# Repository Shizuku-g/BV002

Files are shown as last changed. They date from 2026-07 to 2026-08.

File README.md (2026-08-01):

# BV001

Design by nerdqaxeplus2(https://github.com/shufps/qaxe), change the ASIC to 1 x BM1373 AA (6.1TH/s SHA256)

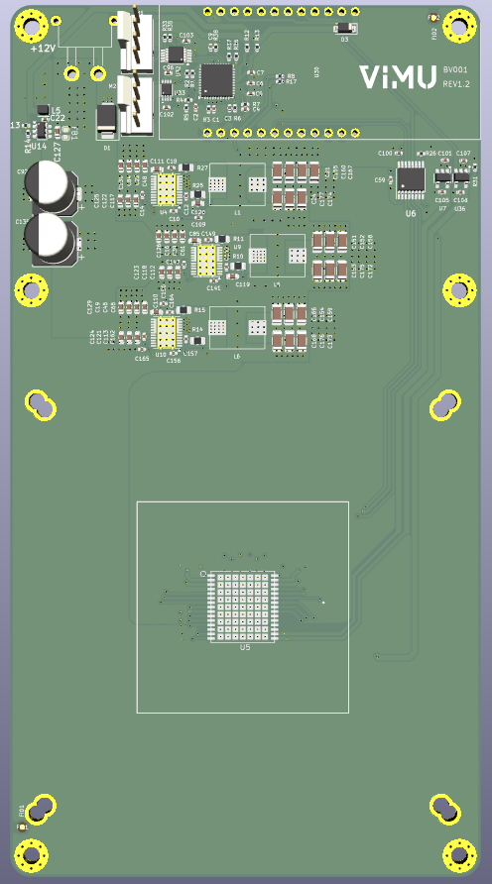
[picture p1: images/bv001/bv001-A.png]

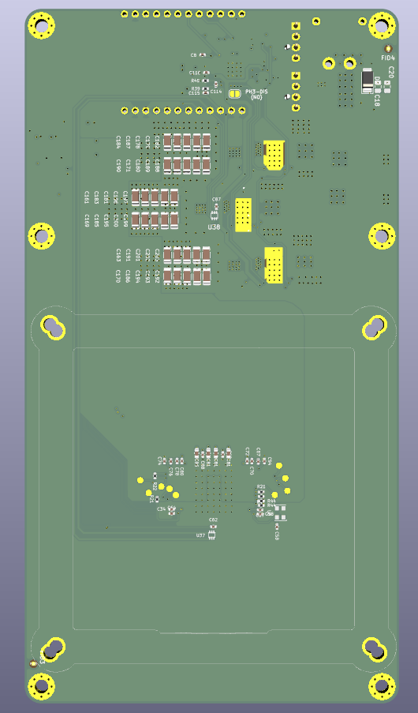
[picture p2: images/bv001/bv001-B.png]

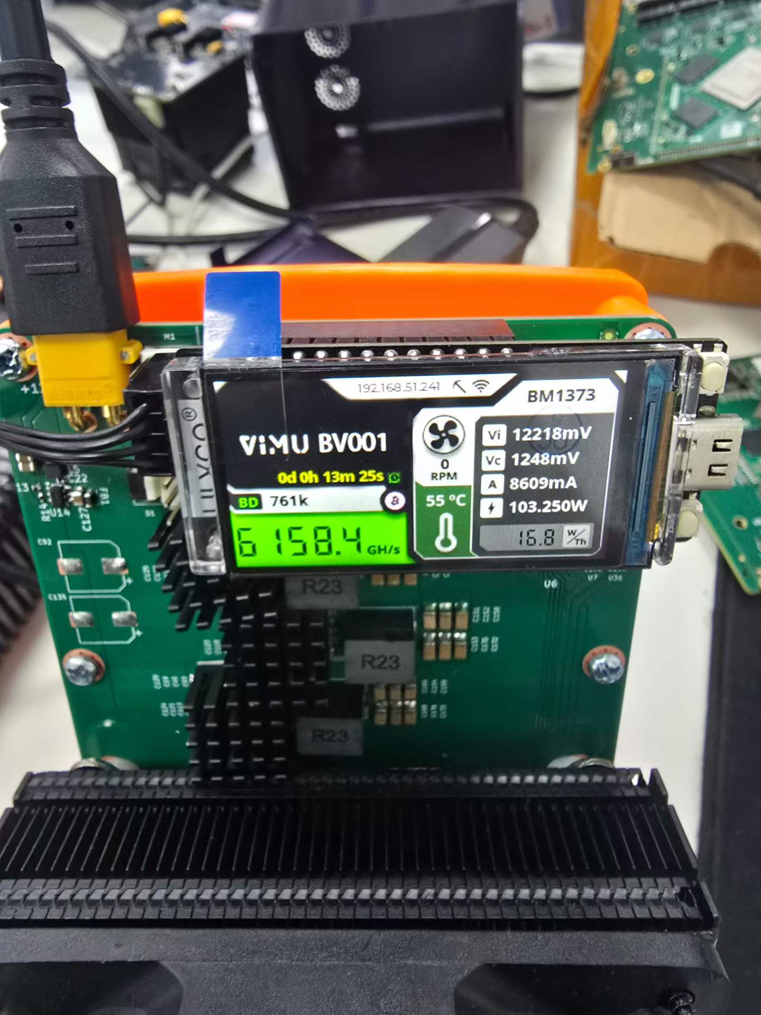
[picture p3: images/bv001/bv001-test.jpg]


Design tested and validated.  
Consume about 110 Watts on 12V for about 6.1TH/s (Vcore 1250mV, frequency 900Hz).  
Run at 735 MHz and 1140 mV, power wall around 78W, efficiency 14J/Th, 5TH/s.  
Use a 12V 15A PSU.

---

# BV002

**It is still an untested prototype! Don't build this expecting it to work at all.**

---

# BV003

**It is still an untested prototype! Don't build this expecting it to work at all.**

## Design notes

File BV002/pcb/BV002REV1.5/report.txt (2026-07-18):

信息: 正在处理符号 'C2:Capacitor_SMD:C_0603_1608Metric'。
信息: 正在处理符号 'C3:Capacitor_SMD:C_0603_1608Metric'。
信息: 正在处理符号 'C4:Capacitor_SMD:C_0402_1005Metric'。
信息: 正在处理符号 'C5:Capacitor_SMD:C_0402_1005Metric'。
信息: 正在处理符号 'C6:Capacitor_SMD:C_0402_1005Metric'。
信息: 正在处理符号 'C7:Capacitor_SMD:C_0402_1005Metric'。
信息: 正在处理符号 'C8:Capacitor_SMD:C_0805_2012Metric'。
信息: 正在处理符号 'C9:Capacitor_SMD:C_1206_3216Metric'。
信息: 正在处理符号 'C10:Capacitor_SMD:C_1206_3216Metric'。
信息: 正在处理符号 'C12:Capacitor_SMD:C_1206_3216Metric'。
信息: 正在处理符号 'C13:Capacitor_SMD:C_1206_3216Metric'。
信息: 正在处理符号 'C14:Capacitor_SMD:C_1206_3216Metric'。
信息: 正在处理符号 'C15:Capacitor_SMD:C_0402_1005Metric'。
信息: 正在处理符号 'C16:Capacitor_SMD:C_0402_1005Metric'。
信息: 正在处理符号 'C17:Capacitor_SMD:C_0402_1005Metric'。
信息: 正在处理符号 'C18:Capacitor_SMD:C_0402_1005Metric'。
信息: 正在处理符号 'C19:Capacitor_SMD:C_0402_1005Metric'。
信息: 正在处理符号 'C20:Capacitor_SMD:C_0402_1005Metric'。
信息: 正在处理符号 'C21:Capacitor_SMD:C_0402_1005Metric'。
信息: 正在处理符号 'C23:Capacitor_SMD:C_0402_1005Metric'。
信息: 正在处理符号 'C24:Capacitor_SMD:C_0603_1608Metric'。
信息: 正在处理符号 'C26:Capacitor_SMD:C_0603_1608Metric'。
信息: 正在处理符号 'C27:Capacitor_SMD:C_0402_1005Metric'。
信息: 正在处理符号 'C28:Capacitor_SMD:C_0402_1005Metric'。
信息: 正在处理符号 'C29:Capacitor_SMD:C_0402_1005Metric'。
信息: 正在处理符号 'C31:Capacitor_SMD:C_0402_1005Metric'。
信息: 正在处理符号 'C33:Capacitor_SMD:C_0402_1005Metric'。
信息: 正在处理符号 'C38:Capacitor_SMD:C_0402_1005Metric'。
信息: 正在处理符号 'C39:Capacitor_SMD:C_0402_1005Metric'。
信息: 正在处理符号 'C41:Capacitor_SMD:C_0805_2012Metric'。
信息: 正在处理符号 'C45:Capacitor_SMD:C_0402_1005Metric'。
信息: 正在处理符号 'C46:Capacitor_SMD:C_0402_1005Metric'。
信息: 正在处理符号 'C48:Capacitor_SMD:C_0402_1005Metric'。
信息: 正在处理符号 'C49:Capacitor_SMD:C_1206_3216Metric'。
信息: 正在处理符号 'C50:Capacitor_SMD:C_0402_1005Metric'。
信息: 正在处理符号 'C52:Capacitor_SMD:C_0402_1005Metric'。
信息: 正在处理符号 'C53:Capacitor_SMD:C_1206_3216Metric'。
信息: 正在处理符号 'C55:Capacitor_SMD:C_0402_1005Metric'。
信息: 正在处理符号 'C61:Capacitor_SMD:C_1206_3216Metric'。
信息: 正在处理符号 'C65:Capacitor_SMD:C_1206_3216Metric'。
信息: 正在处理符号 'C82:Capacitor_SMD:C_1206_3216Metric'。
信息: 正在处理符号 'C83:Capacitor_SMD:C_1206_3216Metric'。
信息: 正在处理符号 'C84:Capacitor_SMD:C_1206_3216Metric'。
信息: 正在处理符号 'C86:Capacitor_SMD:C_0402_1005Metric'。
信息: 正在处理符号 'C87:Capacitor_SMD:C_0402_1005Metric'。
信息: 正在处理符号 'C88:Capacitor_SMD:C_0402_1005Metric'。
信息: 正在处理符号 'C90:Capacitor_SMD:C_0402_1005Metric'。
信息: 正在处理符号 'C207:Capacitor_SMD:C_0402_1005Metric'。
信息: 正在处理符号 'D1:Diode_SMD:D_SMB'。
信息: 正在处理符号 'D3:Diode_SMD:D_SOD-123'。
信息: 正在处理符号 'H1:qaxe:MountingHole_3.2mm_M3_Pad_Via'。
信息: 正在处理符号 'H2:qaxe:MountingHole_3.2mm_M3_Pad_Via'。
信息: 正在处理符号 'H3:qaxe:MountingHole_3.2mm_M3_Pad_Via'。
信息: 正在处理符号 'H4:qaxe:MountingHole_3.2mm_M3_Pad_Via'。
信息: 正在处理符号 'H5:qaxe:MountingHole_3.2mm_M3_Pad_Via'。
信息: 正在处理符号 'H6:qaxe:MountingHole_3.2mm_M3_Pad_Via'。
信息: 正在处理符号 'J1:qaxe:XT30PW-M'。
信息: 正在处理符号 'L1:bitaxe:SLC1175-271MEC_COC'。
信息: 正在处理符号 'U1:bitaxe:polarity'。
信息: 正在处理符号 'C92:Capacitor_SMD:C_0402_1005Metric'。
信息: 正在处理符号 'L2:bitaxe:SLC1175-271MEC_COC'。
信息: 正在处理符号 'L4:Inductor_SMD:L_Changjiang_FTC201612S'。
信息: 正在处理符号 'M1:Connector:FanPinHeader_1x04_P2.54mm_Vertical'。
信息: 正在处理符号 'C94:Capacitor_SMD:C_0402_1005Metric'。
信息: 正在处理符号 'C96:Capacitor_SMD:C_0402_1005Metric'。
信息: 正在处理符号 'C98:Capacitor_SMD:C_0402_1005Metric'。
信息: 正在处理符号 'M2:Connector:FanPinHeader_1x04_P2.54mm_Vertical'。
信息: 正在处理符号 'NT1:bitaxe:NetTie-2_SMD_Pad0.2mmx1mm'。
信息: 正在处理符号 'NT2:bitaxe:NetTie-2_SMD_Pad0.2mmx1mm'。
信息: 正在处理符号 'C99:Capacitor_SMD:C_0402_1005Metric'。
信息: 正在处理符号 'C102:Capacitor_SMD:C_0402_1005Metric'。
信息: 正在处理符号 'C103:Capacitor_SMD:C_0402_1005Metric'。
信息: 正在处理符号 'C104:Capacitor_SMD:CP_Elec_6.3x5.9'。
信息: 正在处理符号 'C106:Capacitor_SMD:CP_Elec_6.3x5.9'。
信息: 正在处理符号 'C107:Capacitor_SMD:C_0402_1005Metric'。
信息: 正在处理符号 'R1:Resistor_SMD:R_0402_1005Metric'。
信息: 正在处理符号 'R2:Resistor_SMD:R_0805_2012Metric'。
信息: 正在处理符号 'C110:Capacitor_SMD:C_0603_1608Metric'。
信息: 正在处理符号 'C111:Capacitor_SMD:C_0603_1608Metric'。
信息: 正在处理符号 'C112:Capacitor_SMD:C_0603_1608Metric'。
信息: 正在处理符号 'C113:Capacitor_SMD:C_0603_1608Metric'。
信息: 正在处理符号 'C124:Capacitor_SMD:C_0603_1608Metric'。
信息: 正在处理符号 'C125:Capacitor_SMD:C_0603_1608Metric'。
信息: 正在处理符号 'C126:Capacitor_SMD:C_0603_1608Metric'。
信息: 正在处理符号 'C153:Capacitor_SMD:C_0402_1005Metric'。
信息: 正在处理符号 'R3:Resistor_SMD:R_0402_1005Metric'。
信息: 正在处理符号 'R5:Resistor_SMD:R_0402_1005Metric'。
信息: 正在处理符号 'R6:Resistor_SMD:R_0402_1005Metric'。
信息: 正在处理符号 'C155:Capacitor_SMD:C_0402_1005Metric'。
信息: 正在处理符号 'R8:Resistor_SMD:R_0402_1005Metric'。
信息: 正在处理符号 'R9:Resistor_SMD:R_0402_1005Metric'。
信息: 正在处理符号 'R10:Resistor_SMD:R_0402_1005Metric'。
信息: 正在处理符号 'C157:Capacitor_SMD:C_0402_1005Metric'。
信息: 正在处理符号 'R11:Resistor_SMD:R_0402_1005Metric'。
信息: 正在处理符号 'R12:Resistor_SMD:R_0402_1005Metric'。
信息: 正在处理符号 'C159:Capacitor_SMD:C_0402_1005Metric'。
信息: 正在处理符号 'R15:Resistor_SMD:R_0805_2012Metric'。
信息: 正在处理符号 'R17:Resistor_SMD:R_0402_1005Metric'。
信息: 正在处理符号 'R18:Resistor_SMD:R_0402_1005Metric'。
信息: 正在处理符号 'C161:Capacitor_SMD:C_0402_1005Metric'。
信息: 正在处理符号 'R23:Resistor_SMD:R_0402_1005Metric'。
信息: 正在处理符号 'R24:Resistor_SMD:R_0402_1005Metric'。
信息: 正在处理符号 'C163:Capacitor_SMD:C_0402_1005Metric'。
信息: 正在处理符号 'U2:Package_TO_SOT_SMD:SOT-583-8'。
信息: 正在处理符号 'R33:Resistor_SMD:R_0402_1005Metric'。
信息: 正在处理符号 'C164:Capacitor_SMD:C_0603_1608Metric'。
信息: 正在处理符号 'C165:Capacitor_SMD:C_0603_1608Metric'。
信息: 正在处理符号 'C167:Capacitor_SMD:C_0603_1608Metric'。
信息: 正在处理符号 'C168:Capacitor_SMD:C_0603_1608Metric'。
信息: 正在处理符号 'C171:Capacitor_SMD:C_0402_1005Metric'。
信息: 正在处理符号 'R25:Resistor_SMD:R_0402_1005Metric'。
信息: 正在处理符号 'R27:Resistor_SMD:R_0402_1005Metric'。
信息: 正在处理符号 'R28:Resistor_SMD:R_0402_1005Metric'。
信息: 正在处理符号 'C173:Capacitor_SMD:C_0603_1608Metric'。
信息: 正在处理符号 'C174:Capacitor_SMD:C_0603_1608Metric'。
信息: 正在处理符号 'C175:Capacitor_SMD:C_0603_1608Metric'。
信息: 正在处理符号 'C176:Capacitor_SMD:C_0603_1608Metric'。
信息: 正在处理符号 'C177:Capacitor_SMD:C_0402_1005Metric'。
信息: 正在处理符号 'R35:Resistor_SMD:R_0402_1005Metric'。
信息: 正在处理符号 'R43:Resistor_SMD:R_0402_1005Metric'。
信息: 正在处理符号 'R29:Resistor_SMD:R_0402_1005Metric'。
信息: 正在处理符号 'C178:Capacitor_SMD:C_0402_1005Metric'。
信息: 正在处理符号 'R30:Resistor_SMD:R_0402_1005Metric'。
信息: 正在处理符号 'U3:bitaxe:LQFN40-CLIP'。
信息: 正在处理符号 'U4:bitaxe:LQFN40-CLIP'。
信息: 正在处理符号 'C179:Capacitor_SMD:C_0402_1005Metric'。
信息: 正在处理符号 'C180:Capacitor_SMD:C_0402_1005Metric'。
信息: 正在处理符号 'C181:Capacitor_SMD:C_0402_1005Metric'。
信息: 正在处理符号 'C182:Capacitor_SMD:C_0402_1005Metric'。
信息: 正在处理符号 'C183:Capacitor_SMD:C_0402_1005Metric'。
信息: 正在处理符号 'R45:Resistor_SMD:R_0402_1005Metric'。
信息: 正在处理符号 'U5:Audio_Module:B1373CC'。
信息: 正在处理符号 'R46:Resistor_SMD:R_0402_1005Metric'。
信息: 正在处理符号 'C184:Capacitor_SMD:C_0402_1005Metric'。
信息: 正在处理符号 'R55:Resistor_SMD:R_0402_1005Metric'。
信息: 正在处理符号 'R56:Resistor_SMD:R_0402_1005Metric'。
信息: 正在处理符号 'R57:Resistor_SMD:R_0402_1005Metric'。
信息: 正在处理符号 'C185:Capacitor_SMD:C_0402_1005Metric'。
信息: 正在处理符号 'R58:Resistor_SMD:R_0402_1005Metric'。
信息: 正在处理符号 'R59:Resistor_SMD:R_0402_1005Metric'。
信息: 正在处理符号 'C186:Capacitor_SMD:C_0402_1005Metric'。
信息: 正在处理符号 'R60:Resistor_SMD:R_0402_1005Metric'。
信息: 正在处理符号 'R61:Resistor_SMD:R_0402_1005Metric'。
信息: 正在处理符号 'R31:Resistor_SMD:R_0402_1005Metric'。
信息: 正在处理符号 'C187:Capacitor_SMD:C_0402_1005Metric'。
信息: 正在处理符号 'C188:Capacitor_SMD:C_0402_1005Metric'。
信息: 正在处理符号 'C189:Capacitor_SMD:C_0402_1005Metric'。
信息: 正在处理符号 'C190:Capacitor_SMD:C_0402_1005Metric'。
信息: 正在处理符号 'C191:Capacitor_SMD:C_0402_1005Metric'。
信息: 正在处理符号 'C192:Capacitor_SMD:C_0402_1005Metric'。
信息: 正在处理符号 'C193:Capacitor_SMD:C_0402_1005Metric'。
信息: 正在处理符号 'C194:Capacitor_SMD:C_0402_1005Metric'。
信息: 正在处理符号 'C195:Capacitor_SMD:C_0402_1005Metric'。
信息: 正在处理符号 'R62:Resistor_SMD:R_0402_1005Metric'。
信息: 正在处理符号 'R63:Resistor_SMD:R_0402_1005Metric'。
信息: 正在处理符号 'R64:Resistor_SMD:R_0402_1005Metric'。
信息: 正在处理符号 'R65:Resistor_SMD:R_0402_1005Metric'。
信息: 正在处理符号 'R66:Resistor_SMD:R_0402_1005Metric'。
信息: 正在处理符号 'R67:Resistor_SMD:R_0402_1005Metric'。
信息: 正在处理符号 'R68:Resistor_SMD:R_0402_1005Metric'。
信息: 正在处理符号 'R69:Resistor_SMD:R_0402_1005Metric'。
信息: 正在处理符号 'R70:Resistor_SMD:R_0402_1005Metric'。
信息: 正在处理符号 'R71:Resistor_SMD:R_0402_1005Metric'。
信息: 正在处理符号 'R72:Resistor_SMD:R_0402_1005Metric'。
信息: 正在处理符号 'C206:Capacitor_SMD:C_0402_1005Metric'。
信息: 正在处理符号 'U6:Audio_Module:B1373CC'。
信息: 正在处理符号 'U7:Package_SO:TSSOP-16_4.4x5mm_P0.65mm'。
信息: 正在处理符号 'U8:Oscillator:Oscillator_SMD_EuroQuartz_XO32-4Pin_3.2x2.5mm'。
信息: 正在处理符号 'U9:Oscillator:Oscillator_SMD_EuroQuartz_XO32-4Pin_3.2x2.5mm'。
信息: 正在处理符号 'U10:Package_TO_SOT_SMD:SOT-23-5'。
信息: 正在处理符号 'U11:Package_TO_SOT_SMD:SOT-23-5'。
信息: 正在处理符号 'U12:Package_TO_SOT_SMD:SOT-23-5'。
信息: 正在处理符号 'U13:Package_TO_SOT_SMD:SOT-23-5'。
信息: 正在处理符号 'U17:Package_SO:TSSOP-14_4.4x5mm_P0.65mm'。
信息: 正在处理符号 'U30:myfootprints:T-Display-S3'。
信息: 正在处理符号 'U32:Package_SO:MSOP-10_3x3mm_P0.5mm'。
信息: 正在处理符号 'U33:Package_SO:VSSOP-8_2.3x2mm_P0.5mm'。
信息: 正在处理符号 'U37:qaxe:TMP1075-DRL'。
添加网络 Net-(U5-VDD2_0)。
将 C92 引脚 2 从 Net-(A1-VDD2_0) 重新连接到了 Net-(U5-VDD2_0)。
将 C98 引脚 1 从 Net-(A1-VDD2_0) 重新连接到了 Net-(U5-VDD2_0)。
添加网络 Net-(U5-VDD1_0)。
将 C98 引脚 2 从 Net-(A1-VDD3_0) 重新连接到了 Net-(U5-VDD1_0)。
将 C107 引脚 1 从 Net-(A1-VDD3_0) 重新连接到了 Net-(U5-VDD1_0)。
将 C107 引脚 2 从 GND_1 重新连接到了 GND。
将 C153 引脚 1 从 GND_1 重新连接到了 VDD。
添加网络 Net-(U6-VDD3_0)。
将 C153 引脚 2 从 Net-(A4-VDD1_0) 重新连接到了 Net-(U6-VDD3_0)。
添加网络 Net-(U6-VDD2_0)。
将 C155 引脚 2 从 Net-(A4-VDD2_0) 重新连接到了 Net-(U6-VDD2_0)。
将 C155 引脚 1 从 Net-(A4-VDD1_0) 重新连接到了 Net-(U6-VDD3_0)。
添加网络 Net-(U6-VDDIO_08_0)。
将 C157 引脚 1 从 /BM1366/0V8_1 重新连接到了 Net-(U6-VDDIO_08_0)。
添加网络 Net-(U6-VDD1_0)。
将 C159 引脚 2 从 Net-(A4-VDD3_0) 重新连接到了 Net-(U6-VDD1_0)。
将 C159 引脚 1 从 Net-(A4-VDD2_0) 重新连接到了 Net-(U6-VDD2_0)。
添加网络 Net-(U6-VDDIO_12_0)。
将 C161 引脚 1 从 1V2_1 重新连接到了 Net-(U6-VDDIO_12_0)。
将 C163 引脚 2 从 VDD 重新连接到了 GND。
将 C163 引脚 1 从 Net-(A4-VDD3_0) 重新连接到了 Net-(U6-VDD1_0)。
将 C171 引脚 1 从 VDD 重新连接到了 GND。
添加网络 Net-(U6-VDD1_1)。
将 C171 引脚 2 从 Net-(A4-VDD3_1) 重新连接到了 Net-(U6-VDD1_1)。
添加网络 Net-(U6-VDD2_1)。
将 C177 引脚 2 从 Net-(A4-VDD2_1) 重新连接到了 Net-(U6-VDD2_1)。
将 C177 引脚 1 从 Net-(A4-VDD3_1) 重新连接到了 Net-(U6-VDD1_1)。
将 C178 引脚 2 从 Net-(A3-VDD2_1) 重新连接到了 GND_1。
添加网络 Net-(U5-VDD3_1)。
将 C178 引脚 1 从 Net-(A3-VDD3_1) 重新连接到了 Net-(U5-VDD3_1)。
将 C183 引脚 1 从 Net-(A4-VDD2_1) 重新连接到了 Net-(U6-VDD2_1)。
添加网络 Net-(U6-VDD3_1)。
将 C183 引脚 2 从 Net-(A4-VDD1_1) 重新连接到了 Net-(U6-VDD3_1)。
添加网络 Net-(U5-VDD2_1)。
将 C184 引脚 1 从 Net-(A3-VDD2_1) 重新连接到了 Net-(U5-VDD2_1)。
将 C184 引脚 2 从 Net-(A3-VDD1_1) 重新连接到了 Net-(U5-VDD3_1)。
将 C185 引脚 2 从 GND_1 重新连接到了 VDD。
将 C185 引脚 1 从 Net-(A4-VDD1_1) 重新连接到了 Net-(U6-VDD3_1)。
添加网络 Net-(U5-VDD1_1)。
将 C186 引脚 1 从 Net-(A3-VDD1_1) 重新连接到了 Net-(U5-VDD1_1)。
将 C186 引脚 2 从 GND 重新连接到了 Net-(U5-VDD2_1)。
添加了 C195 (封装 'Capacitor_SMD:C_0402_1005Metric')。
已将 REF** 的位号更改为 C195。
已将 C195 的值从 'C_0402_1005Metric' 修改为 '1uF'。
将 C195 符号分配从  更新到 /4cf9c075-d009-4c35-9949-adda70ae20c7/5cac742f-71c1-4b5f-9255-c0933d732803。
已更新 C195 个字段。
已将 C195 图纸名称更新为 '/BM1366/'。
已将 C195 图纸文件更新为 'bm1366.kicad_sch'。
已将 C195 封装筛选规则更新为 'C_*'。
将 C195 引脚 1 连接到了 GND。
将 C195 引脚 2 连接到了 Net-(U5-VDD1_1)。
已更新 C195 单元的元数据。
已更新 L1 个字段。
添加网络 Net-(U6-RI)。
将 R24 引脚 1 从 Net-(A6-RI) 重新连接到了 Net-(U6-RI)。
添加网络 Net-(U5-LITE_PAD)。
将 R28 引脚 1 从 Net-(A1-LITE_PAD) 重新连接到了 Net-(U5-LITE_PAD)。
添加了 R30 (封装 'Resistor_SMD:R_0402_1005Metric')。
已将 REF** 的位号更改为 R30。
已将 R30 的值从 'R_0402_1005Metric' 修改为 '10k'。
将 R30 符号分配从  更新到 /4cf9c075-d009-4c35-9949-adda70ae20c7/908a538c-9adf-4183-acd7-97a39e0809e3。
已更新 R30 个字段。
已将 R30 图纸名称更新为 '/BM1366/'。
已将 R30 图纸文件更新为 'bm1366.kicad_sch'。
已将 R30 封装筛选规则更新为 'R_*'。
将 R30 引脚 2 连接到了 /BM1366/Level Shifter/NRSTI。
添加网络 Net-(R30-Pad1)。
将 R30 引脚 1 连接到了 Net-(R30-Pad1)。
已更新 R30 单元的元数据。
添加了 R31 (封装 'Resistor_SMD:R_0402_1005Metric')。
已将 REF** 的位号更改为 R31。
已将 R31 的值从 'R_0402_1005Metric' 修改为 '10k'。
将 R31 符号分配从  更新到 /4cf9c075-d009-4c35-9949-adda70ae20c7/2c4814b4-0640-43ad-82f6-ef1a9cbd42a7。
已更新 R31 个字段。
已将 R31 图纸名称更新为 '/BM1366/'。
已将 R31 图纸文件更新为 'bm1366.kicad_sch'。
已将 R31 封装筛选规则更新为 'R_*'。
添加网络 Net-(R31-Pad2)。
将 R31 引脚 2 连接到了 Net-(R31-Pad2)。
添加网络 /BM1366/NRSTO。
将 R31 引脚 1 连接到了 /BM1366/NRSTO。
已更新 R31 单元的元数据。
添加网络 Net-(U6-LITE_PAD)。
将 R43 引脚 1 从 Net-(A4-LITE_PAD) 重新连接到了 Net-(U6-LITE_PAD)。
将 R45 引脚 2 从 /BM1366/Level Shifter/NRSTI2 重新连接到了 /BM1366/NRSTO。
添加了 U5 (封装 'Audio_Module:B1373CC')。
已将 REF** 的位号更改为 U5。
已将 U5 的值从 'B1373CC' 修改为 '~'。
将 U5 符号分配从  更新到 /4cf9c075-d009-4c35-9949-adda70ae20c7/0b000a2c-9d47-4e33-ba98-7468ad7a44d6。
已将 U5 图纸名称更新为 '/BM1366/'。
已将 U5 图纸文件更新为 'bm1366.kicad_sch'。
将 U5 引脚 32 连接到了 GND。
将 U5 引脚 15 连接到了 1V2_0。
将 U5 引脚 32 连接到了 GND。
添加网络 unconnected-(U5-NC-Pad12)。
将 U5 引脚 12 连接到了 unconnected-(U5-NC-Pad12)。
将 U5 引脚 32 连接到了 GND。
将 U5 引脚 31 连接到了 GND_1。
将 U5 引脚 31 连接到了 GND_1。
将 U5 引脚 32 连接到了 GND。
将 U5 引脚 31 连接到了 GND_1。
将 U5 引脚 31 连接到了 GND_1。
将 U5 引脚 31 连接到了 GND_1。
将 U5 引脚 31 连接到了 GND_1。
添加网络 unconnected-(U5-PIN_MODE-Pad11)。
将 U5 引脚 11 连接到了 unconnected-(U5-PIN_MODE-Pad11)。
将 U5 引脚 31 连接到了 GND_1。
将 U5 引脚 31 连接到了 GND_1。
将 U5 引脚 32 连接到了 GND。
将 U5 引脚 32 连接到了 GND。
将 U5 引脚 31 连接到了 GND_1。
将 U5 引脚 31 连接到了 GND_1。
将 U5 引脚 31 连接到了 GND_1。
将 U5 引脚 32 连接到了 GND。
添加网络 unconnected-(U5-VSS-Pad4)。
将 U5 引脚 4 连接到了 unconnected-(U5-VSS-Pad4)。
将 U5 引脚 32 连接到了 GND。
将 U5 引脚 7 连接到了 /BM1366/RO。
将 U5 引脚 32 连接到了 GND。
将 U5 引脚 32 连接到了 GND。
将 U5 引脚 32 连接到了 GND。
添加网络 unconnected-(U5-NC-Pad19)。
将 U5 引脚 19 连接到了 unconnected-(U5-NC-Pad19)。
将 U5 引脚 28 连接到了 Net-(U5-VDD3_1)。
添加网络 unconnected-(U5-NC-Pad20)。
将 U5 引脚 20 连接到了 unconnected-(U5-NC-Pad20)。
将 U5 引脚 31 连接到了 GND_1。
将 U5 引脚 32 连接到了 GND。
将 U5 引脚 31 连接到了 GND_1。
将 U5 引脚 32 连接到了 GND。
将 U5 引脚 22 连接到了 /BM1366/Level Shifter/BI。
将 U5 引脚 32 连接到了 GND。
将 U5 引脚 29 连接到了 Net-(U5-VDD2_1)。
将 U5 引脚 31 连接到了 GND_1。
将 U5 引脚 32 连接到了 GND。
将 U5 引脚 32 连接到了 GND。
将 U5 引脚 31 连接到了 GND_1。
将 U5 引脚 32 连接到了 GND。
将 U5 引脚 31 连接到了 GND_1。
添加网络 unconnected-(U5-NC-Pad21)。
将 U5 引脚 21 连接到了 unconnected-(U5-NC-Pad21)。
将 U5 引脚 32 连接到了 GND。
将 U5 引脚 31 连接到了 GND_1。
将 U5 引脚 16 连接到了 1V2_0。
将 U5 引脚 31 连接到了 GND_1。
将 U5 引脚 31 连接到了 GND_1。
将 U5 引脚 8 连接到了 /BM1366/CLKI。
将 U5 引脚 13 连接到了 GND。
将 U5 引脚 31 连接到了 GND_1。
将 U5 引脚 32 连接到了 GND。
将 U5 引脚 32 连接到了 GND。
将 U5 引脚 6 连接到了 /BM1366/CI。
将 U5 引脚 32 连接到了 GND。
将 U5 引脚 31 连接到了 GND_1。
将 U5 引脚 23 连接到了 /BM1366/Level Shifter/CLKI。
将 U5 引脚 17 连接到了 /BM1366/0V8_0。
将 U5 引脚 32 连接到了 GND。
将 U5 引脚 31 连接到了 GND_1。
将 U5 引脚 31 连接到了 GND_1。
将 U5 引脚 31 连接到了 GND_1。
将 U5 引脚 32 连接到了 GND。
将 U5 引脚 26 连接到了 /BM1366/Level Shifter/NRSTI。
将 U5 引脚 31 连接到了 GND_1。
将 U5 引脚 32 连接到了 GND。
将 U5 引脚 3 连接到了 Net-(U5-VDD3_0)。
将 U5 引脚 32 连接到了 GND。
将 U5 引脚 32 连接到了 GND。
将 U5 引脚 31 连接到了 GND_1。
将 U5 引脚 27 连接到了 Net-(R30-Pad1)。
将 U5 引脚 14 连接到了 /BM1366/0V8_0。
将 U5 引脚 31 连接到了 GND_1。
将 U5 引脚 32 连接到了 GND。
将 U5 引脚 25 连接到了 /BM1366/Level Shifter/CI。
将 U5 引脚 1 连接到了 Net-(U5-VDD1_0)。
将 U5 引脚 32 连接到了 GND。
将 U5 引脚 31 连接到了 GND_1。
将 U5 引脚 31 连接到了 GND_1。
将 U5 引脚 32 连接到了 GND。
将 U5 引脚 32 连接到了 GND。
将 U5 引脚 9 连接到了 /BM1366/BI。
将 U5 引脚 31 连接到了 GND_1。
将 U5 引脚 24 连接到了 /BM1366/Level Shifter/RO。
将 U5 引脚 32 连接到了 GND。
将 U5 引脚 30 连接到了 Net-(U5-VDD1_1)。
将 U5 引脚 10 连接到了 Net-(U5-LITE_PAD)。
将 U5 引脚 2 连接到了 Net-(U5-VDD2_0)。
将 U5 引脚 5 连接到了 /BM1366/RST_N。
将 U5 引脚 32 连接到了 GND。
将 U5 引脚 31 连接到了 GND_1。
将 U5 引脚 18 连接到了 GND。
已更新 U5 单元的元数据。
添加了 C90 (封装 'Capacitor_SMD:C_0402_1005Metric')。
添加了 U6 (封装 'Audio_Module:B1373CC')。
已将 REF** 的位号更改为 U6。
已将 U6 的值从 'B1373CC' 修改为 '~'。
将 U6 符号分配从  更新到 /4cf9c075-d009-4c35-9949-adda70ae20c7/fd68f0f3-a1bd-4385-ae0e-bafe37af180e。
已将 U6 图纸名称更新为 '/BM1366/'。
已将 U6 图纸文件更新为 'bm1366.kicad_sch'。
将 U6 引脚 31 连接到了 VDD。
将 U6 引脚 29 连接到了 Net-(U6-VDD2_1)。
将 U6 引脚 31 连接到了 VDD。
将 U6 引脚 17 连接到了 /BM1366/0V8_1。
将 U6 引脚 16 连接到了 1V2_1。
添加网络 unconnected-(U6-RST-Pad26)。
将 U6 引脚 26 连接到了 unconnected-(U6-RST-Pad26)。
将 U6 引脚 1 连接到了 Net-(U6-VDD1_0)。
将 U6 引脚 32 连接到了 GND_1。
添加网络 unconnected-(U6-PIN_MODE-Pad11)。
将 U6 引脚 11 连接到了 unconnected-(U6-PIN_MODE-Pad11)。
将 U6 引脚 32 连接到了 GND_1。
将 U6 引脚 32 连接到了 GND_1。
将 U6 引脚 31 连接到了 VDD。
将 U6 引脚 32 连接到了 GND_1。
添加网络 unconnected-(U6-NC-Pad21)。
将 U6 引脚 21 连接到了 unconnected-(U6-NC-Pad21)。
将 U6 引脚 31 连接到了 VDD。
将 U6 引脚 32 连接到了 GND_1。
将 U6 引脚 32 连接到了 GND_1。
将 U6 引脚 32 连接到了 GND_1。
将 U6 引脚 32 连接到了 GND_1。
将 U6 引脚 31 连接到了 VDD。
将 U6 引脚 31 连接到了 VDD。
将 U6 引脚 32 连接到了 GND_1。
将 U6 引脚 10 连接到了 Net-(U6-LITE_PAD)。
将 U6 引脚 32 连接到了 GND_1。
将 U6 引脚 32 连接到了 GND_1。
添加网络 /BM1366/BO。
将 U6 引脚 9 连接到了 /BM1366/BO。
将 U6 引脚 32 连接到了 GND_1。
将 U6 引脚 32 连接到了 GND_1。
将 U6 引脚 5 连接到了 /BM1366/NRSTO。
将 U6 引脚 31 连接到了 VDD。
添加网络 unconnected-(U6-NC-Pad20)。
将 U6 引脚 20 连接到了 unconnected-(U6-NC-Pad20)。
将 U6 引脚 31 连接到了 VDD。
将 U6 引脚 31 连接到了 VDD。
将 U6 引脚 2 连接到了 Net-(U6-VDD2_0)。
将 U6 引脚 32 连接到了 GND_1。
添加网络 unconnected-(U6-NC-Pad12)。
将 U6 引脚 12 连接到了 unconnected-(U6-NC-Pad12)。
将 U6 引脚 31 连接到了 VDD。
将 U6 引脚 31 连接到了 VDD。
将 U6 引脚 31 连接到了 VDD。
将 U6 引脚 31 连接到了 VDD。
将 U6 引脚 32 连接到了 GND_1。
将 U6 引脚 32 连接到了 GND_1。
添加网络 unconnected-(U6-VSS-Pad27)。
将 U6 引脚 27 连接到了 unconnected-(U6-VSS-Pad27)。
将 U6 引脚 32 连接到了 GND_1。
将 U6 引脚 24 连接到了 Net-(U6-RI)。
将 U6 引脚 13 连接到了 GND_1。
将 U6 引脚 31 连接到了 VDD。
将 U6 引脚 32 连接到了 GND_1。
将 U6 引脚 32 连接到了 GND_1。
将 U6 引脚 31 连接到了 VDD。
将 U6 引脚 32 连接到了 GND_1。
将 U6 引脚 15 连接到了 Net-(U6-VDDIO_12_0)。
将 U6 引脚 31 连接到了 VDD。
添加网络 unconnected-(U6-NC-Pad19)。
将 U6 引脚 19 连接到了 unconnected-(U6-NC-Pad19)。
将 U6 引脚 32 连接到了 GND_1。
将 U6 引脚 31 连接到了 VDD。
将 U6 引脚 32 连接到了 GND_1。
将 U6 引脚 31 连接到了 VDD。
将 U6 引脚 32 连接到了 GND_1。
将 U6 引脚 14 连接到了 Net-(U6-VDDIO_08_0)。
将 U6 引脚 32 连接到了 GND_1。
添加网络 unconnected-(U6-BO-Pad22)。
将 U6 引脚 22 连接到了 unconnected-(U6-BO-Pad22)。
将 U6 引脚 31 连接到了 VDD。
将 U6 引脚 3 连接到了 Net-(U6-VDD3_0)。
将 U6 引脚 4 连接到了 Net-(R31-Pad2)。
添加网络 /BM1366/CLKO。
将 U6 引脚 8 连接到了 /BM1366/CLKO。
将 U6 引脚 32 连接到了 GND_1。
将 U6 引脚 32 连接到了 GND_1。
添加网络 unconnected-(U6-CLKO-Pad23)。
将 U6 引脚 23 连接到了 unconnected-(U6-CLKO-Pad23)。
添加网络 /BM1366/CO。
将 U6 引脚 6 连接到了 /BM1366/CO。
将 U6 引脚 32 连接到了 GND_1。
将 U6 引脚 31 连接到了 VDD。
将 U6 引脚 31 连接到了 VDD。
将 U6 引脚 30 连接到了 Net-(U6-VDD1_1)。
将 U6 引脚 31 连接到了 VDD。
将 U6 引脚 31 连接到了 VDD。
添加网络 /BM1366/RI。
将 U6 引脚 7 连接到了 /BM1366/RI。
将 U6 引脚 31 连接到了 VDD。
将 U6 引脚 18 连接到了 GND_1。
将 U6 引脚 31 连接到了 VDD。
将 U6 引脚 32 连接到了 GND_1。
将 U6 引脚 32 连接到了 GND_1。
将 U6 引脚 28 连接到了 Net-(U6-VDD3_1)。
将 U6 引脚 31 连接到了 VDD。
将 U6 引脚 32 连接到了 GND_1。
将 U6 引脚 31 连接到了 VDD。
将 U6 引脚 31 连接到了 VDD。
将 U6 引脚 31 连接到了 VDD。
将 U6 引脚 31 连接到了 VDD。
将 U6 引脚 32 连接到了 GND_1。
将 U6 引脚 32 连接到了 GND_1。
添加网络 unconnected-(U6-CO-Pad25)。
将 U6 引脚 25 连接到了 unconnected-(U6-CO-Pad25)。
将 U6 引脚 31 连接到了 VDD。
已更新 U6 单元的元数据。
已将 REF** 的位号更改为 C90。
已将 C90 的值从 'C_0402_1005Metric' 修改为 '1uF'。
将 C90 符号分配从  更新到 /4cf9c075-d009-4c35-9949-adda70ae20c7/64dd4181-b475-4721-92ac-613f6684715e。
已更新 C90 个字段。
已将 C90 图纸名称更新为 '/BM1366/'。
已将 C90 图纸文件更新为 'bm1366.kicad_sch'。
已将 C90 封装筛选规则更新为 'C_*'。
将 C90 引脚 1 连接到了 GND_1。
添加网络 Net-(U5-VDD3_0)。
将 C90 引脚 2 连接到了 Net-(U5-VDD3_0)。
已更新 C90 单元的元数据。
将 C92 引脚 1 从 Net-(A1-VDD1_0) 重新连接到了 Net-(U5-VDD3_0)。
将过孔从 Net-(A3-VDD1_1) 重新连接到了 Net-(U5-VDD1_1)。
将过孔从 Net-(A3-VDD2_1) 重新连接到了 Net-(U5-VDD2_1)。
将过孔从 Net-(A3-VDD3_1) 重新连接到了 Net-(U5-VDD3_1)。
将过孔从 Net-(A6-RI) 重新连接到了 Net-(U6-RI)。
将过孔从 Net-(A4-VDD1_0) 重新连接到了 Net-(U6-VDD3_0)。
将过孔从 Net-(A4-VDD2_0) 重新连接到了 Net-(U6-VDD2_0)。
将过孔从 Net-(A4-VDD3_0) 重新连接到了 Net-(U6-VDD1_0)。
将过孔从 Net-(A1-VDD3_0) 重新连接到了 Net-(U5-VDD1_0)。
将过孔从 Net-(A1-VDD2_0) 重新连接到了 Net-(U5-VDD2_0)。
将过孔从 Net-(A1-VDD1_0) 重新连接到了 Net-(U5-VDD3_0)。
将过孔从 Net-(A1-LITE_PAD) 重新连接到了 Net-(U5-LITE_PAD)。
将过孔从 Net-(A4-LITE_PAD) 重新连接到了 Net-(U6-LITE_PAD)。
将过孔从 Net-(A4-VDD1_1) 重新连接到了 Net-(U6-VDD3_1)。
将过孔从 Net-(A4-VDD2_1) 重新连接到了 Net-(U6-VDD2_1)。
将过孔从 Net-(A4-VDD3_1) 重新连接到了 Net-(U6-VDD1_1)。
移除未使用的网络 0V8。
移除未使用的网络 1V2。
移除未使用的网络 BI。
移除未使用的网络 BO。
移除未使用的网络 CI。
移除未使用的网络 CLK。
移除未使用的网络 CLKI。
移除未使用的网络 CO。
移除未使用的网络 NC。
移除未使用的网络 RI。
移除未使用的网络 RO。
移除未使用的网络 RST。
移除未使用的网络 RSTI。
移除未使用的网络 VDD1_0。
移除未使用的网络 VDD1_1。
移除未使用的网络 VDD2_0。
移除未使用的网络 VDD2_1。
移除未使用的网络 VDD3_0。
移除未使用的网络 VDD3_1。
警告: 过孔连接到未知网络 (Net-(A4-NRSTO))。
警告: 过孔连接到未知网络 (Net-(A3-LITE_PAD))。
警告: 过孔连接到未知网络 (Net-(A1-VDD3_1))。
警告: 过孔连接到未知网络 (Net-(A1-VDD2_1))。
警告: 过孔连接到未知网络 (Net-(A1-VDD1_1))。
警告: 过孔连接到未知网络 (Net-(A6-VDD3_0))。
警告: 过孔连接到未知网络 (Net-(A6-VDD2_0))。
警告: 过孔连接到未知网络 (Net-(A6-VDD1_0))。
警告: 过孔连接到未知网络 (Net-(A1-NRSTO))。
警告: 过孔连接到未知网络 (Net-(A6-LITE_PAD))。
错误: U7 的焊盘 17 在 Package_SO:TSSOP-16_4.4x5mm_P0.65mm 中未找到。

信息: 总计警告: 10, 错误: 1。

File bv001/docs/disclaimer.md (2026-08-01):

# BV001 免责声明

**请在使用、制造或修改 BV001 之前仔细阅读本文档。**

## 1. 无担保声明

BV001 为开源硬件设计，按 **「现状」（AS IS）** 提供，不提供任何明示或暗示的担保，包括但不限于：

- 适销性
- 特定用途适用性
- 不侵权
- 性能、算力、功耗或效率达到 README / 文档中所述数值

文档中的测试数据来自特定环境下的样机测试，仅供参考；实际结果会因元器件批次、组装质量、散热条件、电源品质及固件版本而有所不同。

## 2. 风险自负

制造、焊接、上电、调试及运行 BV001 的全部风险由使用者自行承担。包括但不限于：

- **人身伤害**：高温烫伤、工具操作不当等
- **财产损失**：元器件损坏、PCB 烧毁、电源或周边设备损坏
- **火灾风险**：大电流、散热不足或装配错误可能引发过热

使用者应具备相应的电子工程知识与操作经验。如无相关经验，请勿自行制造或上电测试。

## 3. 电气安全

- BV001 工作于 **12 V 大电流** 环境，请使用合格、足功率的电源（建议 12 V / 15 A）
- 上电前检查极性、短路及散热安装
- 请勿在无人看管的情况下长时间运行
- 建议在通风良好、非易燃环境中使用

## 4. 法律与合规

- **加密货币挖矿** 在部分国家或地区可能受到限制或禁止，使用者须自行了解并遵守当地法律法规
- 用电应符合当地电气安全规范；高负载长时间运行产生的电费由使用者自行承担
- 本项目不提供任何投资、收益或挖矿盈利方面的建议或保证

## 5. 第三方设计与知识产权

BV001 基于 [nerdqaxeplus2 / qaxe](https://github.com/shufps/qaxe) 修改而来。使用者须同时遵守：

- 本仓库的 [LICENSE](../../LICENSE)（GNU GPL v3）
- 上游项目及其依赖组件各自的许可条款

本项目的作者与贡献者不对因使用、修改或再分发本设计而产生的任何第三方知识产权纠纷负责。

## 6. 元器件与供应链

- BOM 中的供应商、料号仅供参考，不保证现货、价格或品质
- 元器件替代可能导致性能下降、不稳定或损坏，替代方案需自行评估
- BM1373 等专用芯片的获取与真伪鉴别由使用者自行负责

## 7. 固件与软件

固件、矿池配置及配套软件可能独立于硬件设计更新。作者不保证与所有固件版本兼容，也不对固件缺陷、网络连接或矿池服务中断负责。

## 8. 责任限制

在法律允许的最大范围内，BV001 的作者、贡献者及分发者不对因使用或无法使用本设计而导致的任何直接、间接、附带、特殊或 consequential 损害承担责任，包括但不限于数据丢失、设备损坏、业务中断或利润损失。

## 9. 接受条款

下载、复制、制造、修改或运行 BV001 即表示您已阅读、理解并同意本免责声明的全部内容。如不同意，请立即停止使用本设计及相关资料。

---

*最后更新：2026-08-01*

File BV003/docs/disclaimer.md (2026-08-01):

# BV003 免责声明

**请在使用、制造或修改 BV003 之前仔细阅读本文档。**

## ⚠ 特别警告：未验证原型

BV003 为 **未经实机验证的原型设计**。README 已明确说明：

> *It is still an untested prototype! Don't build this expecting it to work at all.*

**请勿投入量产或期望其直接可用。** 设计可能存在原理图错误、布局缺陷、电源/散热不足、ASIC 互联问题等，上电可能导致元器件损坏甚至安全隐患。如需可参考的成熟方案，请使用已验证的 **BV001**。

---

## 1. 无担保声明

BV003 为开源硬件设计，按 **「现状」（AS IS）** 提供，不提供任何明示或暗示的担保，包括但不限于：

- 适销性
- 特定用途适用性
- 不侵权
- 设计完整性、可制造性或可运行性
- 性能、算力、功耗或效率达到任何预期数值

本设计 **没有任何** 经过验证的测试数据；文档或原理图中的参数均不应被视为承诺。

## 2. 风险自负

制造、焊接、上电、调试及运行 BV003 的全部风险由使用者自行承担。包括但不限于：

- **人身伤害**：高温烫伤、工具操作不当等
- **财产损失**：元器件损坏、PCB 烧毁、电源或周边设备损坏；**原型设计导致的全板报废风险更高**
- **火灾风险**：大电流、散热不足、设计缺陷或装配错误可能引发过热

使用者应具备相应的电子工程知识与操作经验。如无相关经验，**请勿** 自行制造或上电测试。

## 3. 电气安全

- BV003 为多 ASIC、多相电源设计，预期工作于 **12 V 大电流** 环境，对电源与散热要求高于单芯片方案
- 上电前须自行完成设计审查、DRC/ERC 检查、短路与极性检查
- 首次上电建议使用限流电源，并在可监控环境下进行
- 请勿在无人看管的情况下长时间运行
- 建议在通风良好、非易燃环境中使用

## 4. 法律与合规

- **加密货币挖矿** 在部分国家或地区可能受到限制或禁止，使用者须自行了解并遵守当地法律法规
- 用电应符合当地电气安全规范；高负载长时间运行产生的电费由使用者自行承担
- 本项目不提供任何投资、收益或挖矿盈利方面的建议或保证

## 5. 第三方设计与知识产权

BV003 基于 [NerdOCTAXE-Gamma](https://github.com/Patsch91/NerdOCTAXE-Gamma) 修改而来。该项目本身源自 NerdQaxe 生态，采用 **CERN-OHL-S-2.0** 许可。使用者须同时遵守：

- 本仓库的 [LICENSE](../../LICENSE)（GNU GPL v3）
- [NerdOCTAXE-Gamma](https://github.com/Patsch91/NerdOCTAXE-Gamma) 及其上游（如 [NerdQAxe+](https://github.com/shufps/qaxe)、[ESP-Miner-NerdQAxe+](https://github.com/shufps/ESP-Miner-NerdQAxe-plus)）各自的许可条款

本项目的作者与贡献者不对因使用、修改或再分发本设计而产生的任何第三方知识产权纠纷负责。

## 6. 元器件与供应链

- BOM（如已提供）中的供应商、料号仅供参考，不保证现货、价格或品质
- 4× BM1373 及 TPS546 等关键器件成本与获取难度较高，替代可能导致严重不稳定
- 元器件替代需自行评估；**在未验证的设计上使用替代料风险极大**

## 7. 固件与软件

上游 [NerdOCTAXE-Gamma](https://github.com/Patsch91/NerdOCTAXE-Gamma) 使用修改版 [ESP-Miner-NerdQAxe+](https://github.com/shufps/ESP-Miner-NerdQAxe-plus)（AxeOS）。BV003 因 ASIC 型号与数量不同，**不能直接沿用上游固件**；多芯片驱动、W5500 网络等功能 **尚未验证**。作者不保证与任何固件版本兼容，也不对固件缺陷、网络连接或矿池服务中断负责。自行移植固件前须充分评估工作量与风险。

## 8. 责任限制

在法律允许的最大范围内，BV003 的作者、贡献者及分发者不对因使用或无法使用本设计而导致的任何直接、间接、附带、特殊或 consequential 损害承担责任，包括但不限于数据丢失、设备损坏、业务中断或利润损失。

## 9. 接受条款

下载、复制、制造、修改或运行 BV003 即表示您已阅读、理解并同意本免责声明的全部内容，**且充分知晓其为未验证原型**。如不同意，请立即停止使用本设计及相关资料。

---

*最后更新：2026-08-01*

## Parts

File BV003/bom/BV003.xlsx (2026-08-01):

编号 | 位号 | 封装 | 数量 | 名称 | 供应商
1 | R80, R84 | R_0402_1005Metric NC | 2
2 | R73, R92, R93, R104, R105, R111, R112, R126 | R_0402_1005Metric 0R | 8
3 | R88, R89, R94, R99, R100, R102, R109, R110, R115, R116, R118, R120, R131 | R_0402_1005Metric 10R | 13
4 | R95, R96, R97, R113, R114, R127, R128, R129, R130 | R_0402_1005Metric 49R9 | 9
5 | R132, R133 | R_0402_1005Metric 0.33k | 2
6 | R1, R2, R3, R4, R7, R8, R9, R11, R12, R13, R15, R16, R17, R19, R22, R25, R28, R32, R33, R34, R35, R36, R43, R46, R49, R52, R56, R57, R58, R59, R60, R61, R64, R67, R70, R74, R75, R76, R77, R78 | R_0402_1005Metric 1k | 40
7 | R39, R40, R41, R42 | R_0805_2012Metric 2.7k | 4
8 | R85 | R_0402_1005Metric 4.64k | 1
9 | R124 | R_0402_1005Metric 4.7k | 1
10 | R103, R106, R121, R122 | R_0402_1005Metric 5.11k | 4
11 | R87 | R_0402_1005Metric 5.36k | 1
12 | R86 | R_0402_1005Metric 8.25k | 1
13 | R5, R10, R14, R18, R20, R21, R23, R24, R26, R27, R29, R30, R31, R44, R45, R47, R48, R50, R51, R53, R54, R62, R63, R65, R66, R68, R69, R71, R72, R81, R98, R101, R117, R119, R123, R125, R134, R135 | R_0402_1005Metric 10k | 38
14 | R37, R38 | R_0805_2012Metric 10k | 2
15 | R108 | R_0805_2012Metric 11.5k | 1
16 | R55 | R_0402_1005Metric 12.4k | 1
17 | R88, R91 | R_0402_1005Metric 16.2k | 2
18 | R107 | R_0402_1005Metric 16.9k | 1
19 | R6 | R_0402_1005Metric 20k | 1
20 | R79, R83 | R_0402_1005Metric 21.5k | 2
21 | R90 | R_0402_1005Metric 84.5k | 1
22 | C22, C47, C70, C93, C137, C138, C183, C184 | C_0402_1005Metric 33pF/25v | 8
23 | C135, C136, C181, C182 | C_0402_1005Metric 1000pF/25v | 4
24 | C130, C207, C214, C216, C217 | C_0402_1005Metric 10nF/25v | 5
25 | C218 | C_0402_1005Metric 22nF/25v | 1
26 | C25,C27, C28, C50, C73, C96, C98, C107, C109, C132, C133, C134, C140 ,C141, C144, C179, C180, C187, C188, C205 | C_0402_1005Metric 100nF/50v | 20
27 | C2, C206, C209, C210, C211, C212, C213 | C_0603_1608Metric 100nF/50v | 7
28 | C4, C29, C53, C75, C100, C101, C103, C104, C105 | C_0805_2012Metric 100nF/50v | 9
29 | C5, C6, C7, C8, C9, C10, C11, C12, C13, C16, C17, C20, C21, C23, C24, C26, C30, C31, C32, C33, C34, C35, C36, C37, C38, C39, C42, C45, C46, C48, C49, C51, C52, C54, C55, C56, C57, C58, C59, C60, C61, C62, C65, C68, C69, C71, C72, C74, C76, C77, C78, C79, C80, C81, C82, C83, C84, C85, C88, C91, C92, C94, C95, C97, C99, C108, C110, C123, C125, C126, C128, C173, C174, C175, C176 | C_0402_1005Metric 1uF/25v | 75
30 | C146, C149, C191, C193 | C_0402_1005Metric 2.2uF/25v | 4
31 | C127, C129, C177, C178, C208 | C_0402_1005Metric 4.7uF/25v | 5
32 | C14, C15, C18, C19, C40, C41, C43, C44, C63, C64, C66, C67, C86, C87, C89, C90, C106, C118, C145, C215 | C_0603_1005Metric 10uF/50v | 20
33 | C54,C56,C57,C58,C59,C62,C63,C64,C66 | C_0805_2012Metric 10uf/50v | 9
34 | C1, C3 | C_1210_3225Metric 10uf/50v | 2
35 | C113, C114, C115, C116, C117, C119, C120, C121, C122, C124, C163, C164, C165, C166, C167, C168, C169, C170, C171, C172 | C_0805_2012Metric 22uF/50v | 20
36 | C131 | C_0805_2012Metric 22uF/16v | 1
37 | C139, C142, C143, C147, C148, C150, C151, C152, C153, C154, C155, C156, C185, C186, C189, C190, C192, C194, C195, C196, C197, C198, C199, C200 | C_1206_3216Metric 100uf/16v | 24
38 | C157, C159, C201, C202 | Conductive Polymer Aluminum Solid Capacitors CP_Elec_6.3x5.9 270uf/10v | 4
39 | FB4, FB5, FB6, FB7 | BLM21PG221SN1D | 4
40 | FB8 | BLM15AG121SN1D | 1
41 | FB9 | HH-1M1608-121JT | 1
42 | D1 | SMBJ18A | 1
43 | D2 | D_SOD-123,1N5819 | 1
44 | D3 | D_SOD-128,PMEG4030EP | 1
45 | L1 | L_Taiyo-Yuden_NR-50xx 4.7uh/2.3A | 1
46 | L2, L3, L4, L5 | SLC1175-30 150nH | 4
47 | U1, U6, U10, U14, U32 | Oscillator_SMD_Abracon_ASDMB-4Pin_3.2X2.5mm 25MHZ | 5
48 | U3, U9, U13, U17 | B1373CC | 4
49 | U5 | SN74AXC4T774 | 1
50 | U27 | SOT-23-6,AP3211 | 1
51 | U28, U29, U30, U31 | TPS546D24A | 4
52 | U20 | MSOP-10_3x3mm_P0.5mm,EMC2302-1 | 1
53 | U2, U7, U11, U15 | SOT-23-5,MCP1824T-1202E/OT | 4
54 | U4, U8, U12, U16 | SOT-23-5,MCP1824T-0802E | 4
55 | U30 | T-Display-S3 | 1
56 | U18, U25, U26 | TLV3544 | 3
57 | U22, U23, U24 | TMP1075 | 1
58 | U21 | TXU0102-DCU | 1
59 | U33 | W5500 | 1
60 | J1 | AMASS_XT60PW-M_1x02_P7.20mm_Horizonta | 1
61 | J7 | RJ45_Hanrun_HR911105A_Horizontal | 1
62 | J5,J6 | Conn_01x12-Socket | 2
63 | M1,M2 | Fan_4pin | 2

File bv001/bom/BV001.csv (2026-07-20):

编号 | 位号 | 封装 | 数量 | 名称 | 供应商编号
1 | , , , , , , , , , , , , , , , , |  | 17
2 | C1 | C_0402_1005Metric | 1 | 2.2nF
3 | C2, C4, C9, C18, C109, C149, C150, C164, C165 | C_0402_1005Metric | 9 | 1nF
4 | C3 | C_0402_1005Metric | 1 | 12pF
5 | C5 | C_0402_1005Metric | 1 | 330nF
6 | C6, C8, C34, C37, C58, C58, C64, C67, C70, C72, C74, C76, C78, C80, C94, C105, C108 | C_0402_1005Metric | 17 | 1µF
7 | C7 | C_0402_1005Metric | 1 | 4.7µF
8 | C10, C14, C87, C96, C101, C102, C103, C107, C141, C147, C156, C162 | C_0402_1005Metric | 12 | 100nF
9 | C12, C142, C157 | C_0402_1005Metric | 3 | 2.2µF
10 | C16, C19, C22, C39, C45, C48, C61, C65, C81, C81, C81, C84, C85, C86, C110, C111, C112, C113, C117, C118, C121, C122, C123, C124, C125, C126, C127, C129, C130 | C_0603_1608Metric | 29 | 10uF
11 | C21, C24, C151, C152, C153, C154, C155, C158, C159, C160, C161, C163, C166, C167, C168, C169, C170, C171, C172, C173, C174, C175, C176, C177, C178, C179, C180, C181, C182, C183, C184, C185, C186, C187, C188, C189, C190, C191, C192, C193, C194, C195, C196, C197, C199, C200, C201, C202, C203 | C_1206_3216Metric | 49 | 100µF
12 | C22 | C_0402_1005Metric | 1 | 10nf
13 | C59, C100 | C_0402_1005Metric | 2 | 0.1uF
14 | C62 | C_0402_1005Metric | 1 | 100nf
15 | C62 | C_0402_1005Metric | 1 | 100pF
16 | C88 | C_0402_1005Metric | 1 | 33pf
17 | C92, C135 | CP_Elec_8x10 | 2 | 220µF
18 | C114, C115, C116 | C_0402_1005Metric | 3 | 22pF
19 | C119, C120 | C_0603_1608Metric | 2 | 10µF
20 | D1 | D_SMB | 1 | 5KPxxA
21 | D2 | D_SOD-128 | 1 | ~
22 | D3 | D_SOD-123 | 1 | 1N5819
23 | FB1 | FB0603 | 1 | ~
24 | J1 | XT30PW-M | 1 | XT30
25 | L1, L5, L6 | IFLR-4031GC-01-8x10 | 3 | 220nH
26 | L5 | L_Changjiang_FTC201612S | 1 | 4.7uH
27 | M1, M2 | FanPinHeader_1x04_P2.54mm_Vertical | 2 | Fan_4pin
28 | R1 | R_0402_1005Metric | 1 | 16.5k
29 | R2 | R_0402_1005Metric | 1 | 24.3k
30 | R3 | R_0402_1005Metric | 1 | 66.5k
31 | R4 | R_0402_1005Metric | 1 | 100k
32 | R5 | R_0402_1005Metric | 1 | 121k
33 | R6 | R_0402_1005Metric | 1 | 8.06k
34 | R7 | R_0402_1005Metric | 1 | 2.55k
35 | R8, R17 | R_0402_1005Metric | 2 | 4.7k
36 | R10, R11, R14, R15, R25, R27 | R_0805_2012Metric | 6 | 1R/0.5w
37 | R12, R13 | R_0402_1005Metric | 2 | 2.2R
38 | R13 | R_0402_1005Metric | 1 | 84.5k
39 | R14 | R_0402_1005Metric | 1 | 16.2k
40 | R21, R21, R22, R31, R36, R37, R38 | R_0402_1005Metric | 7 | 10k
41 | R26 | R_0402_1005Metric | 1 | 20k
42 | R33, R35 | R_0402_1005Metric | 2 | 2.7k
43 | R39, R40 | R_0402_1005Metric | 2 | 100R
44 | R44, R44, R47 | R_0402_1005Metric | 3 | 1k
45 | U3 | Texas_RHA0040B_VQFN-40-1EP_6x6mm_P0.5mm_EP4.15x4.15mm_ThermalVias | 1 | TPS53647
46 | U4, U9, U10 | CSD95472-SON-5x6 | 3 | CSD95472Q5MC
47 | U5 | B1373CC | 1 | ~
48 | U6 | TSSOP-16_4.4x5mm_P0.65mm | 1 | SN74AVC4T774
49 | U7 | SOT-23-5 | 1 | MCP1824T-0802E
50 | U8 | Oscillator_SMD_EuroQuartz_XO32-4Pin_3.2x2.5mm | 1 | 25MHz
51 | U14 | SOT-23-6 | 1 | ~
52 | U30 | T-Display-S3 | 1 | T-Display-S3
53 | U32 | MSOP-10_3x3mm_P0.5mm | 1 | EMC2302-1
54 | U33 | VSSOP-8_2.3x2mm_P0.5mm | 1 | TXU0102-DCU
55 | U36 | SOT-23-5 | 1 | MCP1824T-1202E
56 | U37, U38 | TMP1075-DRL | 2 | TMP1075

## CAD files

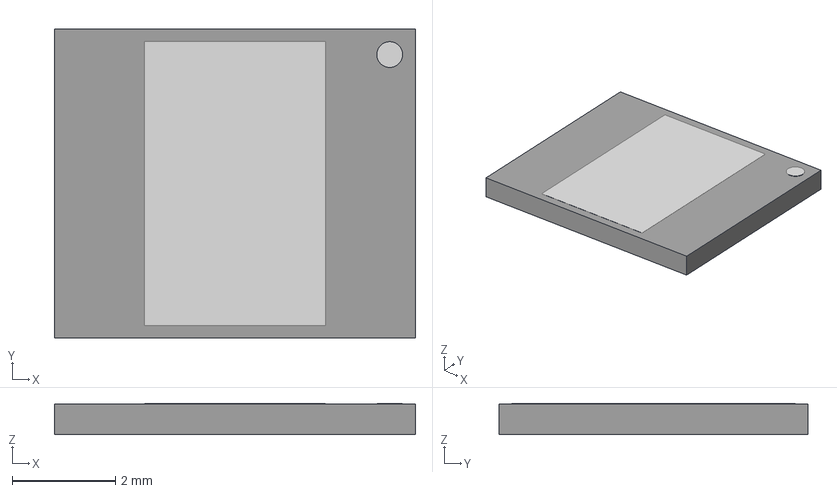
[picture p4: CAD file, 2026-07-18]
BV002/pcb/BV002REV1.5/3d/bm1366.step
7.00 x 6.00 x 0.61 mm

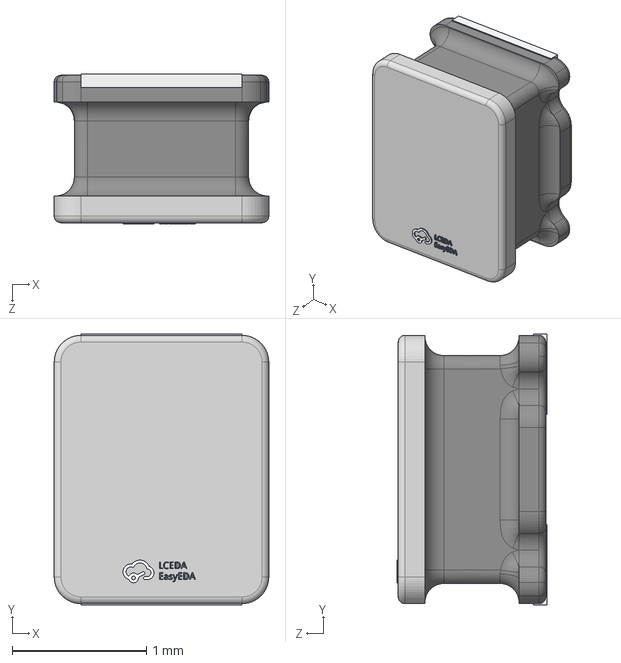
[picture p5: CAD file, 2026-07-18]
BV002/pcb/BV002REV1.5/3dshapes/IND-SMD_L2.0-W1.6-H1.1.step
1.60 x 2.02 x 1.12 mm

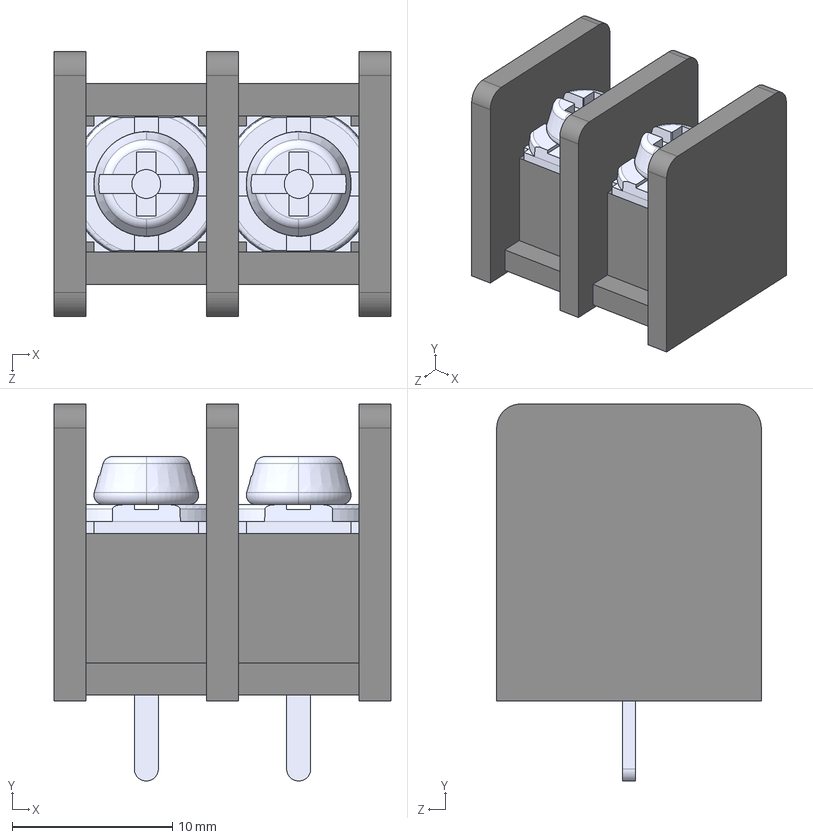
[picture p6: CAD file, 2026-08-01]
BV003/pcb/BV003REV1.0/3d/OSTYK51102030.STEP
21.0 x 23.5 x 16.5 mm

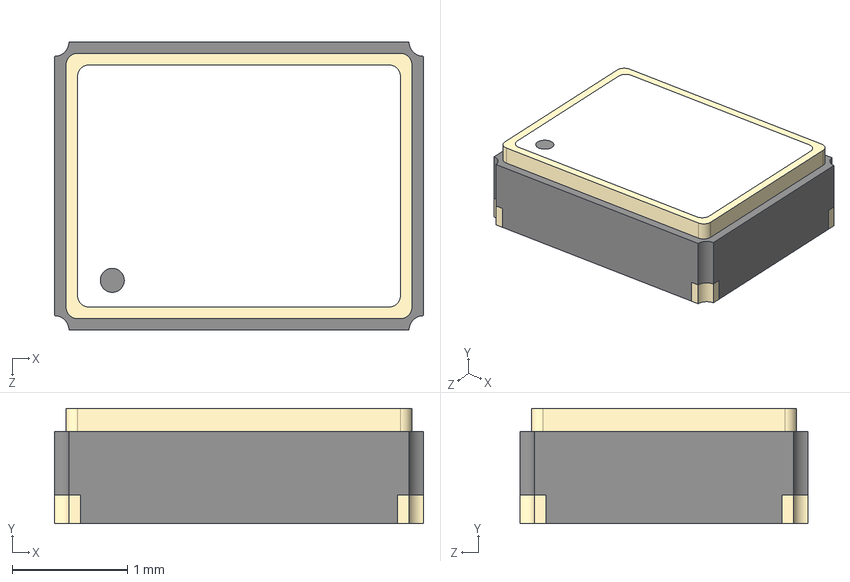
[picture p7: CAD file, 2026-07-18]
BV002/pcb/BV002REV1.5/3d/oscillator3.2x2.5.step
3.20 x 1.00 x 2.50 mm

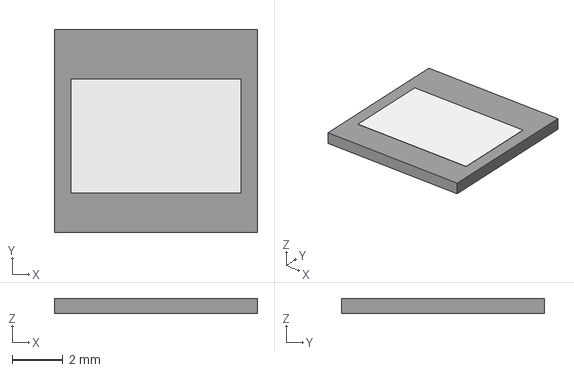
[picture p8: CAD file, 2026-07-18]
BV002/pcb/BV002REV1.5/3d/bm1370.step
8.00 x 8.00 x 0.61 mm

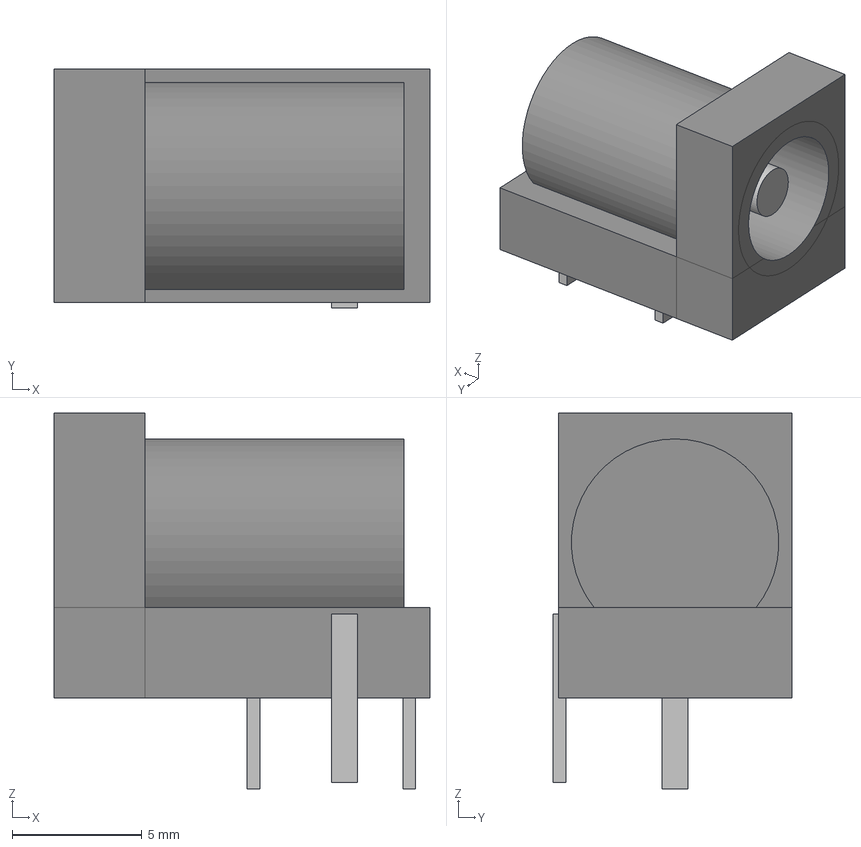
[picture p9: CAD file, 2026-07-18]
BV002/pcb/BV002REV1.5/3d/barrel-jack.step
14.5 x 9.20 x 14.5 mm

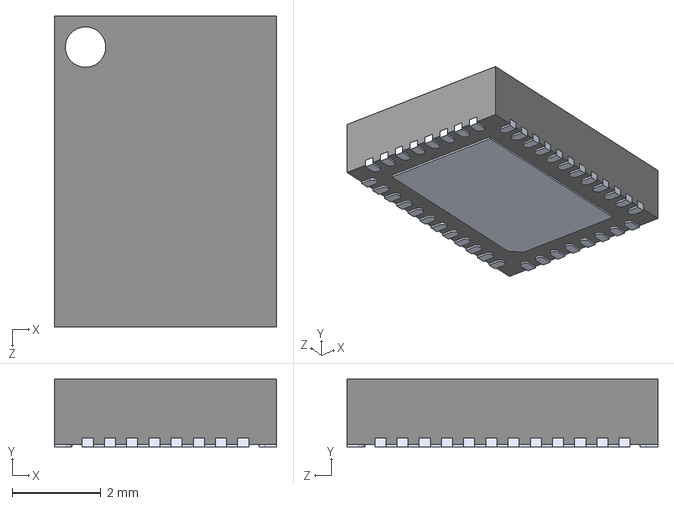
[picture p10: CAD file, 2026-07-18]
BV002/pcb/BV002REV1.5/3d/TPS546D24ARVFR.step
5.00 x 1.52 x 7.00 mm

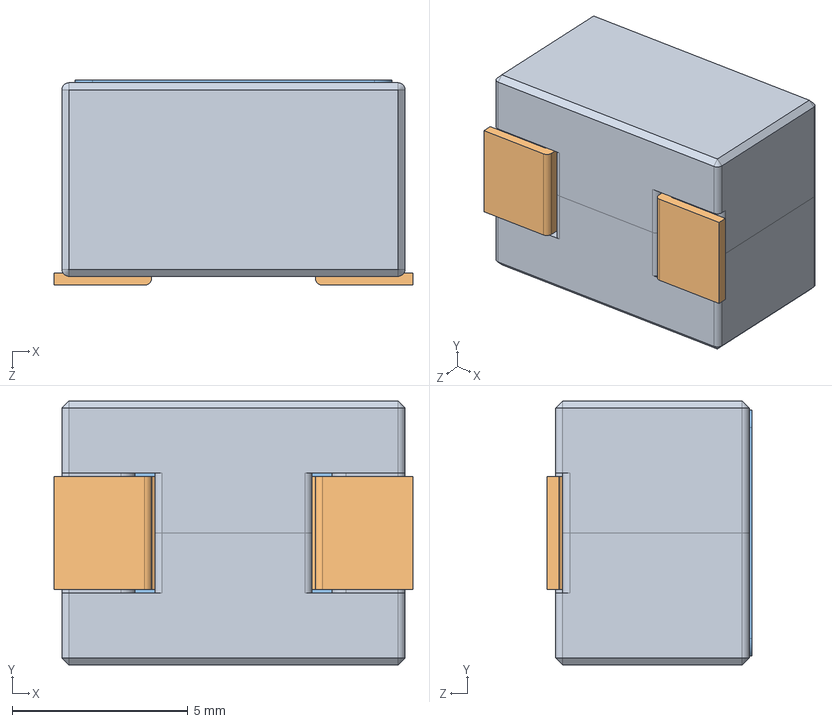
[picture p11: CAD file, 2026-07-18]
BV002/pcb/BV002REV1.5/3d/FP1006V2-R.STEP
10.2 x 7.50 x 5.83 mm
11150900A x 2
53134900A
Label for FP1006V2-R

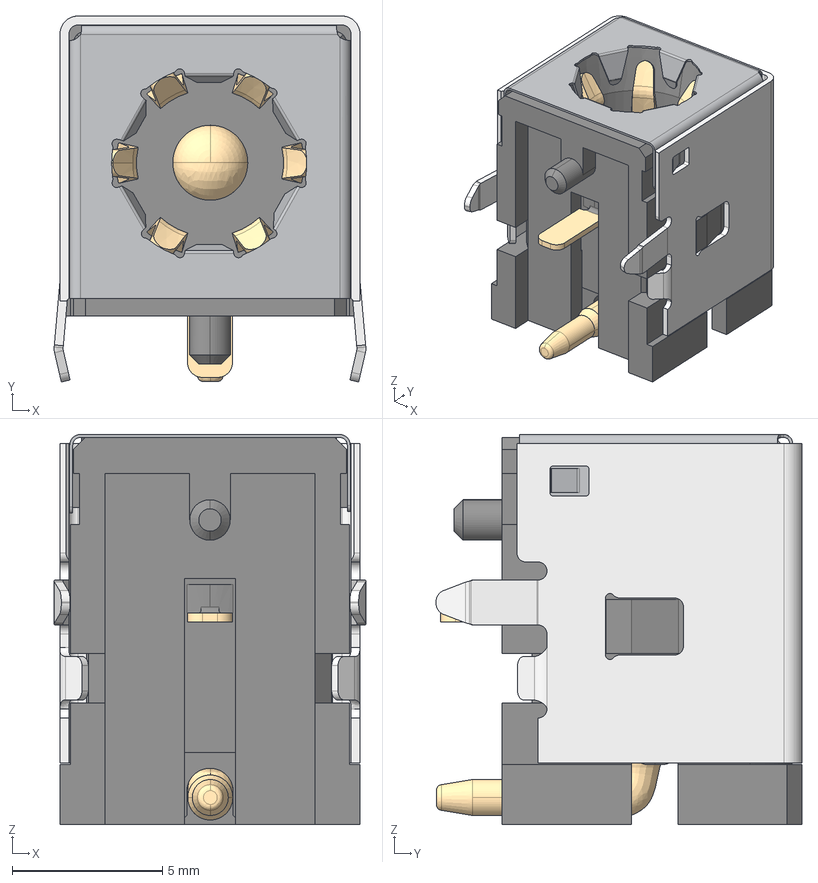
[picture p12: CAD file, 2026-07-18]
BV002/pcb/BV002REV1.5/3d/DCJ250-20-B-XX-X_REVA1.step
10.4 x 12.2 x 13.0 mm

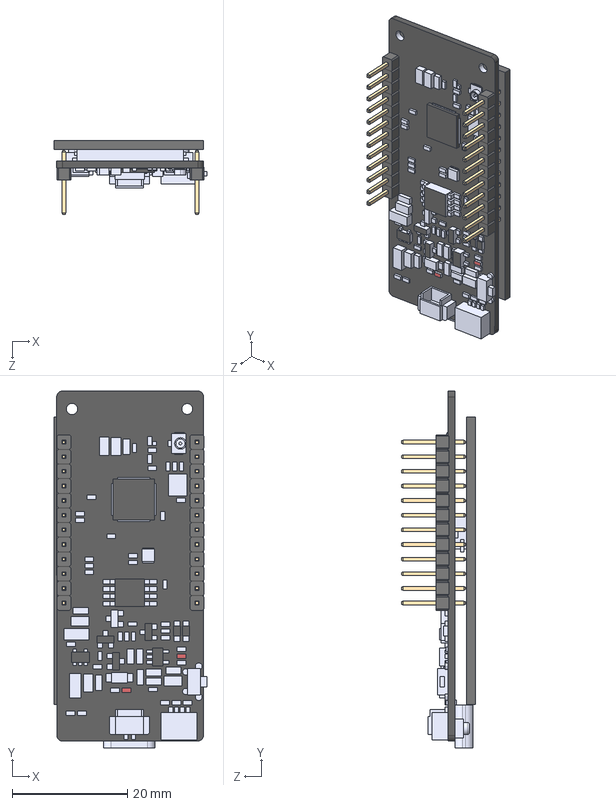
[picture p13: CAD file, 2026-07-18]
BV002/pcb/BV002REV1.5/3d/T-Display-S3.STEP
26.5 x 62.0 x 12.9 mm
MainBoard_3D
Ecran
1_Male_Pin_2.54_mm x 24

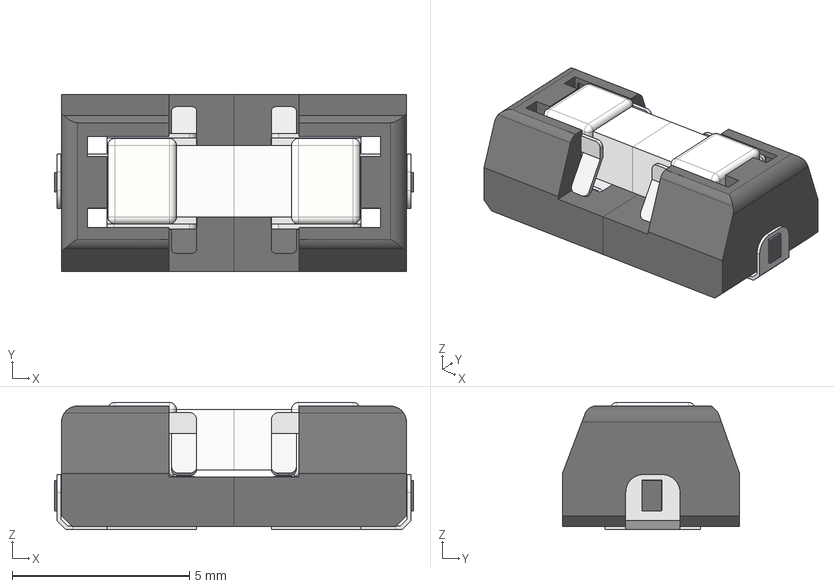
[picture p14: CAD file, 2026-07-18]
BV002/pcb/BV002REV1.5/3d/Littelfuse 0154.500DRT without value_black v2.step
10.1 x 5.00 x 3.59 mm
Komponente1
Komponente2
Komponente3
Komponente4

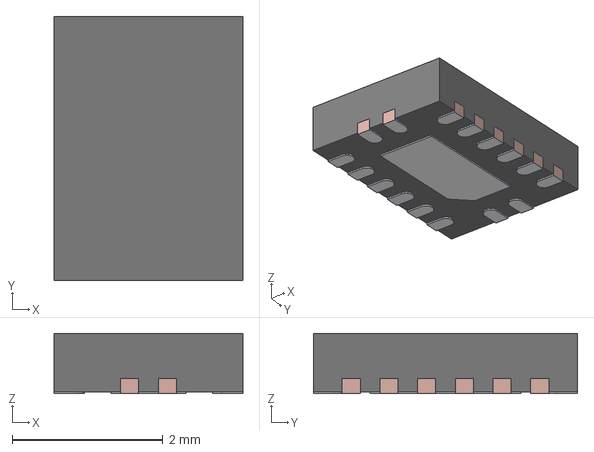
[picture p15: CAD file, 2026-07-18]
BV002/pcb/BV002REV1.5/3d/BQB0016A.stp
2.50 x 3.50 x 0.8 mm
FRAME

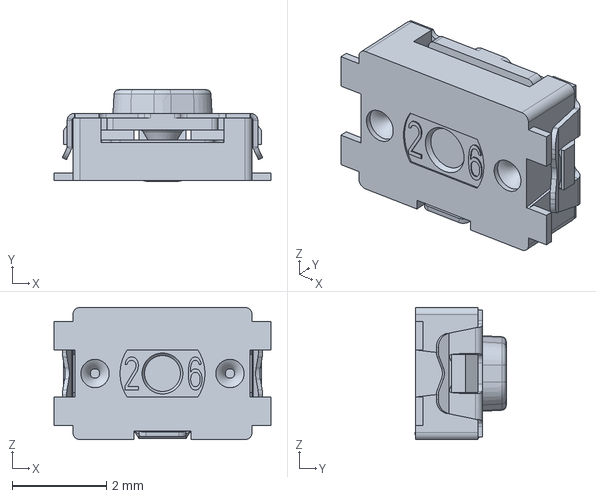
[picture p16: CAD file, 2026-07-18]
BV002/pcb/BV002REV1.5/3d/KMR231GLFS.stp
4.60 x 1.94 x 2.80 mm

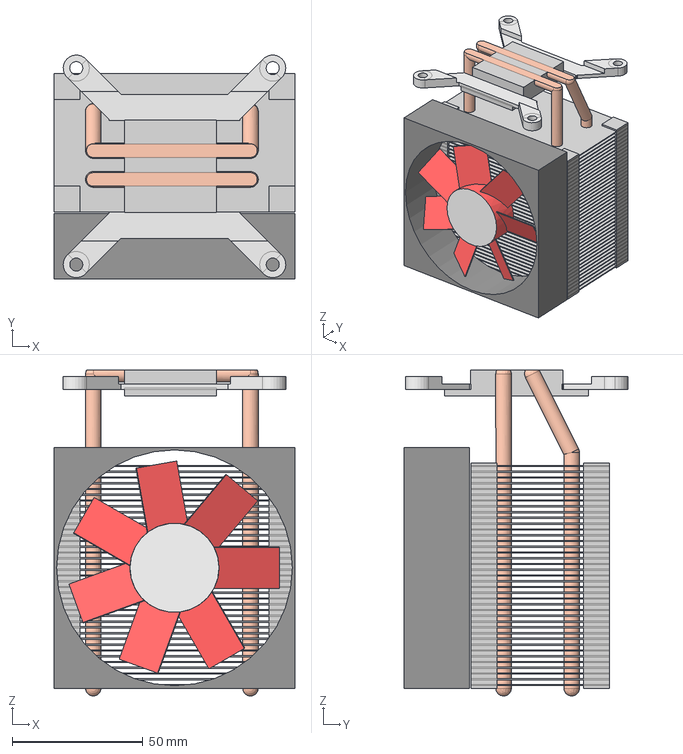
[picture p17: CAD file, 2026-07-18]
BV002/pcb/BV002REV1.5/3d/lga115x.step
92.0 x 85.5 x 124.5 mm

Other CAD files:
BV002/pcb/BV002REV1.5/3d/XT30PW-M.stp
BV002/pcb/BV002REV1.5/3d/SLC1175-271MEC_COC.step
BV002/pcb/BV002REV1.5/3d/heatsink-13x12x5.step
BV002/pcb/BV002REV1.5/3d/SIS0011A.stp
BV002/pcb/BV002REV1.5/3d/bm1370.scad
BV002/pcb/BV002REV1.5/3d/csd95472.scad
BV002/pcb/BV002REV1.5/3d/IND_VLS6045EX-4R7M_TDK.stl
BV002/pcb/BV002REV1.5/3d/csg95472.step

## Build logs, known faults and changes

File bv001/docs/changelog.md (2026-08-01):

# BV001 修订记录

本文档记录 BV001 硬件设计、BOM 及文档的变更历史。

## 格式说明

- **日期**：变更发布或验证日期
- **版本**：硬件或 BOM 版本标识（如有）
- **状态**：`已验证` / `待验证` / `已废弃`

---

## 2026-08-01 — 仓库结构整理

**状态**：已验证

- 调整仓库目录结构，BV001 资料归集至 `BV001/` 目录
- BOM 文件路径：`BV001/bom/BV001.csv`
- 新增 `BV001/docs/` 文档目录

---

## 2026-07-22 — 设计验证与性能数据发布

**状态**：已验证

- 完成实机测试，确认设计可用
- 记录两种典型运行工况：
  - **高性能**：900 MHz / Vcore 1250 mV，约 110 W @ 12 V，约 6.1 TH/s
  - **省电**：735 MHz / Vcore 1140 mV，墙插约 78 W，约 5 TH/s，效率约 14 J/TH
- 推荐电源：12 V / 15 A
- README 补充设计说明与测试照片

---

## 2026-07-21 — TMP1075 温度传感器修复

**状态**：已验证

- 修复 TMP1075（U37、U38）相关 PCB 布局/连接问题
- 温度读取功能恢复正常

---

## 2026-07-20 — 初始发布

**状态**：已验证

- 基于 [nerdqaxeplus2 / qaxe](https://github.com/shufps/qaxe) 改板
- 主要变更：ASIC 替换为 1× BM1373 AA（约 6.1 TH/s SHA256）
- 发布 KiCad 工程与 BOM

---

## 上游参考

BV001 衍生自开源项目 **nerdqaxeplus2 (qaxe)**。上游项目的修订历史请参阅其官方仓库。

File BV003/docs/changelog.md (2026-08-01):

# BV003 修订记录

本文档记录 BV003 硬件设计、BOM 及文档的变更历史。

## 格式说明

- **日期**：变更发布或验证日期
- **版本**：硬件或 BOM 版本标识（如有）
- **状态**：`已验证` / `待验证` / `已废弃`

---

## 2026-08-01 — BV003REV1.0 初始发布

**版本**：REV 1.0  
**状态**：待验证

> **警告：本版本为未验证原型，请勿期望直接可用。**

- 上传 KiCad 工程至 `BV003/pcb/BV003REV1.0/`
- 调整仓库目录结构，BV003 资料归集至 `BV003/` 目录
- 新增 `BV003/docs/` 文档目录

**设计概要（未经实机验证）：**

- 基于 [NerdOCTAXE-Gamma](https://github.com/Patsch91/NerdOCTAXE-Gamma)（8× BM1370 多 ASIC 矿机）改板
- 主要变更：ASIC 改为 4× BM1373；电源改为 TPS546 四相（上游 Rev3.4 为六相 Buck）
- 4× BM1373 ASIC（`bm1373_1` ~ `bm1373_4` 子图）
- TPS546 四相电源（`power.kicad_sch`）
- T-Display-S3 显示与控制
- W5500 以太网（`w5500.kicad_sch`）
- 电平转换（`level_shifter.kicad_sch`）

**已知限制：**

- 尚未完成打板、焊接或上电测试
- 无性能、功耗、散热数据
- BOM 可能尚未同步发布或完善
- KiCad 工程中 `plot` 路径预留了 REV1.1，后续改版待补充

---

## 与 BV001 / BV002 的关系

| 项目 | BV001 | BV002 | BV003 |
|---|---|---|---|
| 上游参考 | [qaxe](https://github.com/shufps/qaxe) | — | [NerdOCTAXE-Gamma](https://github.com/Patsch91/NerdOCTAXE-Gamma) |
| 验证状态 | 已验证 | 未验证原型 | 未验证原型 |
| ASIC 数量 | 1× BM1373 | 2× BM1373 | 4× BM1373 |
| 适用场景 | 可参考复刻 | 实验性设计 | 实验性设计 |

如需实际可用的参考设计，请优先参考 **BV001**。

---

## 上游参考

BV003 基于 **[NerdOCTAXE-Gamma](https://github.com/Patsch91/NerdOCTAXE-Gamma)** 修改而来。该项目是 8× BM1370 多 ASIC 矿机，源自 NerdQaxe 生态；当前上游版本为 Rev-3.4（六相 Buck、ASIC 内部温度读取等）。

BV003 相对上游的主要改动：

- ASIC：BM1370 × 8 → **BM1373 × 4**
- 电源：六相 Buck → **TPS546 四相**
- 其余模块（T-Display-S3、多 ASIC 互联架构等）沿用上游设计思路

上游修订历史请参阅 [NerdOCTAXE-Gamma 仓库](https://github.com/Patsch91/NerdOCTAXE-Gamma)。固件方面，上游使用修改版 [ESP-Miner-NerdQAxe+](https://github.com/shufps/ESP-Miner-NerdQAxe-plus)（AxeOS），BV003 移植适配 **尚未验证**。

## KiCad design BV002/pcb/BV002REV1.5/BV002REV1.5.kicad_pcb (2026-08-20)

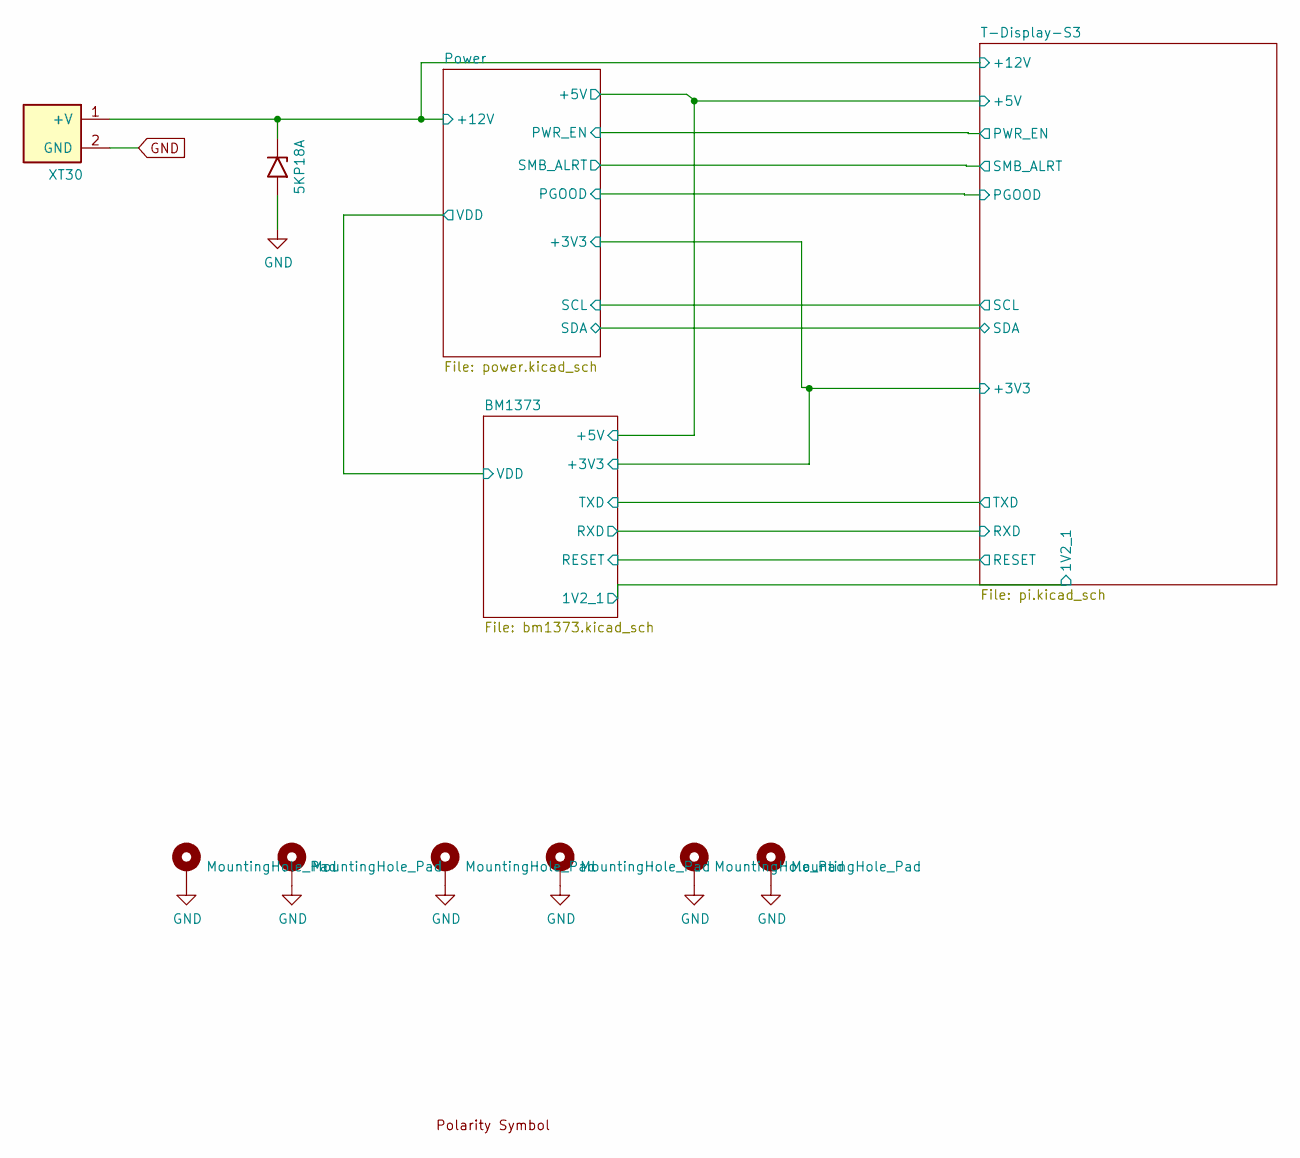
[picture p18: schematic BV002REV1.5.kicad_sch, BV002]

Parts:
D1: 5KP18A; D_SMB; PARTNO SMBJ12A; LCSC C3001973
H1, H2, H3, H4, H5, H6: MountingHole_Pad; MountingHole_3.2mm_M3_Pad_Via
J1: XT30; XT30PW-M; PARTNO XT30PW-M; LCSC C431092
U1: polarity

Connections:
+12V: D1.1 (A1), J1.1 (+V); also elsewhere on the board

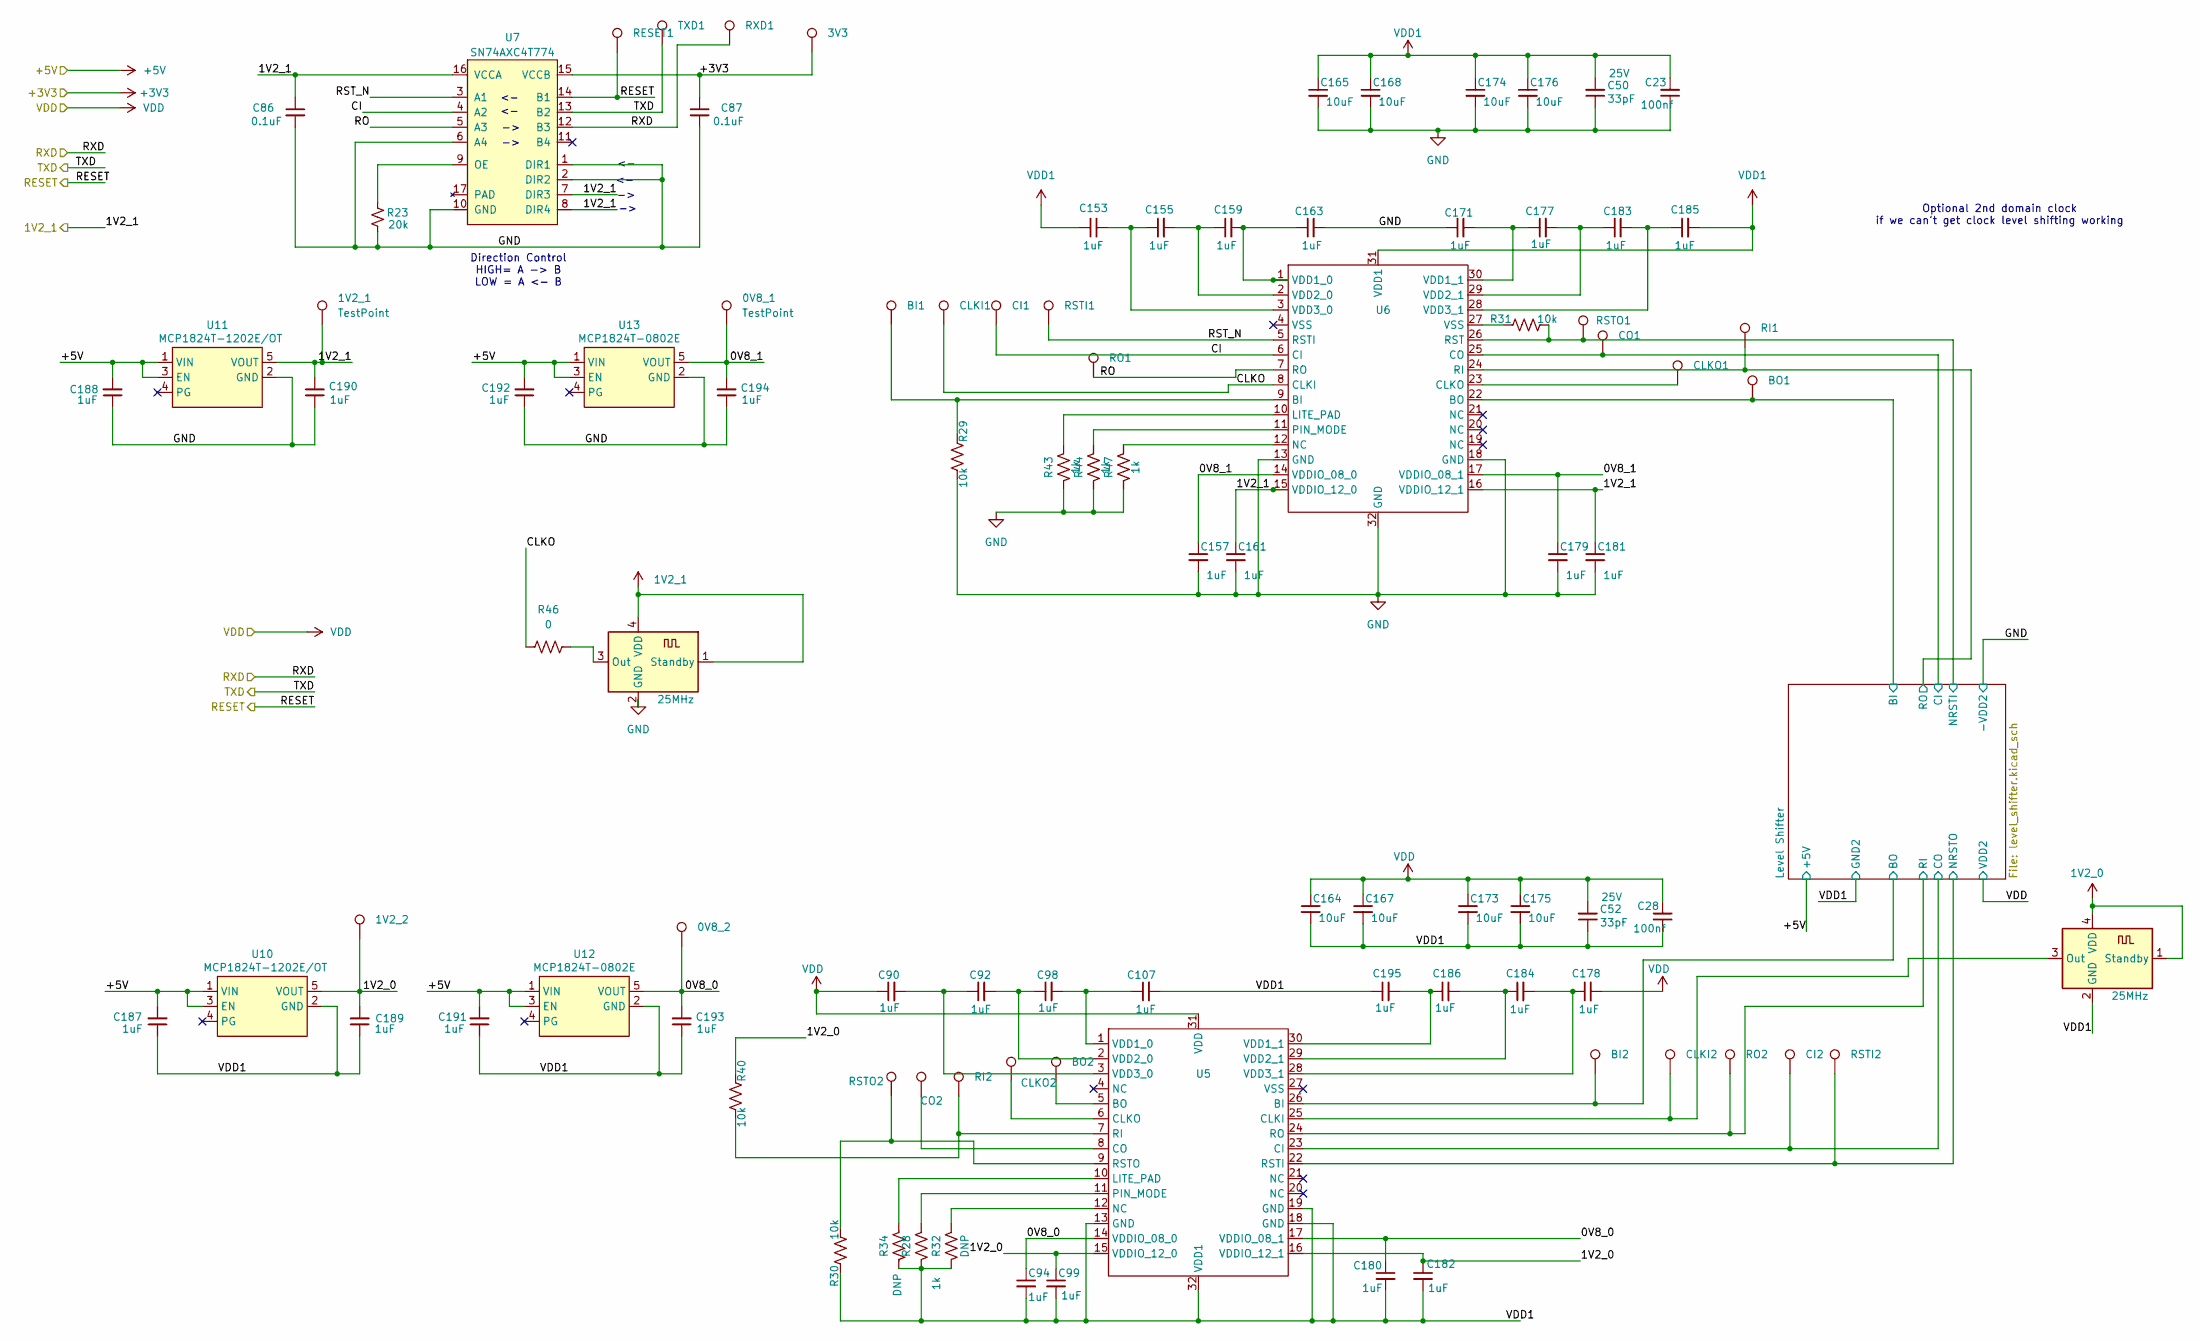
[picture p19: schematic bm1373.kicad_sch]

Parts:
0V8_1, 1V2_1: TestPoint; TestPoint_Pad_D1.5mm
0V8_2, 1V2_2, 3V3: TestPoint_Pad_D1.5mm
BI1, BI2: TestPoint_Pad_D1.5mm
BO1, BO2: TestPoint_Pad_D1.5mm
C23, C28: 100nf; C_0402_1005Metric; PARTNO GRM188R61E106KA73D
C50, C52: 33pF; C_0402_1005Metric; Voltage 25V; PARTNO KGM05ACG1E330JH
C86, C87: 0.1uF; C_0402_1005Metric; PARTNO KGM05AR71C104KH
C90, C92, C94, C98, C99, C107, C153, C155, C157, C159, C161, C163, C171, C177, C178, C179, C180, C181, C182, C183, C184, C185, C186, C195: 1uF; C_0402_1005Metric; PARTNO CL05A105KO5NNNC; LCSC C29266
C164, C165, C167, C168, C173, C174, C175, C176: 10uF; C_0603_1608Metric; PARTNO CL10A106MO8NQNC; LCSC C92487 Hot
C187, C188, C189, C190, C191, C192, C193, C194: 1uF; C_0402_1005Metric; PARTNO EMK105BJ105MV-F
CI1, CI2: TestPoint_Pad_D1.5mm
CLKI1, CLKI2: TestPoint_Pad_D1.5mm
CLKO1, CLKO2: TestPoint_Pad_D1.5mm
CO1, CO2: TestPoint_Pad_D1.5mm
R23: 20k; R_0402_1005Metric; PARTNO RC0402FR-0720KL
R28, R43, R44, R47: 1k; R_0402_1005Metric; PARTNO RC0402FR-071KL; LCSC C106235
R29, R30, R31, R40: 10k; R_0402_1005Metric; PARTNO RC0402DR-0710KL; LCSC C471764
R32, R34: DNP; R_0402_1005Metric; PARTNO RC0402FR-071KL; LCSC C106235
R46: 0; R_0402_1005Metric; PARTNO RC0402JR-070RL
RESET1: TestPoint_Pad_D1.5mm
RI1, RI2: TestPoint_Pad_D1.5mm
RO1, RO2: TestPoint_Pad_D1.5mm
RSTI1, RSTI2: TestPoint_Pad_D1.5mm
RSTO1, RSTO2: TestPoint_Pad_D1.5mm
RXD1: TestPoint_Pad_D1.5mm
TXD1: TestPoint_Pad_D1.5mm
U5, U6: B1373CC
U7: SN74AXC4T774; TSSOP-16_4.4x5mm_P0.65mm; PARTNO SN74AXC4T774BQBR
U8, U9: 25MHz; Oscillator_SMD_EuroQuartz_XO32-4Pin_3.2x2.5mm; PARTNO SX3M25.000E20F30THN
U10, U11: MCP1824T-1202E/OT; SOT-23-5; PARTNO MCP1824T-1202E/OT
U12, U13: MCP1824T-0802E; SOT-23-5; PARTNO MCP1824T-0802E/OT

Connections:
1V2_0: 1V2_2.1, C99.1, C182.1, C189.2, R40.1, U5.15 (VDDIO_12_0), U5.16 (VDDIO_12_1), U8.1 (Standby), U8.4 (VDD), U10.5 (VOUT)
1V2_1: 1V2_1.1, C86.1, C161.1, C181.1, C190.2, U6.15 (VDDIO_12_0), U6.16 (VDDIO_12_1), U7.7 (DIR3), U7.8 (DIR4), U7.16 (VCCA), U9.1 (Standby), U9.4 (VDD), U11.5 (VOUT); also elsewhere on the board
+5V: C187.2, C188.2, C191.2, C192.2, U10.1 (VIN), U10.3 (EN), U11.1 (VIN), U11.3 (EN), U12.1 (VIN), U12.3 (EN), U13.1 (VIN), U13.3 (EN); also elsewhere on the board
/BM1373/0V8_0: 0V8_2.1, C94.1, C180.1, C193.2, U5.14 (VDDIO_08_0), U5.17 (VDDIO_08_1), U12.5 (VOUT)
/BM1373/0V8_1: 0V8_1.1, C157.1, C179.1, C194.2, U6.14 (VDDIO_08_0), U6.17 (VDDIO_08_1), U13.5 (VOUT)
/BM1373/CI: CI1.1 (1_1), U6.6 (CI), U7.4 (A2)
/BM1373/CLKO: CLKI1.1 (1_1), R46.1, U6.8 (CLKI)
/BM1373/Level Shifter/BI: BO1.1 (1_1), U6.22 (BO); also elsewhere on the board
/BM1373/Level Shifter/BI2: BI2.1 (1_1), U5.26 (BI); also elsewhere on the board
/BM1373/Level Shifter/CI: CO1.1 (1_1), U6.25 (CO); also elsewhere on the board
/BM1373/Level Shifter/CI2: CI2.1 (1_1), U5.23 (CI); also elsewhere on the board
/BM1373/Level Shifter/NRSTI: R31.2, RSTO1.1 (1_1), U6.26 (RST); also elsewhere on the board
/BM1373/Level Shifter/NRSTI2: RSTI2.1 (1_1), U5.22 (RSTI); also elsewhere on the board
/BM1373/Level Shifter/RO: RI1.1 (1_1), U6.24 (RI); also elsewhere on the board
/BM1373/Level Shifter/RO2: RO2.1 (1_1), U5.24 (RO); also elsewhere on the board
/BM1373/RESET: RESET1.1 (1_1), U7.14 (B1); also elsewhere on the board
/BM1373/RO: RO1.1 (1_1), U6.7 (RO), U7.5 (A3)
/BM1373/RST_N: RSTI1.1 (1_1), U6.5 (RSTI), U7.3 (A1)
/BM1373/RXD: RXD1.1 (1_1), U7.12 (B3); also elsewhere on the board
/BM1373/TXD: TXD1.1 (1_1), U7.13 (B2); also elsewhere on the board
unnamed: R31.1, U6.27 (VSS)
unnamed: R32.1, U5.12 (NC)
unnamed: R47.1, U6.12 (NC)
unnamed: BO2.1 (1_1), U5.5 (BO)
unnamed: CLKI2.1 (1_1), U5.25 (CLKI), U8.3 (Out)
unnamed: CLKO2.1 (1_1), U5.6 (CLKO)
unnamed: CO2.1 (1_1), U5.8 (CO)
unnamed: R34.1, U5.10 (LITE_PAD)
unnamed: R28.1, U5.11 (PIN_MODE)
unnamed: R40.2, RI2.1 (1_1), U5.7 (RI)
unnamed: R30.2, RSTO2.1 (1_1), U5.9 (RSTO)
unnamed: C98.2, C107.1, U5.1 (VDD1_0)
unnamed: C186.1, C195.2, U5.30 (VDD1_1)
unnamed: C92.2, C98.1, U5.2 (VDD2_0)
unnamed: C184.1, C186.2, U5.29 (VDD2_1)
unnamed: C90.2, C92.1, U5.3 (VDD3_0)
unnamed: C178.1, C184.2, U5.28 (VDD3_1)
unnamed: BI1.1 (1_1), R29.1, U6.9 (BI)
unnamed: CLKO1.1 (1_1), U6.23 (CLKO)
unnamed: R43.1, U6.10 (LITE_PAD)
unnamed: R44.1, U6.11 (PIN_MODE)
unnamed: C159.2, C163.1, U6.1 (VDD1_0)
unnamed: C171.2, C177.1, U6.30 (VDD1_1)
unnamed: C155.2, C159.1, U6.2 (VDD2_0)
unnamed: C177.2, C183.1, U6.29 (VDD2_1)
unnamed: C153.2, C155.1, U6.3 (VDD3_0)
unnamed: C183.2, C185.1, U6.28 (VDD3_1)
unnamed: R23.2, U7.9 (OE)
unnamed: R46.2, U9.3 (Out)
VDD: C28.2, C52.2, C90.1, C164.1, C167.1, C173.1, C175.1, C178.2, U5.31 (VDD); also elsewhere on the board
VDD1: C23.2, C28.1, C50.2, C52.1, C94.2, C99.2, C107.2, C153.1, C164.2, C165.1, C167.2, C168.1, C173.2, C174.1, C175.2, C176.1, C180.2, C182.2, C185.2, C187.1, C189.1, C191.1, C193.1, C195.1, R28.2, R30.1, R32.2, R34.2, U5.13 (GND), U5.18 (GND), U5.19 (GND), U5.32 (VDD1), U6.31 (VDD1), U8.2 (GND), U10.2 (GND), U12.2 (GND); also elsewhere on the board

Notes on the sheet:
Optional 2nd domain clock if we can't get clock level shifting working
Direction Control HIGH= A -> B LOW = A <- B

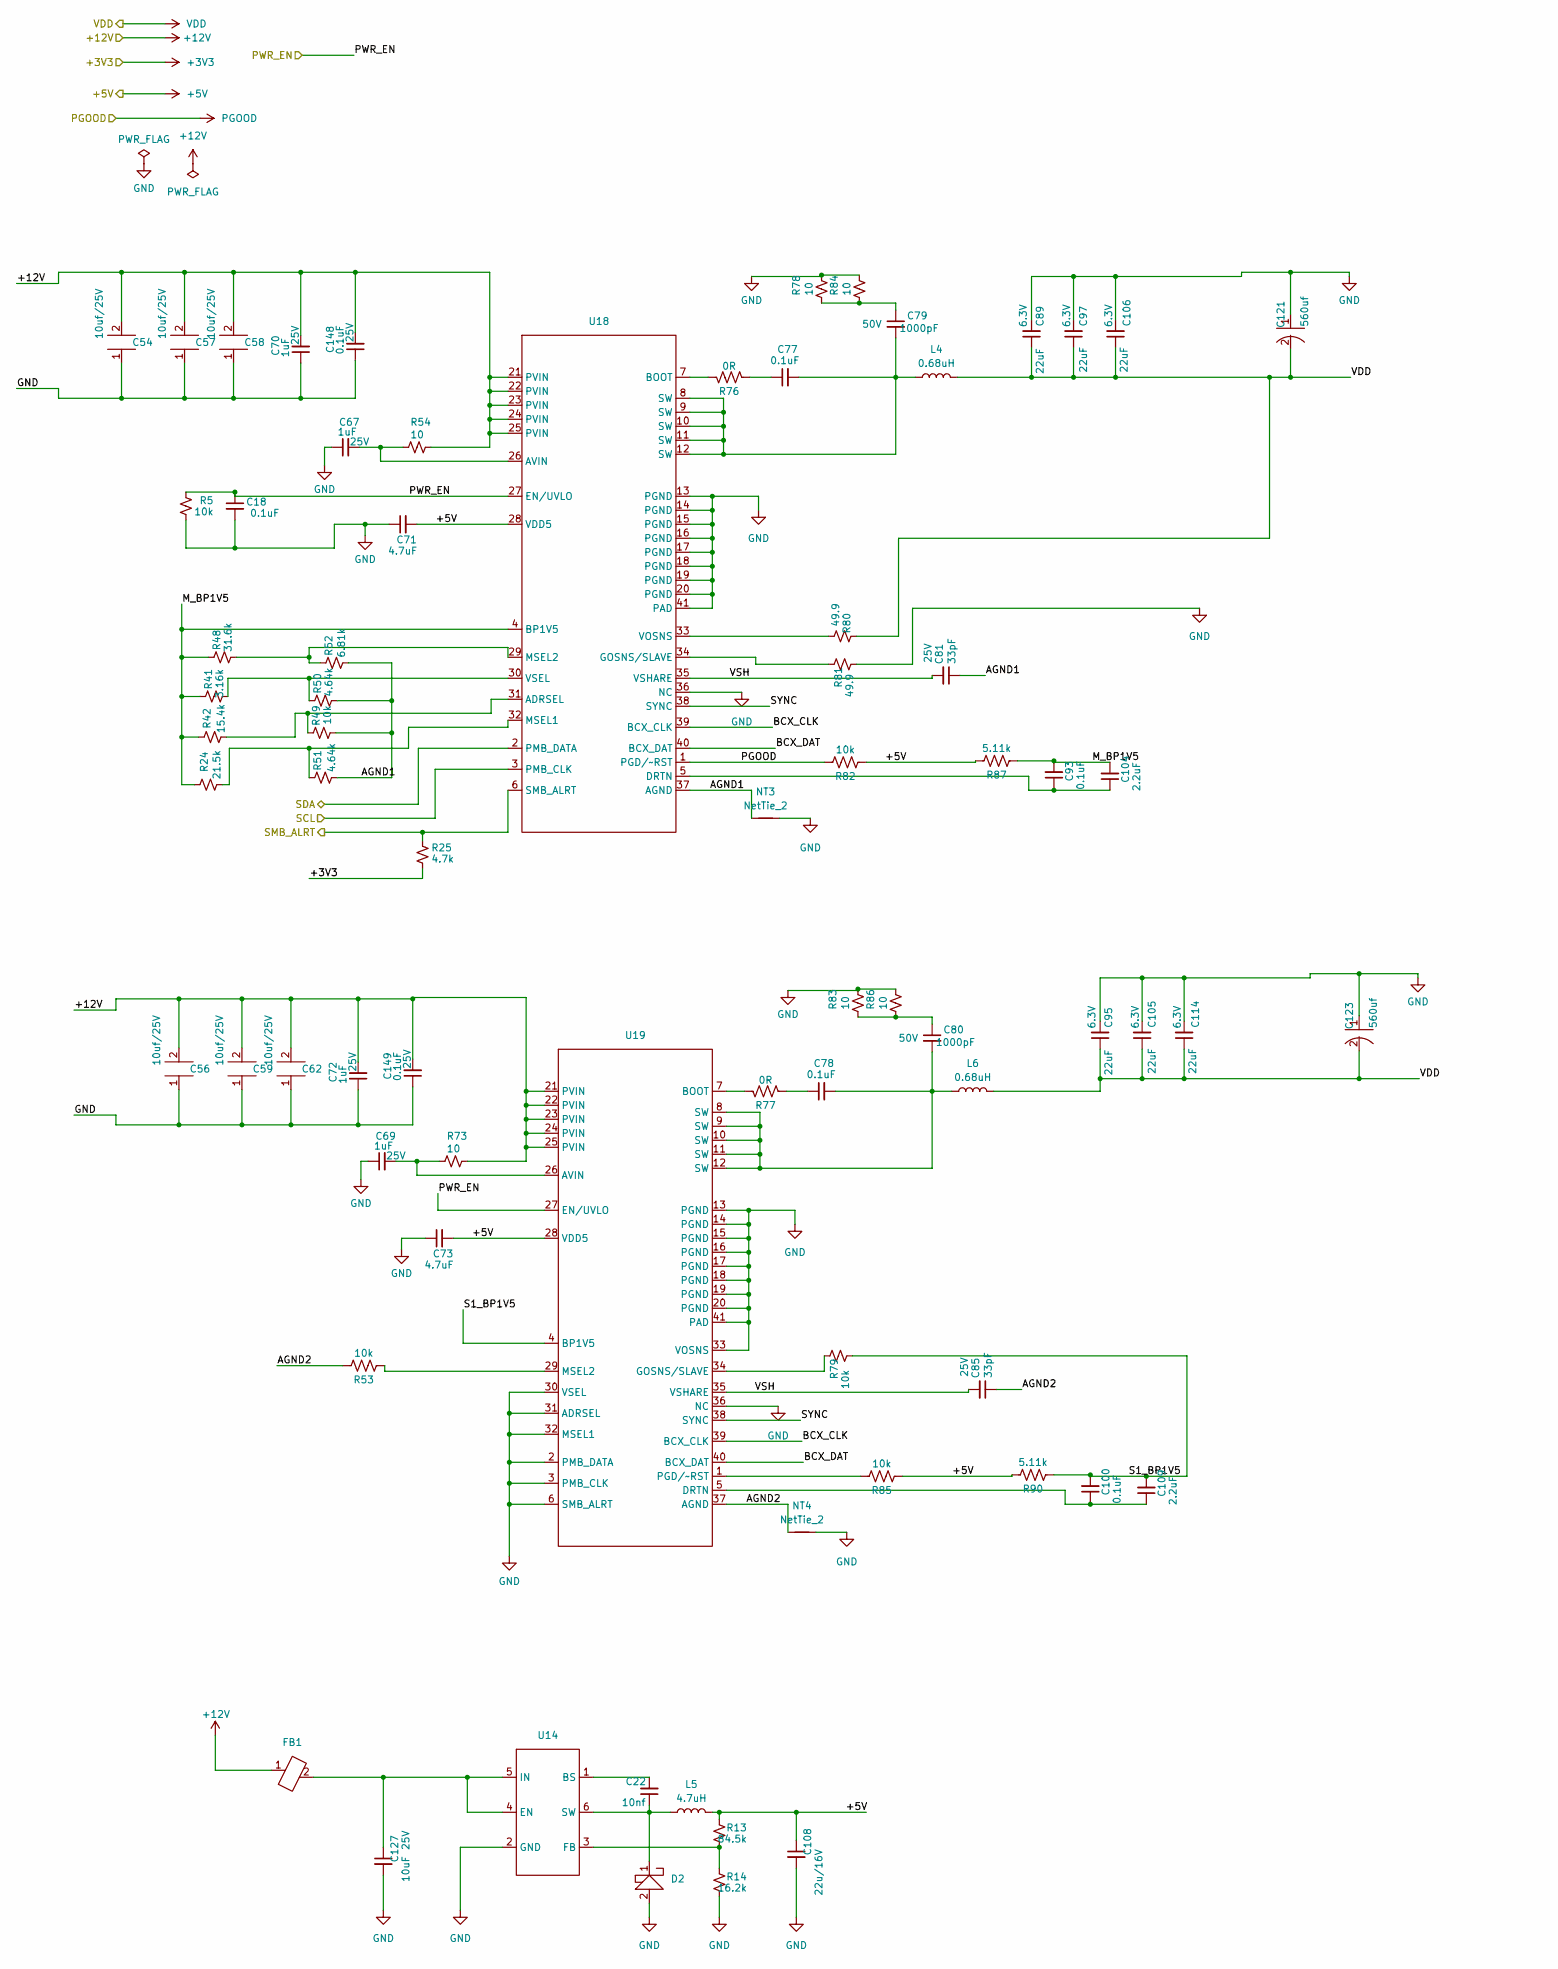
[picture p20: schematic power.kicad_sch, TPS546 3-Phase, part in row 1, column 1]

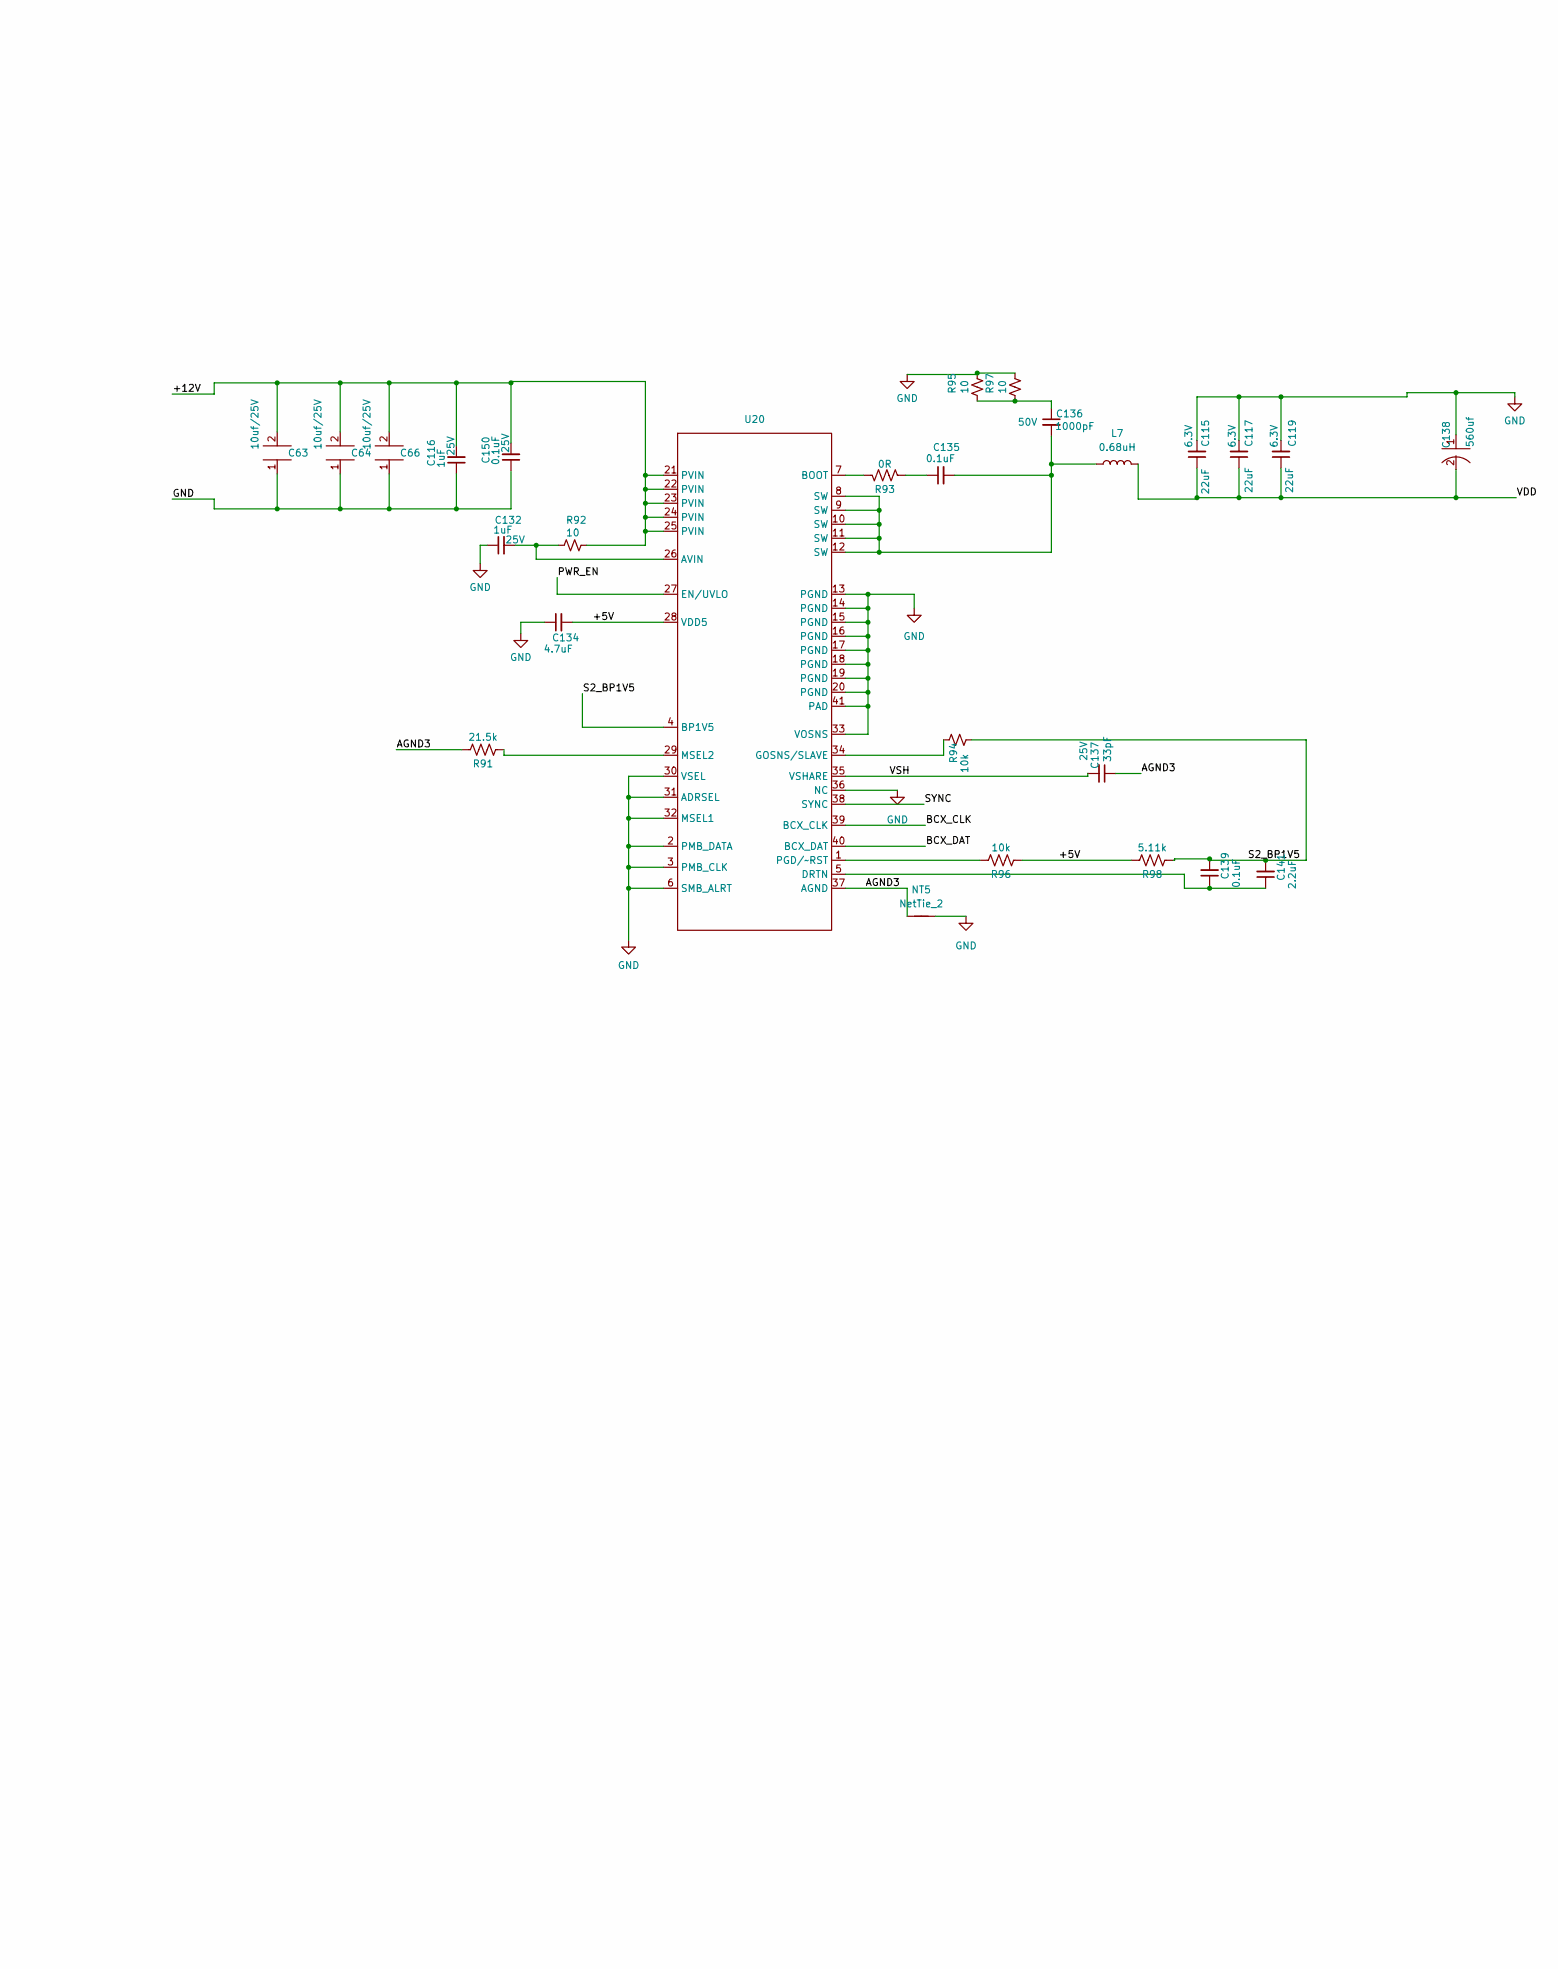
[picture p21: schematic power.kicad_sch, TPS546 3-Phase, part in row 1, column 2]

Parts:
C18, C77, C78, C135: 0.1uF; C_0402_1005Metric; PARTNO KGM05AR71C104KH
C22: 10nf; C_0402_1005Metric; PARTNO GRM188R61E106KA73D
C54, C56, C57, C58, C59, C62, C63, C64, C66: 10uf/25V; C_0805_2012Metric
C67, C69, C70, C72, C116, C132: 1uF; C_0402_1005Metric; Voltage 25V; PARTNO TMK107B7105KA-T
C71, C73, C134: 4.7uF; C_0402_1005Metric; PARTNO GRM155R61A475MEAAD
C79, C80, C136: 1000pF; C_0402_1005Metric; Voltage 50V; PARTNO CC0402JRNPO9BN101
C81, C85, C137: 33pF; C_0402_1005Metric; Voltage 25V; PARTNO KGM05ACG1E330JH
C89, C95, C97, C105, C106, C114, C115, C117, C119: 22uF; C_1206_3216Metric; Voltage 6.3V; PARTNO CL31A107MQHNNNE
C93, C100, C139: 0.1uF; C_0402_1005Metric; PARTNO GRM155R61A475MEAAD
C104, C109, C141: 2.2uF; C_0402_1005Metric; PARTNO GRM155R61A475MEAAD
C108: 22u/16V; C_0603_1608Metric; PARTNO GRM188R61E106KA73D
C121, C123, C138: 560uf; D7.3xL4.3
C127: 10uF; C_0603_1608Metric; Voltage 25V; PARTNO GRM188R61E106KA73D
C148, C149, C150: 0.1uF; C_0402_1005Metric; Voltage 25V; PARTNO TMK107B7105KA-T
D2: D_SOD-128
FB1: FB0603
L4, L6, L7: 0.68uH; SLC1175-271MEC_COC; PARTNO SLC1175-301
L5: 4.7uH; L_Ferrocore_DLG-0703; PARTNO FTC201612S1R5MBCA
NT3, NT4, NT5: NetTie_2; NetTie-2_SMD_Pad0.2mmx1mm
R5, R49: 10k; R_0402_1005Metric; PARTNO RC0402JR-0710KL
R13: 84.5k; R_0402_1005Metric; PARTNO RC0402FR-0752K3L
R14: 16.2k; R_0402_1005Metric; PARTNO RC0402FR-0752K3L
R24: 21.5k; R_0402_1005Metric; PARTNO RC0402JR-0710KL
R25: 4.7k; R_0402_1005Metric; PARTNO RC0402JR-074K7L
R41: 3.16k; R_0402_1005Metric; PARTNO RC0402JR-0710KL
R42: 15.4k; R_0402_1005Metric; PARTNO RC0402JR-0710KL
R48: 31.6k; R_0402_1005Metric; PARTNO RC0402JR-0710KL
R50, R51: 4.64k; R_0402_1005Metric; PARTNO RC0402JR-0710KL
R52: 6.81k; R_0402_1005Metric; PARTNO RC0402JR-0710KL
R53, R82, R85, R96: 10k; R_0402_1005Metric; PARTNO RC0402DR-0710KL; LCSC C471764
R54, R73, R78, R83, R84, R86, R92, R95, R97: 10; R_0402_1005Metric; PARTNO RC0402FR-0710RL
R76, R77, R93: 0R; R_0402_1005Metric; PARTNO RC0402FR-071KL; LCSC C106235
R79, R94: 10k; R_0402_1005Metric; PARTNO RC0402FR-0749R9L
R80, R81: 49.9; R_0402_1005Metric; PARTNO RC0402FR-0749R9L
R87, R90, R98: 5.11k; R_0402_1005Metric; PARTNO RC0402DR-0710KL; LCSC C471764
R91: 21.5k; R_0402_1005Metric; PARTNO RC0402DR-0710KL; LCSC C471764
U14: SOT-23-6
U18, U19, U20: LQFN40-CLIP

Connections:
+5V: C71.2, C73.2, C108.1, C134.2, L5.2, R13.2, R82.1, R85.1, R87.2, R90.2, R96.1, R98.2, U18.28 (VDD5), U19.28 (VDD5), U20.28 (VDD5); also elsewhere on the board
+12V: C54.2, C56.2, C57.2, C58.2, C59.2, C62.2, C63.2, C64.2, C66.2, C70.2, C72.2, C116.2, C148.2, C149.2, C150.2, FB1.1, R54.1, R73.1, R92.1, U18.21 (PVIN), U18.22 (PVIN), U18.23 (PVIN), U18.24 (PVIN), U18.25 (PVIN), U19.21 (PVIN), U19.22 (PVIN), U19.23 (PVIN), U19.24 (PVIN), U19.25 (PVIN), U20.21 (PVIN), U20.22 (PVIN), U20.23 (PVIN), U20.24 (PVIN), U20.25 (PVIN); also elsewhere on the board
/T-Display-S3/SCL: U18.3 (PMB_CLK); also elsewhere on the board
/T-Display-S3/SDA: U18.2 (PMB_DATA); also elsewhere on the board
/T-Display-S3/SMB_ALRT: R25.1, U18.6 (SMB_ALRT); also elsewhere on the board
/power1/AGND1: C81.1, NT3.2, R49.1, R50.1, R51.1, R52.1, U18.37 (AGND)
/power1/AGND2: C85.1, NT4.2, R53.2, U19.37 (AGND)
/power1/AGND3: C137.1, NT5.2, R91.2, U20.37 (AGND)
/power1/BCX_CLK: U18.39 (BCX_CLK), U19.39 (BCX_CLK), U20.39 (BCX_CLK)
/power1/BCX_DAT: U18.40 (BCX_DAT), U19.40 (BCX_DAT), U20.40 (BCX_DAT)
/power1/M_BP1V5: C93.2, C104.2, R24.2, R41.2, R42.2, R48.2, R87.1, U18.4 (BP1V5)
/power1/PWR_EN: C18.1, R5.2, U18.27 (EN/UVLO), U19.27 (EN/UVLO), U20.27 (EN/UVLO); also elsewhere on the board
/power1/S1_BP1V5: C100.2, C109.2, R79.2, R90.1, U19.4 (BP1V5)
/power1/S2_BP1V5: C139.2, C141.2, R94.2, R98.1, U20.4 (BP1V5)
/power1/SYNC: U18.38 (SYNC), U19.38 (SYNC), U20.38 (SYNC)
/power1/VSH: C81.2, C85.2, C137.2, U18.35 (VSHARE), U19.35 (VSHARE), U20.35 (VSHARE)
unnamed: C77.1, R76.2
unnamed: C77.2, C79.2, L4.1, U18.8 (SW), U18.9 (SW), U18.10 (SW), U18.11 (SW), U18.12 (SW)
unnamed: C78.1, R77.2
unnamed: C78.2, C80.2, L6.1, U19.8 (SW), U19.9 (SW), U19.10 (SW), U19.11 (SW), U19.12 (SW)
unnamed: C79.1, R78.2, R84.2
unnamed: C80.1, R83.2, R86.2
unnamed: C135.1, R93.2
unnamed: C135.2, C136.2, L7.1, U20.8 (SW), U20.9 (SW), U20.10 (SW), U20.11 (SW), U20.12 (SW)
unnamed: C136.1, R95.2, R97.2
unnamed: C22.2, U14.1 (BS)
unnamed: C127.1, FB1.2, U14.4 (EN), U14.5 (IN)
unnamed: R13.1, R14.2, U14.3 (FB)
unnamed: C22.1, D2.1, L5.1, U14.6 (SW)
unnamed: R42.1, R49.2, U18.31 (ADRSEL)
unnamed: C67.2, R54.2, U18.26 (AVIN)
unnamed: R76.1, U18.7 (BOOT)
unnamed: C93.1, C104.1, U18.5 (DRTN)
unnamed: R81.1, U18.34 (GOSNS/SLAVE)
unnamed: R24.1, R51.2, U18.32 (MSEL1)
unnamed: R48.1, R52.2, U18.29 (MSEL2)
unnamed: R80.2, U18.33 (VOSNS)
unnamed: R41.1, R50.2, U18.30 (VSEL)
unnamed: C69.2, R73.2, U19.26 (AVIN)
unnamed: R77.1, U19.7 (BOOT)
unnamed: C100.1, C109.1, U19.5 (DRTN)
unnamed: R79.1, U19.34 (GOSNS/SLAVE)
unnamed: R53.1, U19.29 (MSEL2)
unnamed: R85.2, U19.1 (PGD/~RST)
unnamed: C132.2, R92.2, U20.26 (AVIN)
unnamed: R93.1, U20.7 (BOOT)
unnamed: C139.1, C141.1, U20.5 (DRTN)
unnamed: R94.1, U20.34 (GOSNS/SLAVE)
unnamed: R91.1, U20.29 (MSEL2)
unnamed: R96.2, U20.1 (PGD/~RST)
PGOOD: R82.2, U18.1 (PGD/~RST); also elsewhere on the board
VDD: C89.1, C95.1, C97.1, C105.1, C106.1, C114.1, C115.1, C117.1, C119.1, C121.2, C123.2, C138.2, L4.2, L6.2, L7.2, R80.1; also elsewhere on the board

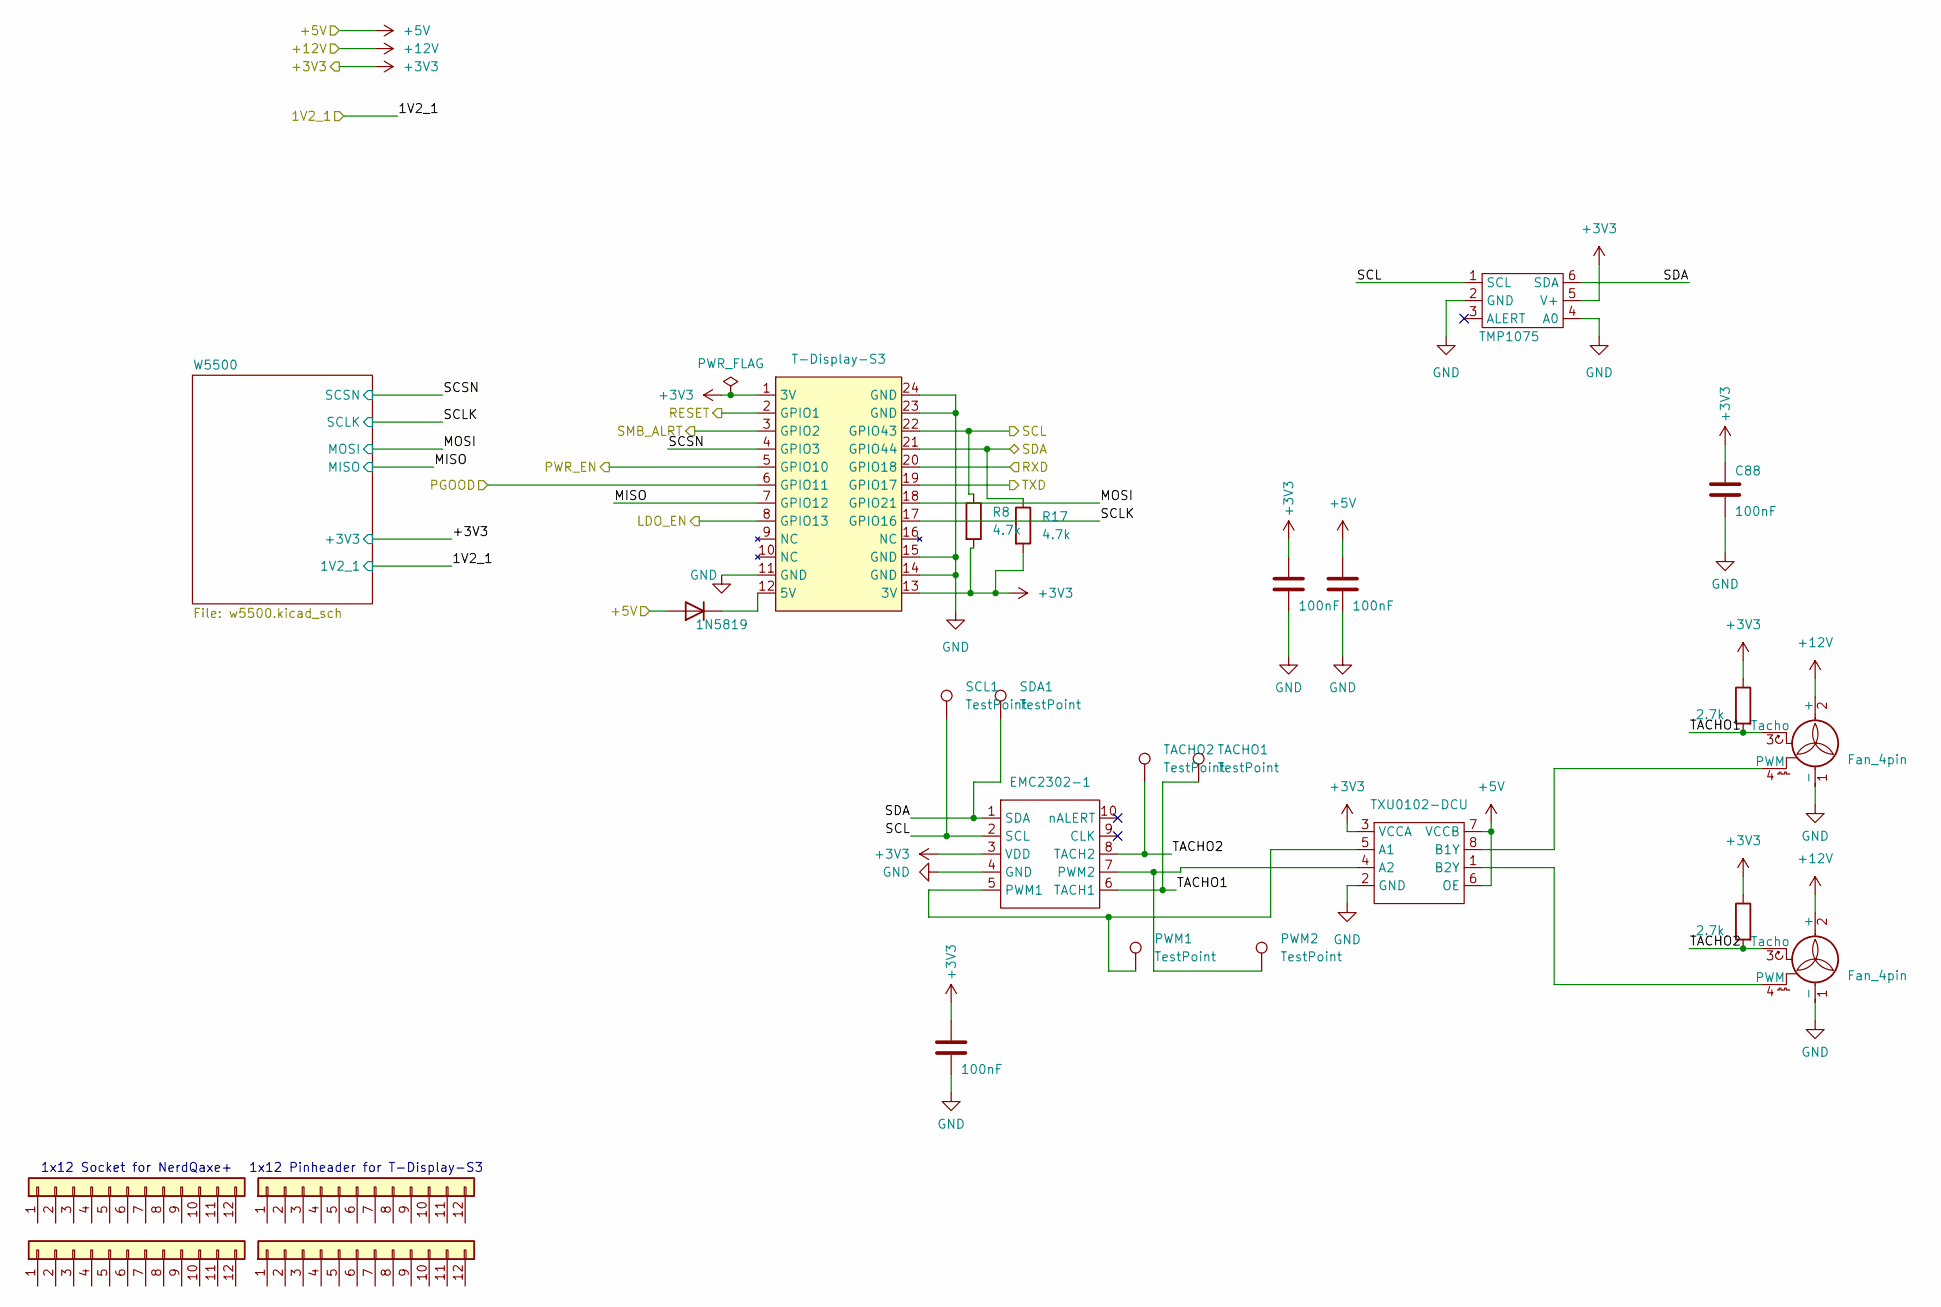
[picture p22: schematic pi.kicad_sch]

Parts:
C88, C96, C102, C103: 100nF; C_0402_1005Metric; PARTNO CC0402KRX7R7BB104; LCSC C60474
D3: 1N5819; D_SOD-123; PARTNO 1N5819HWQ-7-F
J5, J6: Conn_01x12-Socket; PARTNO 61301211821
J7, J8: Conn_01x12-Header
M1, M2: Fan_4pin; FanPinHeader_1x04_P2.54mm_Vertical; PARTNO 0470531000
PWM1, PWM2: TestPoint; TestPoint_Pad_D1.5mm
R8, R17: 4.7k; R_0402_1005Metric
R33, R35: 2.7k; R_0402_1005Metric; PARTNO RC0402FR-072K7L; LCSC C138017
SCL1: TestPoint; TestPoint_Pad_D1.5mm
SDA1: TestPoint; TestPoint_Pad_D1.5mm
TACHO1, TACHO2: TestPoint; TestPoint_Pad_D1.5mm
U30: T-Display-S3
U32: EMC2302-1; MSOP-10_3x3mm_P0.5mm; PARTNO EMC2302-1-AIZL-TR
U33: TXU0102-DCU; VSSOP-8_2.3x2mm_P0.5mm; PARTNO TXU0102DCUR
U37: TMP1075; TMP1075-DRL; PARTNO TMP1075NDRLR

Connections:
+5V: C96.1, D3.2 (A), U33.6 (OE), U33.7 (VCCB); also elsewhere on the board
+12V: M1.2 (+), M2.2 (+); also elsewhere on the board
/BM1373/RESET: U30.2 (GPIO1); also elsewhere on the board
/BM1373/RXD: U30.20 (GPIO18); also elsewhere on the board
/BM1373/TXD: U30.19 (GPIO17); also elsewhere on the board
/T-Display-S3/LDO_EN: U30.8 (GPIO13)
/T-Display-S3/MISO: U30.7 (GPIO12); also elsewhere on the board
/T-Display-S3/MOSI: U30.18 (GPIO21); also elsewhere on the board
/T-Display-S3/SCL: R8.1, SCL1.1, U30.22 (GPIO43), U32.2 (SCL), U37.1 (SCL); also elsewhere on the board
/T-Display-S3/SCLK: U30.17 (GPIO16); also elsewhere on the board
/T-Display-S3/SCSN: U30.4 (GPIO3); also elsewhere on the board
/T-Display-S3/SDA: R17.1, SDA1.1, U30.21 (GPIO44), U32.1 (SDA), U37.6 (SDA); also elsewhere on the board
/T-Display-S3/SMB_ALRT: U30.3 (GPIO2); also elsewhere on the board
/T-Display-S3/TACHO1: M1.3 (Tacho), R33.2, TACHO1.1 (1_1), U32.6 (TACH1)
/T-Display-S3/TACHO2: M2.3 (Tacho), R35.2, TACHO2.1 (1_1), U32.8 (TACH2)
/power1/PWR_EN: U30.5 (GPIO10); also elsewhere on the board
unnamed: D3.1 (K), U30.12 (5V)
unnamed: M1.4 (PWM), U33.8 (B1Y)
unnamed: M2.4 (PWM), U33.1 (B2Y)
unnamed: PWM1.1 (1_1), U32.5 (PWM1), U33.5 (A1)
unnamed: PWM2.1 (1_1), U32.7 (PWM2), U33.4 (A2)
PGOOD: U30.6 (GPIO11); also elsewhere on the board

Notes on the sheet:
1x12 Socket for NerdQaxe+
1x12 Pinheader for T-Display-S3

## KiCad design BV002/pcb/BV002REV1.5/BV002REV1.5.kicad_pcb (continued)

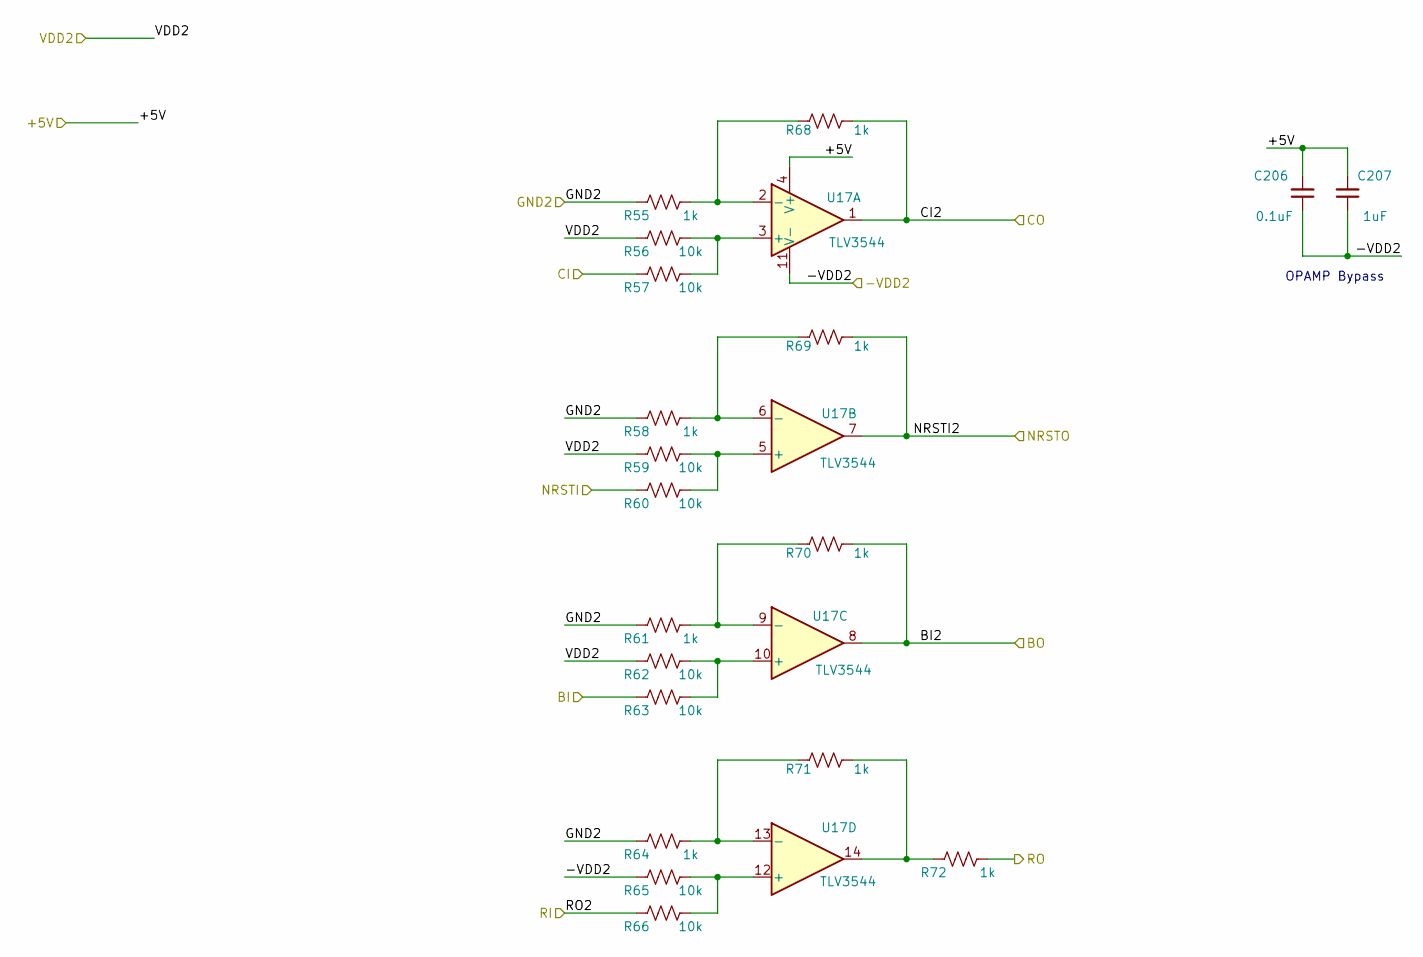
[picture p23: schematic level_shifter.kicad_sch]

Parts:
C206: 0.1uF; C_0402_1005Metric; PARTNO KGM05AR71C104KH
C207: 1uF; C_0402_1005Metric; PARTNO EMK105BJ105MV-F
R55, R58, R61, R64, R68, R69, R70, R71, R72: 1k; R_0402_1005Metric; PARTNO RC0402FR-071KL
R56, R57, R59, R60, R62, R63, R65, R66: 10k; R_0402_1005Metric; PARTNO RC0402JR-0710KL
U17: TLV3544; TSSOP-14_4.4x5mm_P0.65mm; PARTNO TLV3544IPWR

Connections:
+5V: C206.2, C207.2, U17.4 (V+); also elsewhere on the board
/BM1373/Level Shifter/BI: R63.1; also elsewhere on the board
/BM1373/Level Shifter/BI2: R70.1, U17.8; also elsewhere on the board
/BM1373/Level Shifter/CI: R57.1; also elsewhere on the board
/BM1373/Level Shifter/CI2: R68.1, U17.1; also elsewhere on the board
/BM1373/Level Shifter/NRSTI: R60.1; also elsewhere on the board
/BM1373/Level Shifter/NRSTI2: R69.1, U17.7; also elsewhere on the board
/BM1373/Level Shifter/RO: R72.1; also elsewhere on the board
/BM1373/Level Shifter/RO2: R66.1; also elsewhere on the board
unnamed: R71.1, R72.2, U17.14
unnamed: R56.1, R57.2, U17.3 (+)
unnamed: R55.1, R68.2, U17.2 (-)
unnamed: R59.2, R60.2, U17.5 (+)
unnamed: R58.1, R69.2, U17.6 (-)
unnamed: R62.2, R63.2, U17.10 (+)
unnamed: R61.1, R70.2, U17.9 (-)
unnamed: R65.2, R66.2, U17.12 (+)
unnamed: R64.1, R71.2, U17.13 (-)
VDD: R56.2, R59.1, R62.1; also elsewhere on the board
VDD1: R55.2, R58.2, R61.2, R64.2; also elsewhere on the board

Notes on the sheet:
OPAMP Bypass

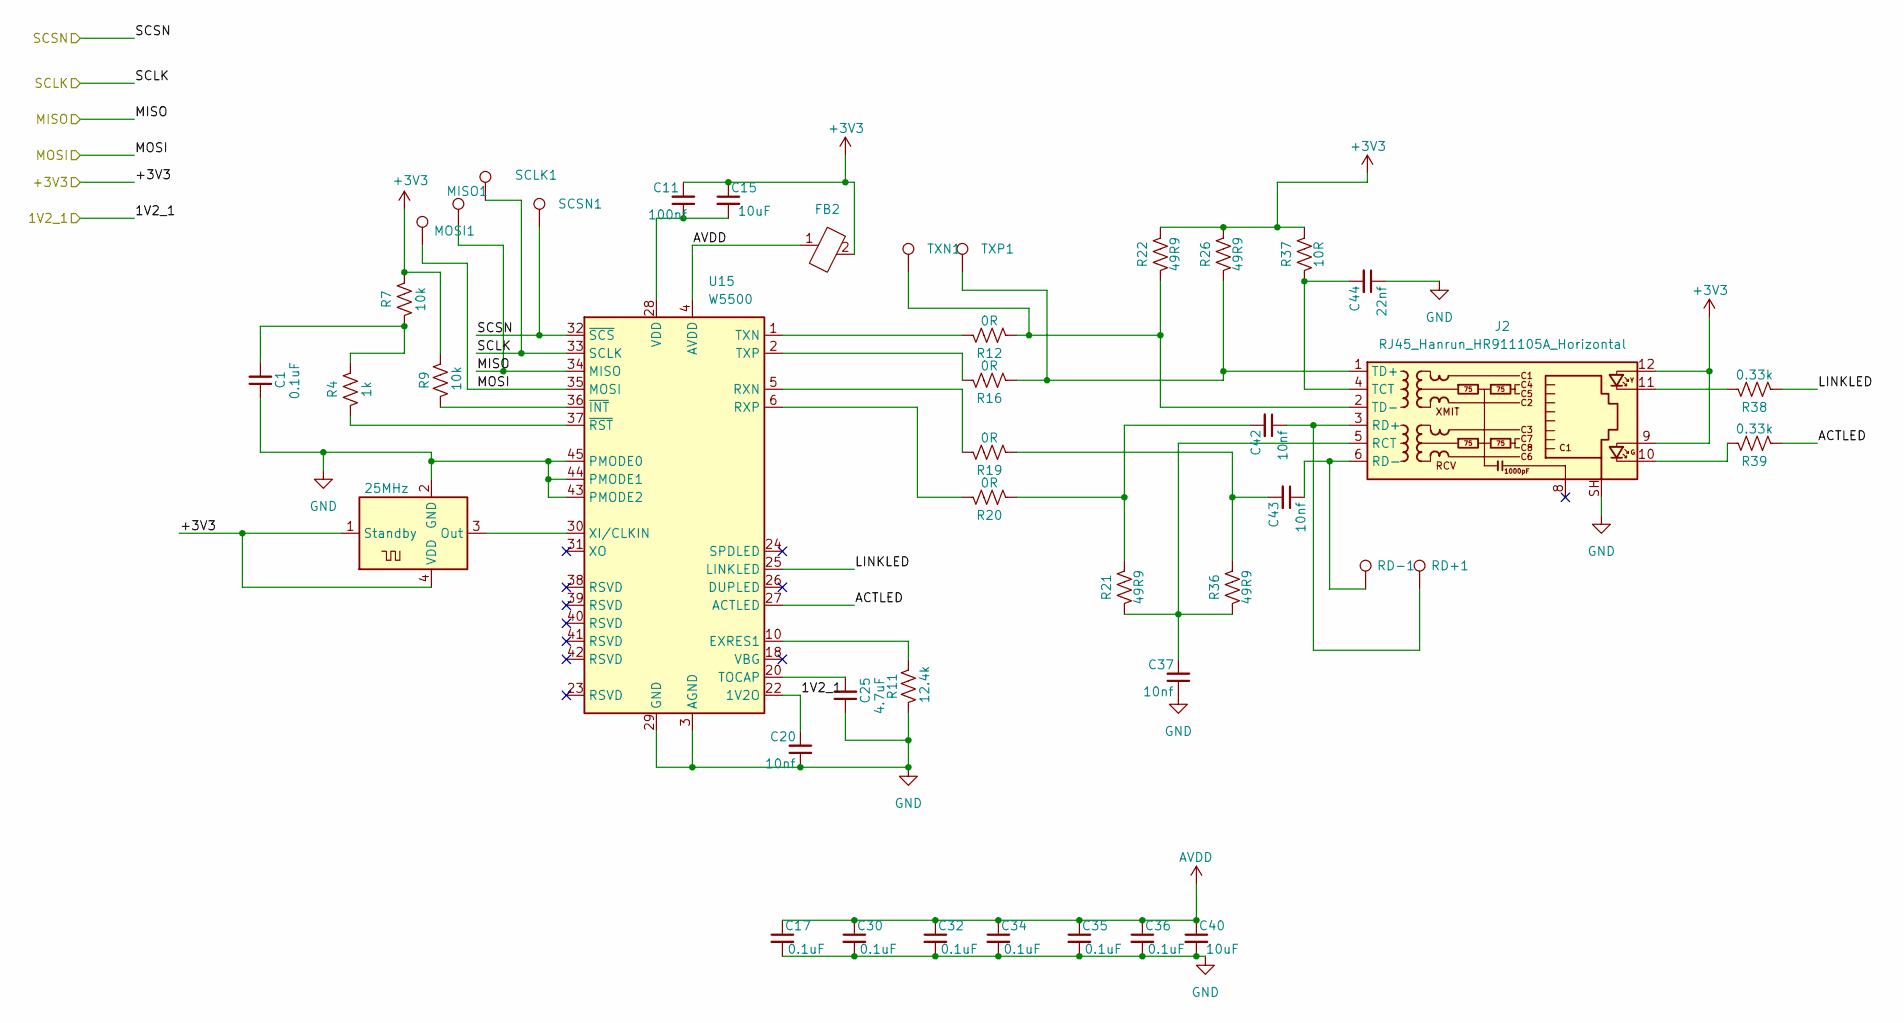
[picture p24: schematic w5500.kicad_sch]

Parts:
C1: 0.1uF; C_0402_1005Metric; PARTNO GRM155R61A475MEAAD
C11: 100nf; C_0402_1005Metric; PARTNO GRM188R61E106KA73D
C15, C40: 10uF; C_0603_1608Metric; PARTNO CL10A106MO8NQNC; LCSC C92487 Hot
C17, C30, C32, C34, C35, C36: 0.1uF; C_0603_1608Metric; PARTNO CL10A106MO8NQNC; LCSC C92487 Hot
C20, C37, C42, C43: 10nf; C_0402_1005Metric; PARTNO GRM188R61E106KA73D
C25: 4.7uF; C_0402_1005Metric; PARTNO GRM155R61A475MEAAD
C44: 22nf; C_0402_1005Metric; PARTNO GRM188R61E106KA73D
FB2: D_0201_0603Metric
J2: RJ45_Hanrun_HR911105A_Horizontal
MISO1: TestPoint_Pad_D1.5mm
MOSI1: TestPoint_Pad_D1.5mm
R4: 1k; R_0402_1005Metric; PARTNO RC0402FR-071KL; LCSC C106235
R7: 10k; R_0402_1005Metric; PARTNO RC0402FR-071KL; LCSC C106235
R9: 10k; R_0402_1005Metric; PARTNO RC0402FR-072KL; LCSC C60488
R11: 12.4k; R_0402_1005Metric; PARTNO RC0402FR-072KL; LCSC C60488
R12, R16, R19, R20: 0R; R_0402_1005Metric; PARTNO RC0402FR-071KL; LCSC C106235
R21, R22, R26, R36: 49R9; R_0402_1005Metric; PARTNO RC0402FR-071KL; LCSC C106235
R37: 10R; R_0402_1005Metric; PARTNO RC0402FR-071KL; LCSC C106235
R38, R39: 0.33k; R_0402_1005Metric; PARTNO RC0402FR-071KL; LCSC C106235
RD+1: TestPoint_Pad_D1.5mm
RD-1: TestPoint_Pad_D1.5mm
SCLK1: TestPoint_Pad_D1.5mm
SCSN1: TestPoint_Pad_D1.5mm
TXN1: TestPoint_Pad_D1.5mm
TXP1: TestPoint_Pad_D1.5mm
U2: 25MHz; Oscillator_SMD_EuroQuartz_XO32-4Pin_3.2x2.5mm; PARTNO SX3M25.000E20F30THN
U15: W5500; LQFP-48_7x7mm_P0.5mm

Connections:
1V2_1: C20.2, U15.22 (1V2O); also elsewhere on the board
/T-Display-S3/MISO: MISO1.1 (1_1), U15.34 (MISO); also elsewhere on the board
/T-Display-S3/MOSI: MOSI1.1 (1_1), U15.35 (MOSI); also elsewhere on the board
/T-Display-S3/SCLK: SCLK1.1 (1_1), U15.33 (SCLK); also elsewhere on the board
/T-Display-S3/SCSN: SCSN1.1 (1_1), U15.32 (~SCS); also elsewhere on the board
/T-Display-S3/W5500/ACTLED: R39.2, U15.27 (ACTLED)
/T-Display-S3/W5500/LINKLED: R38.2, U15.25 (LINKLED)
unnamed: C1.2, R4.1, R7.2
unnamed: C42.2, R20.2, R21.1
unnamed: C43.2, R19.2, R36.1
unnamed: J2.10, R39.1
unnamed: J2.11, R38.1
unnamed: C37.2, J2.5 (RCT), R21.2, R36.2
unnamed: C42.1, J2.3 (RD+), RD+1.1 (1_1)
unnamed: C43.1, J2.6 (RD-), RD-1.1 (1_1)
unnamed: C44.2, J2.4 (TCT), R37.2
unnamed: J2.1 (TD+), R16.2, R26.2, TXP1.1 (1_1)
unnamed: J2.2 (TD-), R12.2, R22.2, TXN1.1 (1_1)
unnamed: R11.2, U15.10 (EXRES1)
unnamed: R19.1, U15.5 (RXN)
unnamed: R20.1, U15.6 (RXP)
unnamed: C25.2, U15.20 (TOCAP)
unnamed: R12.1, U15.1 (TXN)
unnamed: R16.1, U15.2 (TXP)
unnamed: C11.1, C15.2, U15.28 (VDD)
unnamed: U2.3 (Out), U15.30 (XI/CLKIN)
unnamed: R9.1, U15.36 (~INT)
unnamed: R4.2, U15.37 (~RST)

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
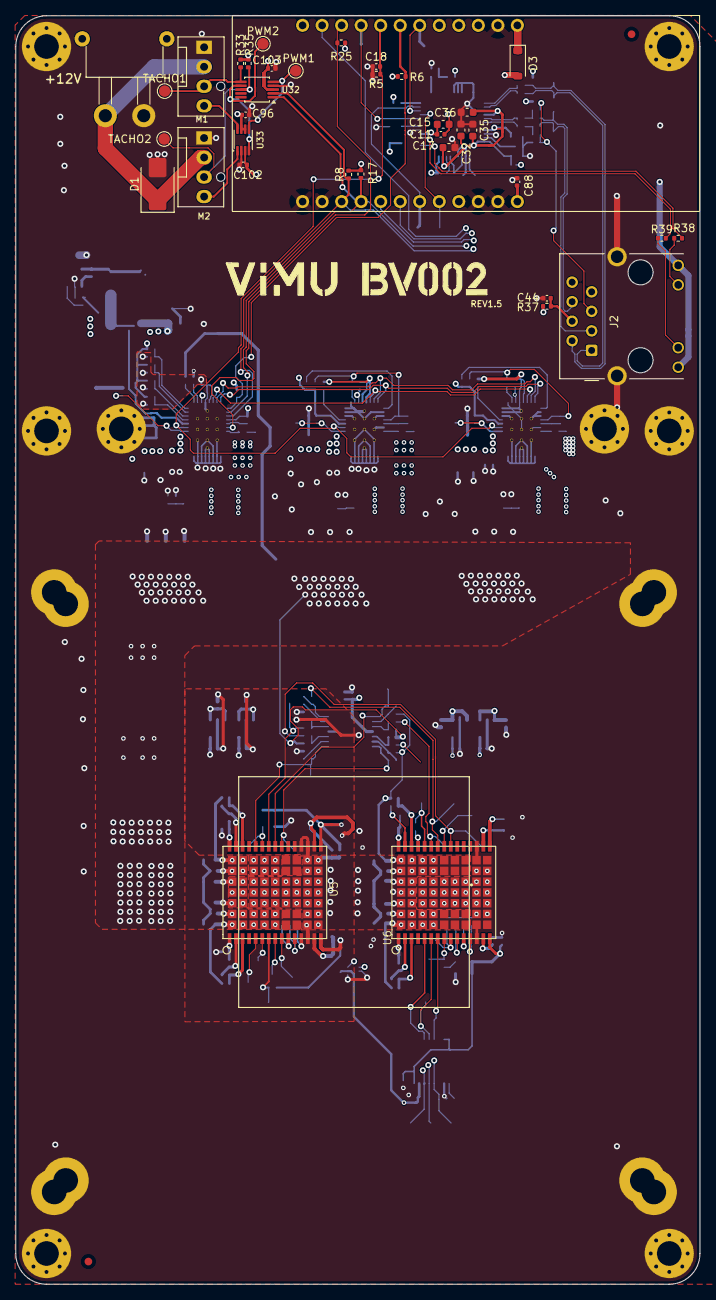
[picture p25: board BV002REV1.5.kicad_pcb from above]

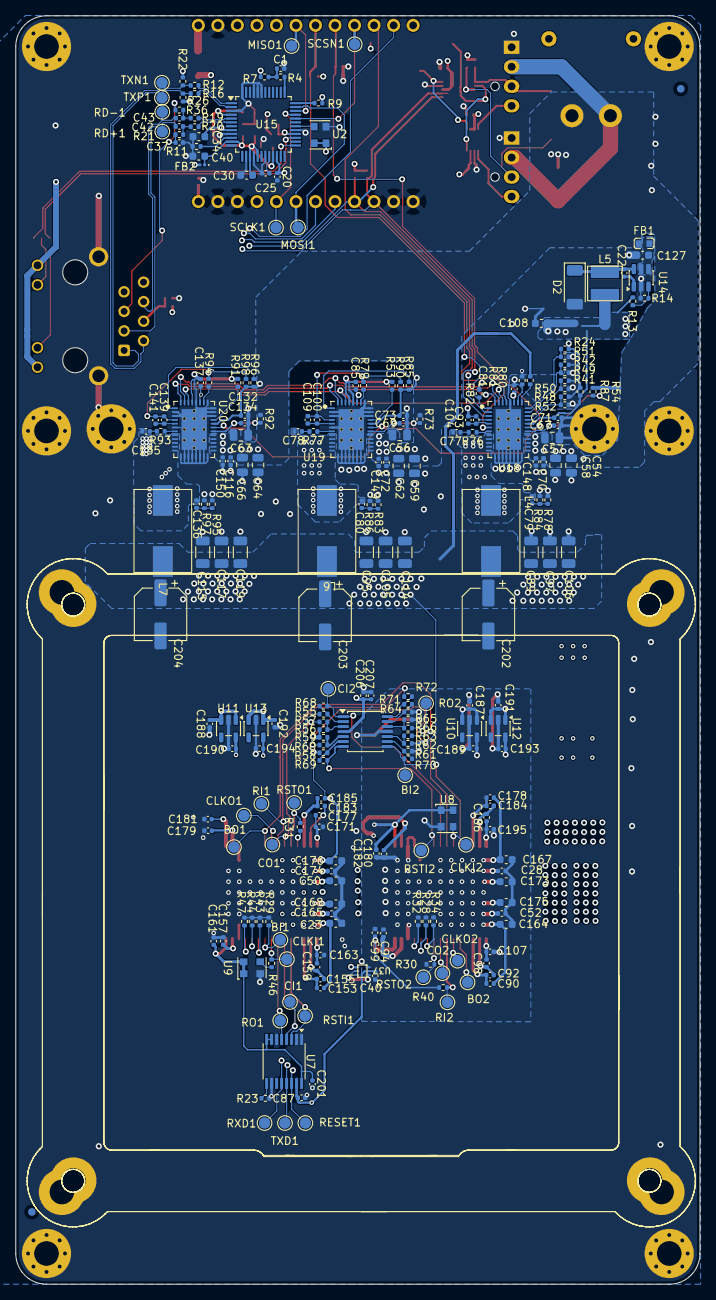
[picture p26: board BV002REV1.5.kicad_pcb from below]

Board: 4 copper layers, 89.0 x 165.0 mm, 289 parts (242 on the bottom side), 147 nets.

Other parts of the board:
C40#2: 10uF; C_0603_1608Metric
C201: 0.1uF; C_0402_1005Metric
C202, C203, C204: 270uF; CP_Elec_6.3x5.9
FID1, FID2, FID3, FID4: Fiducial_1mm_Mask2mm
H7, H8: MountingHole_Pad; MountingHole_3.2mm_M3_Pad_Via
R6: 10k; R_0402_1005Metric

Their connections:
1V2_1: C201.1; also elsewhere on the board
PGOOD: R6.1; also elsewhere on the board
VDD: C202.1, C203.1, C204.1; also elsewhere on the board

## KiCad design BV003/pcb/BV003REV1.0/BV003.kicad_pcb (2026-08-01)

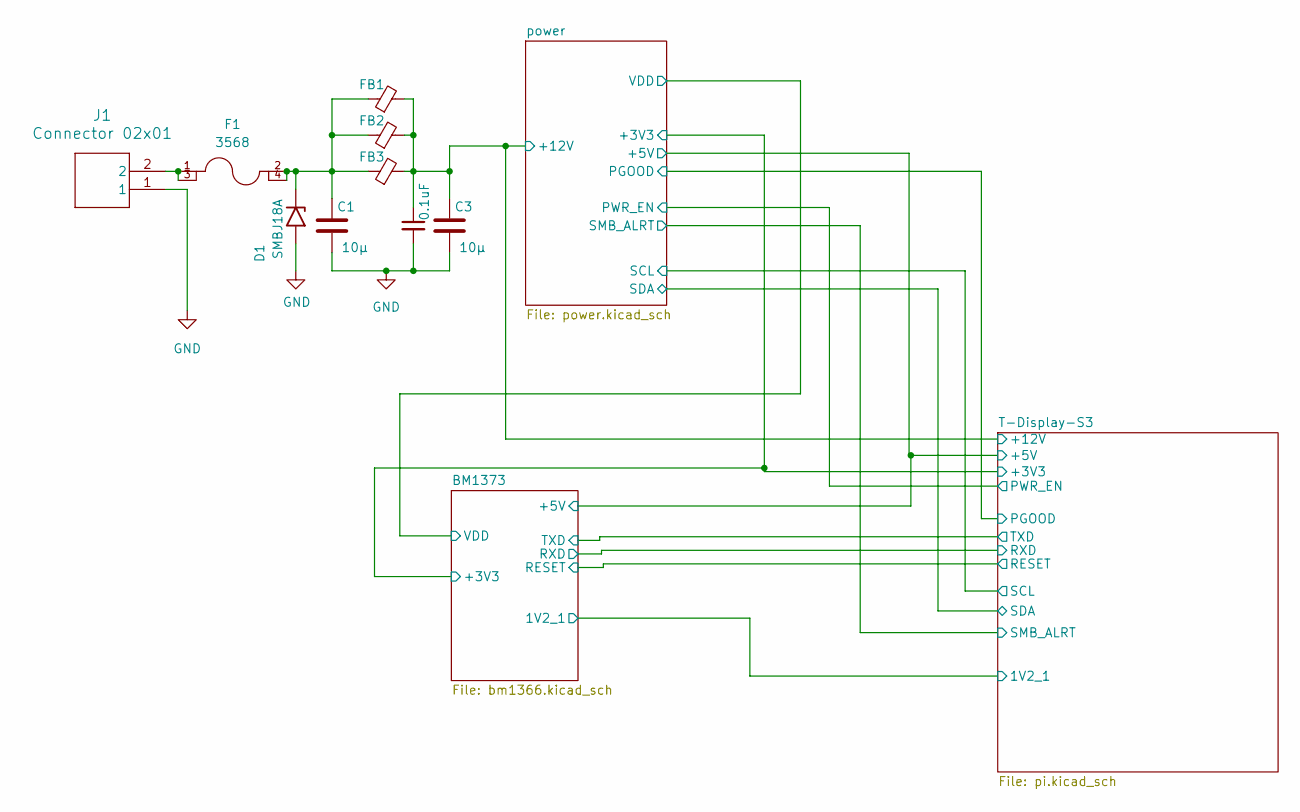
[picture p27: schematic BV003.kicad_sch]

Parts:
C1, C3: 10µ; C_1210_3225Metric_Pad1.33x2.70mm_HandSolder; LCSC C89632
C2: 0.1uF; C_0603_1608Metric; PARTNO CL10A106MO8NQNC; LCSC C92487
D1: SMBJ18A; D_SMB; LCSC C113985
F1: 3568; Fuseholder Blade_3568; LCSC C5249699
FB1, FB2, FB3: BLE32SN120SN1L; R_1210_3225Metric_Pad1.30x2.65mm_HandSolder; LCSC C5597997
J1: Connector 02x01; AMASS_XT60PW-M_1x02_P7.20mm_Horizontal; LCSC C98732

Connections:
GND: C1.2, C2.2, C3.2, D1.2 (A2), J1.1; also elsewhere on the board

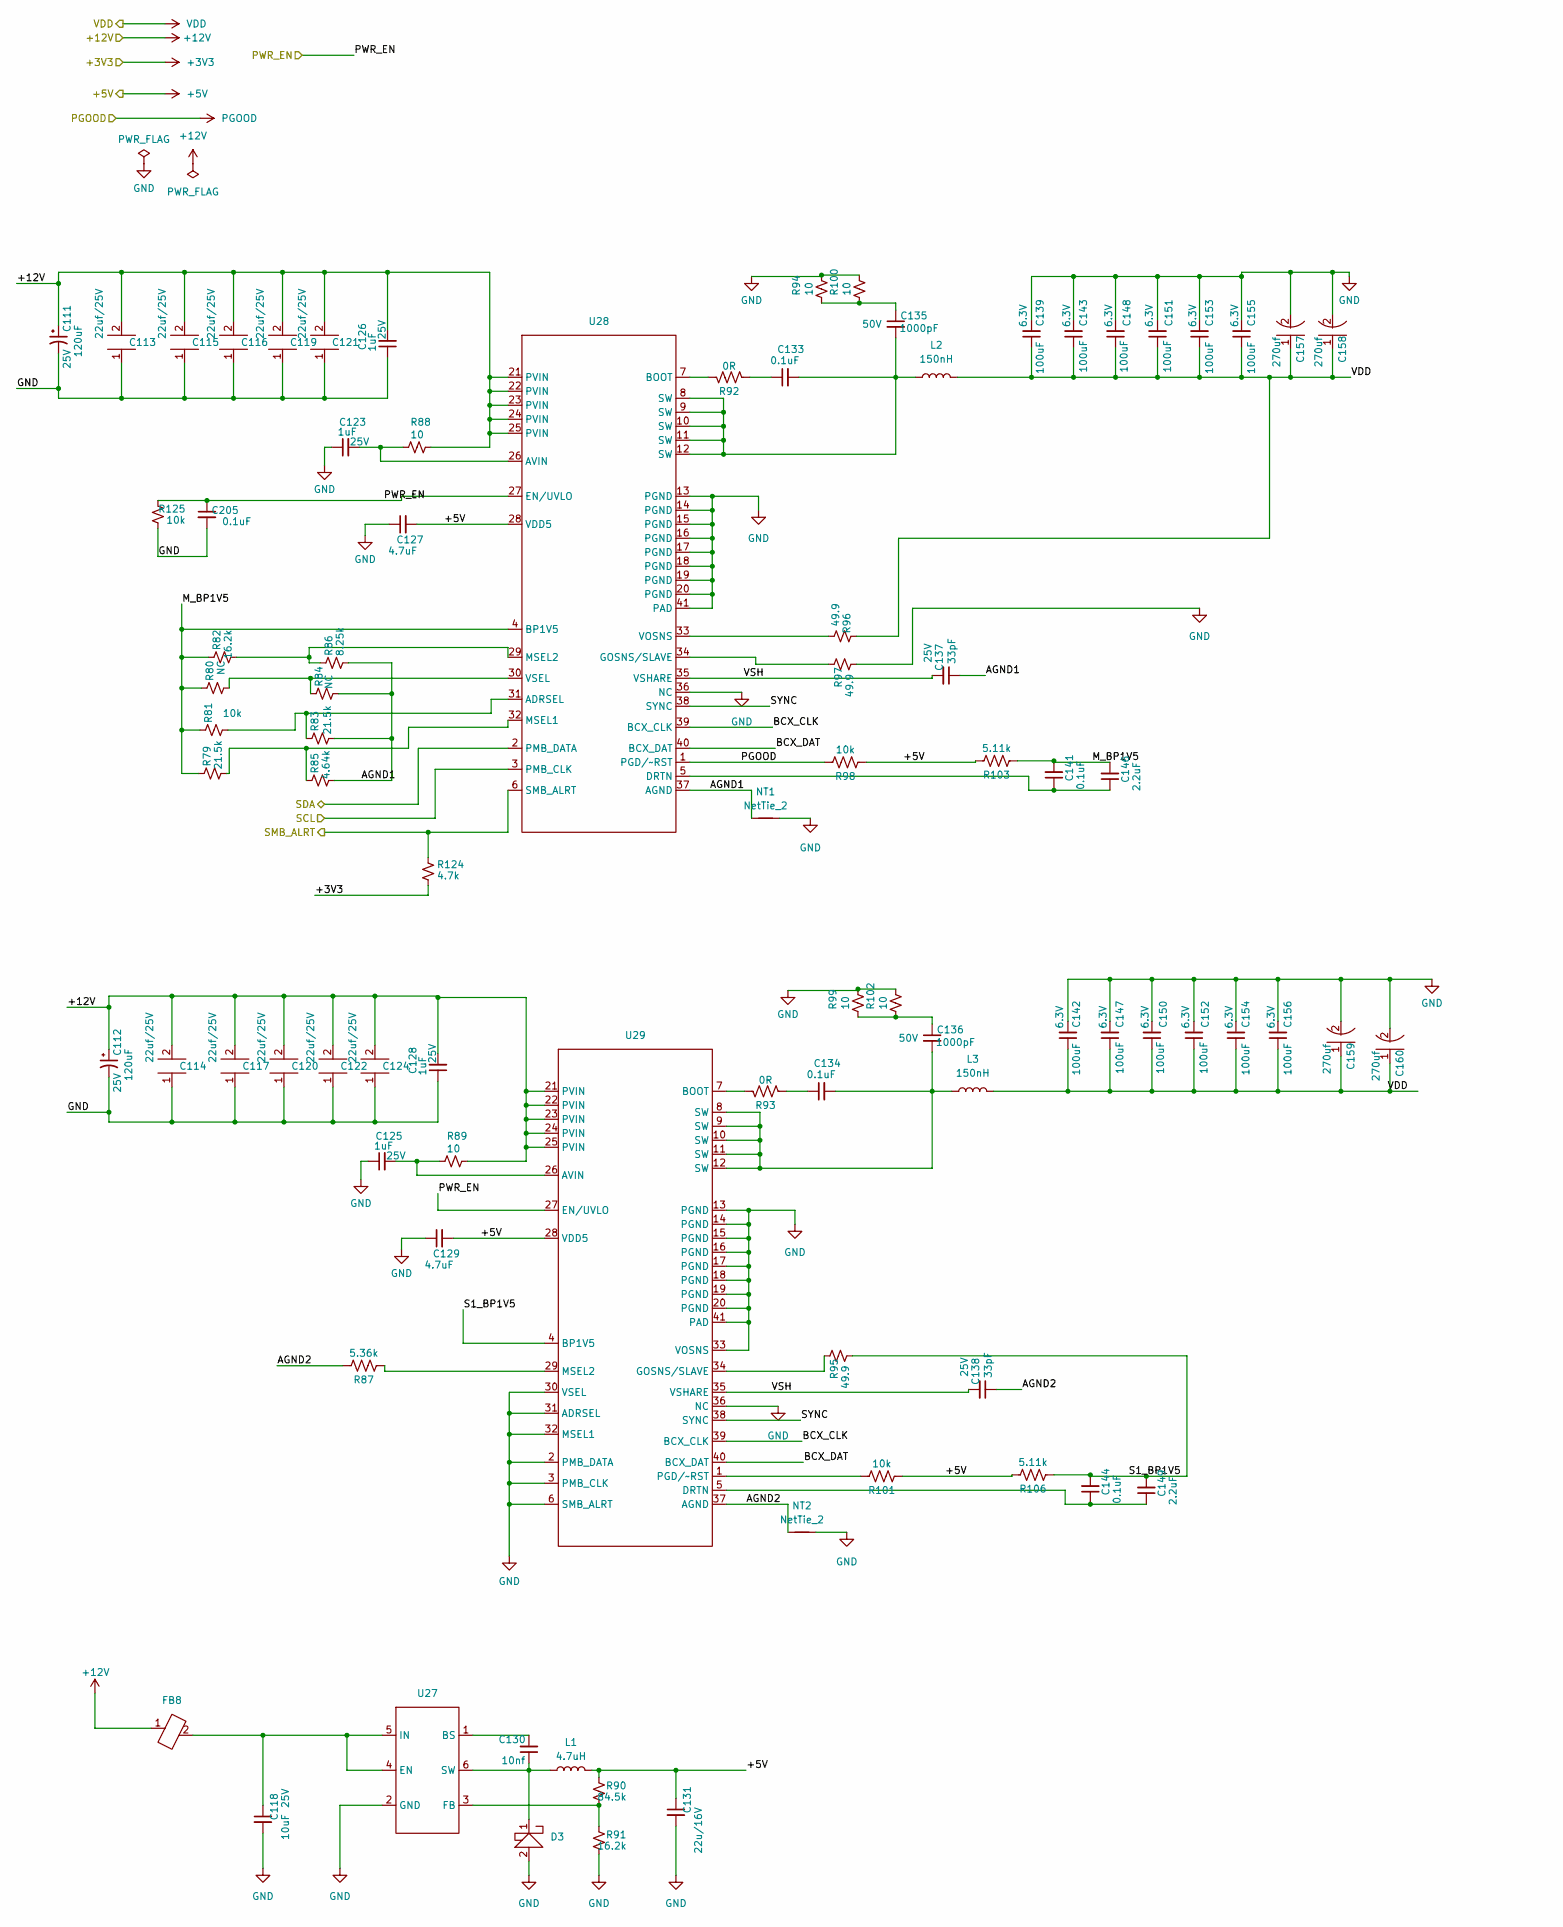
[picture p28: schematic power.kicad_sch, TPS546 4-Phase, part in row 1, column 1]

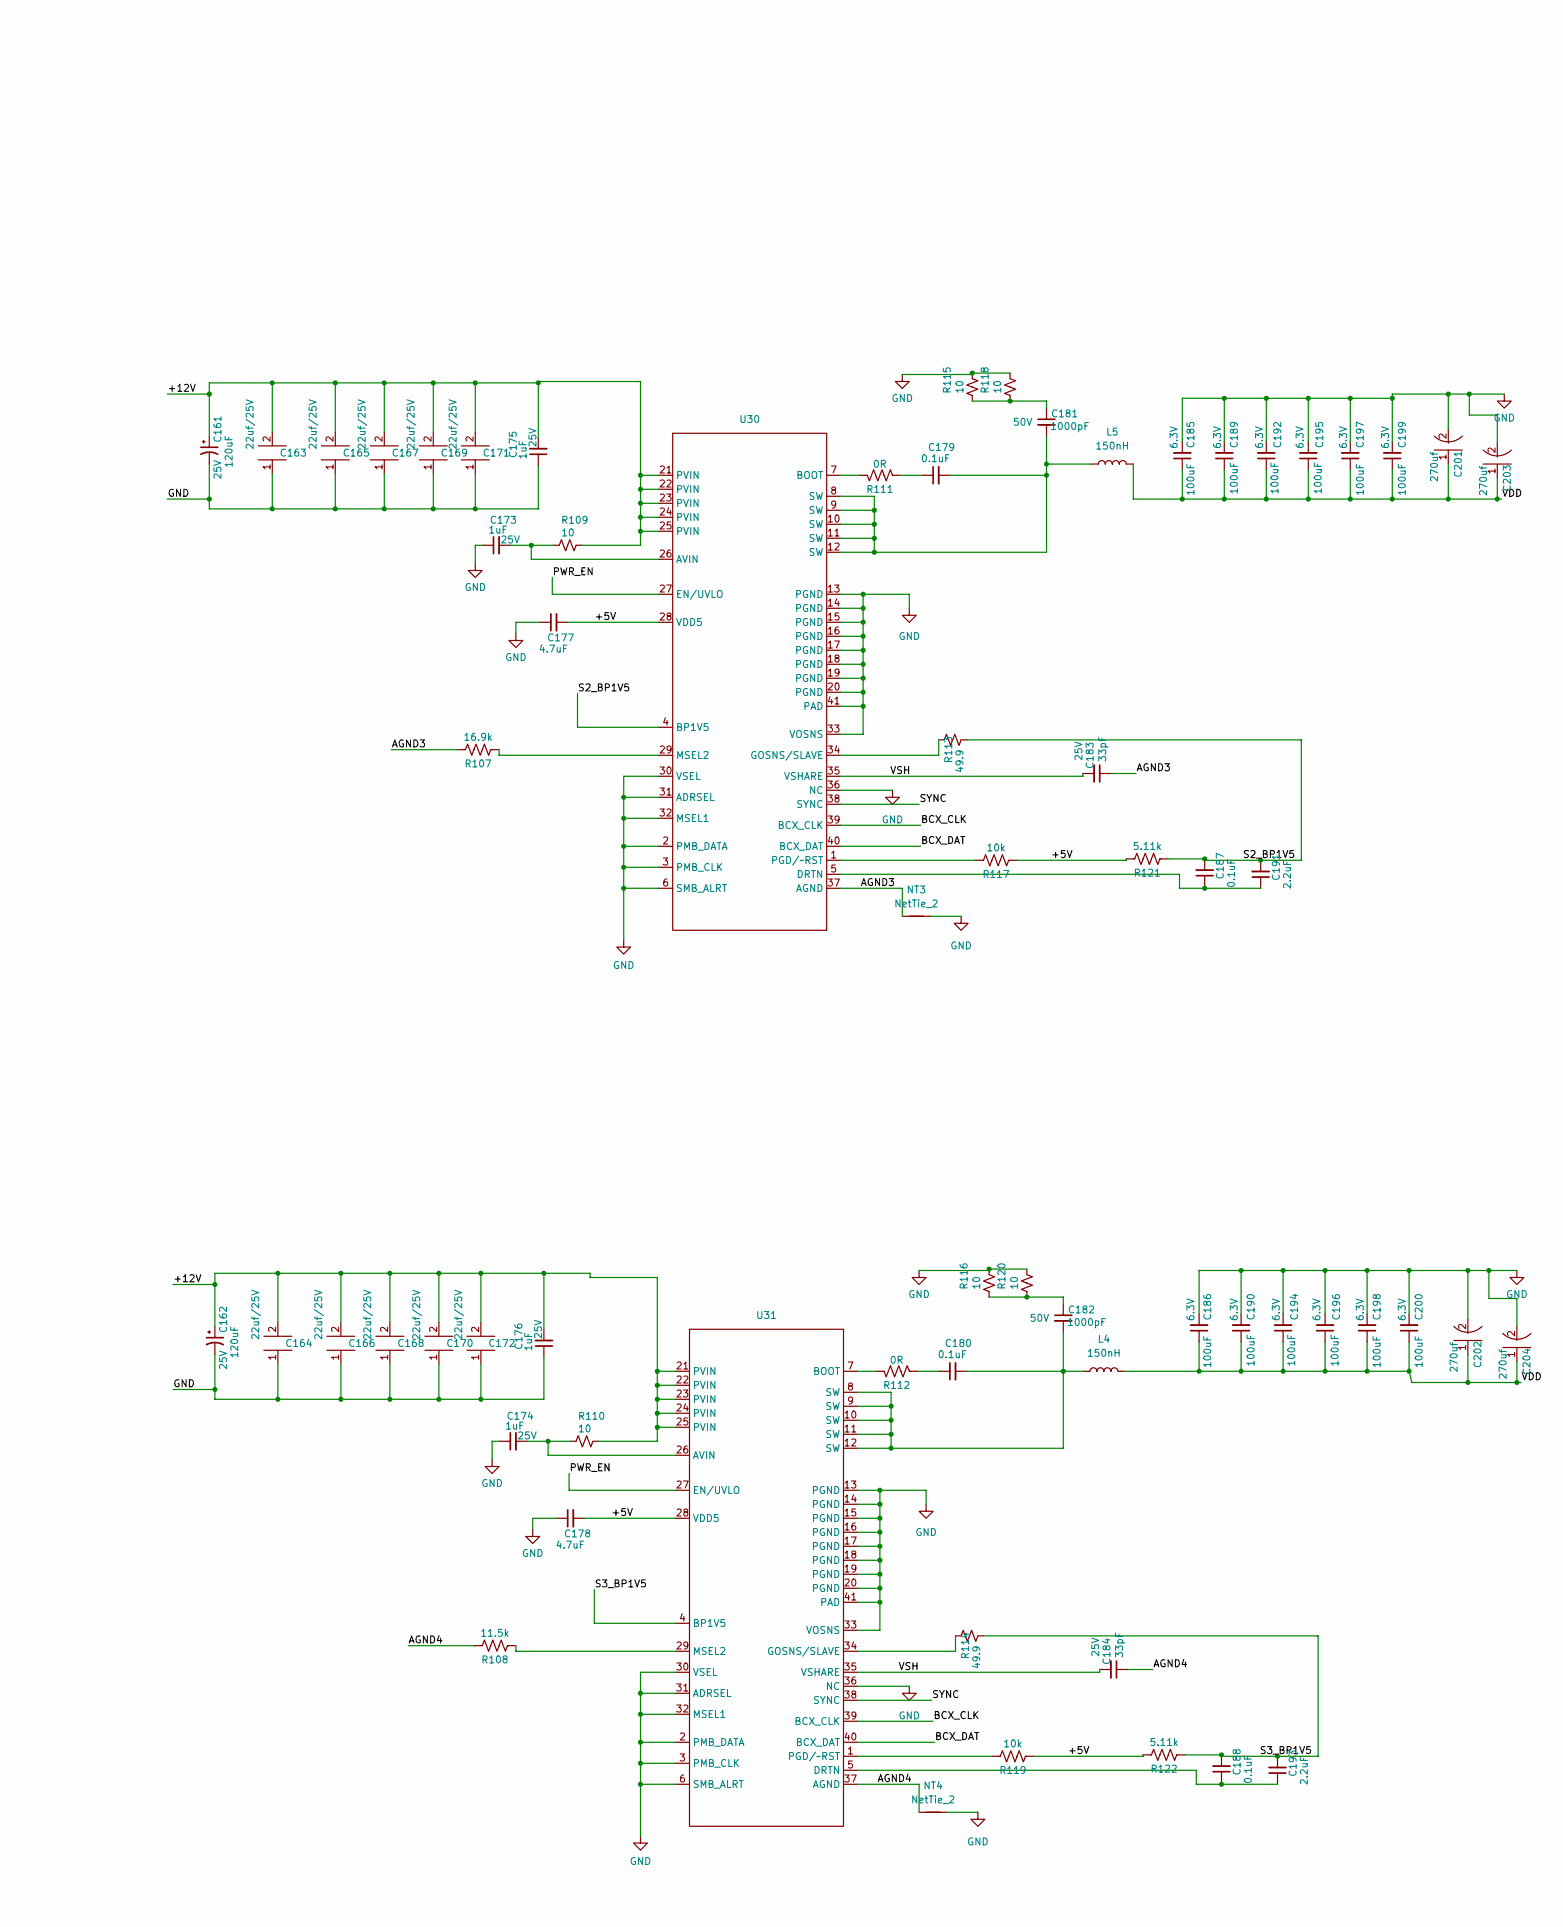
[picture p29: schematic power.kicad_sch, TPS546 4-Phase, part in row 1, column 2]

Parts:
C111, C112, C161, C162: 120uF; CP_Elec_6.3x5.9; Voltage 25V
C113, C114, C115, C116, C117, C119, C120, C121, C122, C124, C163, C164, C165, C166, C167, C168, C169, C170, C171, C172: 22uf/25V; C_0805_2012Metric
C118: 10uF; C_0603_1608Metric; Voltage 25V; PARTNO GRM188R61E106KA73D
C123, C125, C126, C128, C173, C174, C175, C176: 1uF; C_0402_1005Metric; Voltage 25V; PARTNO TMK107B7105KA-T
C127, C129, C177, C178: 4.7uF; C_0402_1005Metric; PARTNO GRM155R61A475MEAAD
C130: 10nf; C_0402_1005Metric; PARTNO GRM188R61E106KA73D
C131: 22u/16V; C_0603_1608Metric; PARTNO GRM188R61E106KA73D
C133, C134, C179, C180, C205: 0.1uF; C_0402_1005Metric; PARTNO KGM05AR71C104KH
C135, C136, C181, C182: 1000pF; C_0402_1005Metric; Voltage 50V; PARTNO CC0402JRNPO9BN101
C137, C138, C183, C184: 33pF; C_0402_1005Metric; Voltage 25V; PARTNO KGM05ACG1E330JH
C139, C142, C143, C147, C148, C150, C151, C152, C153, C154, C155, C156, C185, C186, C189, C190, C192, C194, C195, C196, C197, C198, C199, C200: 100uF; C_1206_3216Metric; Voltage 6.3V; PARTNO CL31A107MQHNNNE
C141, C144, C187, C188: 0.1uF; C_0402_1005Metric; PARTNO GRM155R61A475MEAAD
C146, C149, C191, C193: 2.2uF; C_0402_1005Metric; PARTNO GRM155R61A475MEAAD
C157, C158, C159, C160, C201, C202, C203, C204: 270uf; CP_Elec_6.3x5.9
D3: D_SOD-128
FB8: D_0201_0603Metric
L1: 4.7uH; L_Ferrocore_DLG-0703; PARTNO FTC201612S1R5MBCA
L2, L3, L4, L5: 150nH; SLC1175-271MEC_COC; PARTNO SLC1175-301
NT1, NT2, NT3, NT4: NetTie_2; NetTie-2_SMD_Pad0.2mmx1mm
R79, R83: 21.5k; R_0402_1005Metric; PARTNO RC0402JR-0710KL
R80, R84: NC; R_0402_1005Metric; PARTNO RC0402JR-0710KL
R81, R125: 10k; R_0402_1005Metric; PARTNO RC0402JR-0710KL
R82: 16.2k; R_0402_1005Metric; PARTNO RC0402JR-0710KL
R85: 4.64k; R_0402_1005Metric; PARTNO RC0402JR-0710KL
R86: 8.25k; R_0402_1005Metric; PARTNO RC0402JR-0710KL
R87: 5.36k; R_0402_1005Metric; PARTNO RC0402DR-0710KL; LCSC C471764
R88, R89, R94, R99, R100, R102, R109, R110, R115, R116, R118, R120: 10; R_0402_1005Metric; PARTNO RC0402FR-0710RL
R90: 84.5k; R_0402_1005Metric; PARTNO RC0402FR-0752K3L
R91: 16.2k; R_0402_1005Metric; PARTNO RC0402FR-0752K3L
R92, R93, R111, R112: 0R; R_0402_1005Metric; PARTNO RC0402FR-071KL; LCSC C106235
R95, R96, R97, R113, R114: 49.9; R_0402_1005Metric; PARTNO RC0402FR-0749R9L
R98, R101, R117, R119: 10k; R_0402_1005Metric; PARTNO RC0402DR-0710KL; LCSC C471764
R103, R106, R121, R122: 5.11k; R_0402_1005Metric; PARTNO RC0402DR-0710KL; LCSC C471764
R107: 16.9k; R_0402_1005Metric; PARTNO RC0402DR-0710KL; LCSC C471764
R108: 11.5k; R_0402_1005Metric; PARTNO RC0402DR-0710KL; LCSC C471764
R124: 4.7k; R_0402_1005Metric; PARTNO RC0402JR-074K7L
U27: SOT-23-6
U28, U29, U30, U31: LQFN40-CLIP

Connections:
+3V3: R124.2, U28.2 (PMB_DATA); also elsewhere on the board
+5V: C127.2, C129.2, C131.1, C177.2, C178.2, L1.2, R90.2, R98.1, R101.1, R103.2, R106.2, R117.1, R119.1, R121.2, R122.2, U28.28 (VDD5), U29.28 (VDD5), U30.28 (VDD5), U31.28 (VDD5); also elsewhere on the board
/T-Display-S3/SCL: U28.3 (PMB_CLK); also elsewhere on the board
/T-Display-S3/SMB_ALRT: R124.1, U28.6 (SMB_ALRT); also elsewhere on the board
/power1/AGND1: C137.1, NT1.2, R83.1, R84.1, R85.1, R86.1, U28.37 (AGND)
/power1/AGND2: C138.1, NT2.2, R87.2, U29.37 (AGND)
/power1/AGND3: C183.1, NT3.2, R107.2, U30.37 (AGND)
/power1/AGND4: C184.1, NT4.2, R108.2, U31.37 (AGND)
/power1/BCX_CLK: U28.39 (BCX_CLK), U29.39 (BCX_CLK), U30.39 (BCX_CLK), U31.39 (BCX_CLK)
/power1/BCX_DAT: U28.40 (BCX_DAT), U29.40 (BCX_DAT), U30.40 (BCX_DAT), U31.40 (BCX_DAT)
/power1/M_BP1V5: C141.2, C146.2, R79.2, R80.2, R81.2, R82.2, R103.1, U28.4 (BP1V5)
/power1/PWR_EN: C205.1, R125.2, U28.27 (EN/UVLO), U29.27 (EN/UVLO), U30.27 (EN/UVLO), U31.27 (EN/UVLO); also elsewhere on the board
/power1/S1_BP1V5: C144.2, C149.2, R95.2, R106.1, U29.4 (BP1V5)
/power1/S2_BP1V5: C187.2, C191.2, R113.2, R121.1, U30.4 (BP1V5)
/power1/S3_BP1V5: C188.2, C193.2, R114.2, R122.1, U31.4 (BP1V5)
/power1/SYNC: U28.38 (SYNC), U29.38 (SYNC), U30.38 (SYNC), U31.38 (SYNC)
/power1/VSH: C137.2, C138.2, C183.2, C184.2, U28.35 (VSHARE), U29.35 (VSHARE), U30.35 (VSHARE), U31.35 (VSHARE)
GND: C111.2, C112.2, C113.1, C114.1, C115.1, C116.1, C117.1, C118.2, C119.1, C120.1, C121.1, C122.1, C123.1, C124.1, C125.1, C126.1, C127.1, C128.1, C129.1, C131.2, C139.2, C142.2, C143.2, C147.2, C148.2, C150.2, C151.2, C152.2, C153.2, C154.2, C155.2, C156.2, C157.2, C158.2, C159.2, C160.2, C161.2, C162.2, C163.1, C164.1, C165.1, C166.1, C167.1, C168.1, C169.1, C170.1, C171.1, C172.1, C173.1, C174.1, C175.1, C176.1, C177.1, C178.1, C185.2, C186.2, C189.2, C190.2, C192.2, C194.2, C195.2, C196.2, C197.2, C198.2, C199.2, C200.2, C201.2, C202.2, C203.2, C204.2, C205.2, D3.2, NT1.1, NT2.1, NT3.1, NT4.1, R91.1, R94.1, R97.2, R99.1, R100.1, R102.1, R115.1, R116.1, R118.1, R120.1, R125.1, U27.2 (GND), U28.13 (PGND), U28.14 (PGND), U28.15 (PGND), U28.16 (PGND), U28.17 (PGND), U28.18 (PGND), U28.19 (PGND), U28.20 (PGND), U28.36 (NC), U28.41 (PAD), U29.2 (PMB_DATA), U29.3 (PMB_CLK), U29.6 (SMB_ALRT), U29.13 (PGND), U29.14 (PGND), U29.15 (PGND), U29.16 (PGND), U29.17 (PGND), U29.18 (PGND), U29.19 (PGND), U29.20 (PGND), U29.30 (VSEL), U29.31 (ADRSEL), U29.32 (MSEL1), U29.33 (VOSNS), U29.36 (NC), U29.41 (PAD), U30.2 (PMB_DATA), U30.3 (PMB_CLK), U30.6 (SMB_ALRT), U30.13 (PGND), U30.14 (PGND), U30.15 (PGND), U30.16 (PGND), U30.17 (PGND), U30.18 (PGND), U30.19 (PGND), U30.20 (PGND), U30.30 (VSEL), U30.31 (ADRSEL), U30.32 (MSEL1), U30.33 (VOSNS), U30.36 (NC), U30.41 (PAD), U31.2 (PMB_DATA), U31.3 (PMB_CLK), U31.6 (SMB_ALRT), U31.13 (PGND), U31.14 (PGND), U31.15 (PGND), U31.16 (PGND), U31.17 (PGND), U31.18 (PGND), U31.19 (PGND), U31.20 (PGND), U31.30 (VSEL), U31.31 (ADRSEL), U31.32 (MSEL1), U31.33 (VOSNS), U31.36 (NC), U31.41 (PAD); also elsewhere on the board
unnamed: C133.1, R92.2
unnamed: C133.2, C135.2, L2.1, U28.8 (SW), U28.9 (SW), U28.10 (SW), U28.11 (SW), U28.12 (SW)
unnamed: C134.1, R93.2
unnamed: C134.2, C136.2, L3.1, U29.8 (SW), U29.9 (SW), U29.10 (SW), U29.11 (SW), U29.12 (SW)
unnamed: C135.1, R94.2, R100.2
unnamed: C136.1, R99.2, R102.2
unnamed: C179.1, R111.2
unnamed: C179.2, C181.2, L5.1, U30.8 (SW), U30.9 (SW), U30.10 (SW), U30.11 (SW), U30.12 (SW)
unnamed: C180.1, R112.2
unnamed: C180.2, C182.2, L4.1, U31.8 (SW), U31.9 (SW), U31.10 (SW), U31.11 (SW), U31.12 (SW)
unnamed: C181.1, R115.2, R118.2
unnamed: C182.1, R116.2, R120.2
unnamed: C130.2, U27.1 (BS)
unnamed: C118.1, FB8.2, U27.4 (EN), U27.5 (IN)
unnamed: R90.1, R91.2, U27.3 (FB)
unnamed: C130.1, D3.1, L1.1, U27.6 (SW)
unnamed: R81.1, R83.2, U28.31 (ADRSEL)
unnamed: C123.2, R88.2, U28.26 (AVIN)
unnamed: R92.1, U28.7 (BOOT)
unnamed: C141.1, C146.1, U28.5 (DRTN)
unnamed: R97.1, U28.34 (GOSNS/SLAVE)
unnamed: R79.1, R85.2, U28.32 (MSEL1)
unnamed: R82.1, R86.2, U28.29 (MSEL2)
unnamed: R96.2, U28.33 (VOSNS)
unnamed: R80.1, R84.2, U28.30 (VSEL)
unnamed: C125.2, R89.2, U29.26 (AVIN)
unnamed: R93.1, U29.7 (BOOT)
unnamed: C144.1, C149.1, U29.5 (DRTN)
unnamed: R95.1, U29.34 (GOSNS/SLAVE)
unnamed: R87.1, U29.29 (MSEL2)
unnamed: R101.2, U29.1 (PGD/~RST)
unnamed: C173.2, R109.2, U30.26 (AVIN)
unnamed: R111.1, U30.7 (BOOT)
unnamed: C187.1, C191.1, U30.5 (DRTN)
unnamed: R113.1, U30.34 (GOSNS/SLAVE)
unnamed: R107.1, U30.29 (MSEL2)
unnamed: R117.2, U30.1 (PGD/~RST)
unnamed: C174.2, R110.2, U31.26 (AVIN)
unnamed: R112.1, U31.7 (BOOT)
unnamed: C188.1, C193.1, U31.5 (DRTN)
unnamed: R114.1, U31.34 (GOSNS/SLAVE)
unnamed: R108.1, U31.29 (MSEL2)
unnamed: R119.2, U31.1 (PGD/~RST)
PGOOD: R98.2, U28.1 (PGD/~RST); also elsewhere on the board
VDD: C139.1, C142.1, C143.1, C147.1, C148.1, C150.1, C151.1, C152.1, C153.1, C154.1, C155.1, C156.1, C157.1, C158.1, C159.1, C160.1, C185.1, C186.1, C189.1, C190.1, C192.1, C194.1, C195.1, C196.1, C197.1, C198.1, C199.1, C200.1, C201.1, C202.1, C203.1, C204.1, L2.2, L3.2, L4.2, L5.2, R96.1; also elsewhere on the board


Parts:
+3V3: TestPoint_Pad_D1.5mm
BO4: TestPoint_Pad_D1.5mm
C27, C28: 0.1uF; C_0402_1005Metric; PARTNO KGM05AR71C104KH
CLKO4: TestPoint_Pad_D1.5mm
CO4: TestPoint_Pad_D1.5mm
J2: Conn_01x06; PinHeader_1x06_P1.27mm_Vertical; not fitted
R5: 10k; R_0402_1005Metric; LCSC C140868
R6: 20k; R_0402_1005Metric; PARTNO RC0402FR-0720KL
RESET1: TestPoint_Pad_D1.5mm
RI4: TestPoint_Pad_D1.5mm
RSTO4: TestPoint_Pad_D1.5mm
RXD1: TestPoint_Pad_D1.5mm
TXD1: TestPoint_Pad_D1.5mm
U5: SN74AXC4T774; TSSOP-16_4.4x5mm_P0.65mm; PARTNO SN74AXC4T774BQBR

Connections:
1V2_1: C27.1, J2.1, U5.7 (DIR3), U5.8 (DIR4), U5.16 (VCCA); also elsewhere on the board
+0V8_1: J2.2; also elsewhere on the board
+3V3: +3V3.1 (1_1), C28.1, U5.15 (VCCB); also elsewhere on the board
/BM1370/CI: J2.5, U5.4 (A2); also elsewhere on the board
/BM1370/RESET: RESET1.1 (1_1), U5.14 (B1); also elsewhere on the board
/BM1370/RO: J2.4, U5.5 (A3); also elsewhere on the board
/BM1370/RST_N: J2.3, U5.3 (A1); also elsewhere on the board
/BM1370/RXD: RXD1.1 (1_1), U5.12 (B3); also elsewhere on the board
/BM1370/TXD: TXD1.1 (1_1), U5.13 (B2); also elsewhere on the board
/BM1370/bm1373_1/BI: R5.2; also elsewhere on the board
/BM1370/bm1373_4/BO: BO4.1 (1_1); also elsewhere on the board
/BM1370/bm1373_4/CLKO4: CLKO4.1 (1_1); also elsewhere on the board
/BM1370/bm1373_4/CO: CO4.1 (1_1); also elsewhere on the board
/BM1370/bm1373_4/RI: RI4.1 (1_1); also elsewhere on the board
/BM1370/bm1373_4/RSTO: RSTO4.1 (1_1); also elsewhere on the board
GND: C27.2, C28.2, J2.6, R5.1, R6.1, U5.1 (DIR1), U5.2 (DIR2), U5.6 (A4), U5.10 (GND); also elsewhere on the board
unnamed: R6.2, U5.9 (OE)

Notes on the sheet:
Direction Control HIGH= A -> B LOW = A <- B

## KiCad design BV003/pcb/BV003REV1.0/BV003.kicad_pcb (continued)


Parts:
C100, C101, C102, C103, C104, C105: 100n/0.7mm; C_0805_2012Metric; LCSC C519981
C106: 10uF; C_0603_1608Metric; PARTNO CL10A106MO8NQNC; LCSC C92487
D2: 1N5819; D_SMA; PARTNO C460770; LCSC C460770
FB4, FB5, FB6, FB7: BLM21PG221SN1D; R_0805_2012Metric; LCSC C85840
J3, J4: Conn_01x12-Socket
J5, J6: Conn_01x12-Header
M1, M2: Fan_4pin; FanPinHeader_1x04_P2.54mm_Vertical; LCSC C240840
R37, R38: 10k; R_0805_2012Metric; LCSC C140868
R39, R40, R41, R42: 2.7k; R_0805_2012Metric; LCSC C17530
RESET2: TestPoint_Pad_D1.5mm
RXD2: TestPoint_Pad_D1.5mm
TXD2: TestPoint_Pad_D1.5mm
U19: T-Display-S3; not fitted
U20: EMC2302-1; MSOP-10_3x3mm_P0.5mm; LCSC C626969
U21: TXU0102-DCU; VSSOP-8_2.3x2mm_P0.5mm; LCSC C5217871
U22, U23, U24: TMP1075; TMP1075-DRL; LCSC C3663690

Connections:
+3V3: C100.1, C101.1, C103.1, C104.1, C105.1, FB4.2, FB6.1, R37.1, R38.1, R39.1, R40.1, R40.2, R41.1, R42.1, U19.21 (GPIO44), U20.1 (SDA), U20.3 (VDD), U21.3 (VCCA), U22.5 (V+), U22.6 (SDA), U23.4 (A0), U23.5 (V+), U23.6 (SDA), U24.4 (A0), U24.5 (V+), U24.6 (SDA); also elsewhere on the board
+5V: C102.1, D2.2 (A), U21.6 (OE), U21.7 (VCCB); also elsewhere on the board
/BM1370/RESET: RESET2.1 (1_1), U19.2 (GPIO1); also elsewhere on the board
/BM1370/RXD: RXD2.1 (1_1), U19.20 (GPIO18); also elsewhere on the board
/BM1370/TXD: TXD2.1 (1_1), U19.19 (GPIO17); also elsewhere on the board
/T-Display-S3/MISO: U19.7 (GPIO12); also elsewhere on the board
/T-Display-S3/MOSI: U19.8 (GPIO13); also elsewhere on the board
/T-Display-S3/SCL: R39.2, U19.22 (GPIO43), U20.2 (SCL), U22.1 (SCL), U23.1 (SCL), U24.1 (SCL); also elsewhere on the board
/T-Display-S3/SCLK: U19.18 (GPIO21); also elsewhere on the board
/T-Display-S3/SCSN: U19.17 (GPIO16); also elsewhere on the board
/T-Display-S3/SMB_ALRT: U19.3 (GPIO2); also elsewhere on the board
/T-Display-S3/TACHO1: M1.3 (Tacho), R41.2, U20.6 (TACH1)
/T-Display-S3/TACHO2: M2.3 (Tacho), R42.2, U20.8 (TACH2)
/power1/PWR_EN: U19.5 (GPIO10); also elsewhere on the board
GND: C100.2, C101.2, C102.2, C103.2, C104.2, C105.2, C106.2, M1.1 (-), M2.1 (-), U19.11 (GND), U19.14 (GND), U19.15 (GND), U19.23 (GND), U19.24 (GND), U20.4 (GND), U21.2 (GND), U22.2 (GND), U22.4 (A0), U23.2 (GND), U24.2 (GND); also elsewhere on the board
unnamed: D2.1 (K), FB5.2
unnamed: FB4.1, U19.1 (3V)
unnamed: FB6.2, U19.13 (3V)
unnamed: C106.1, FB7.1, M1.2 (+), M2.2 (+)
unnamed: M1.4 (PWM), U21.8 (B1Y)
unnamed: M2.4 (PWM), U21.1 (B2Y)
unnamed: FB5.1, U19.12 (5V)
unnamed: R38.2, U19.4 (GPIO3)
unnamed: U20.5 (PWM1), U21.5 (A1)
unnamed: U20.7 (PWM2), U21.4 (A2)
PGOOD: R37.2, U19.6 (GPIO11); also elsewhere on the board

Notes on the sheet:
1x12 Socket for NerdQaxe+
1x12 Pinheader for T-Display-S3


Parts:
0V8_1, 1V2_1: TestPoint; TestPoint_Pad_D1.5mm
BI1: TestPoint_Pad_D1.5mm
C4: 100n/0.7mm; C_0805_2012Metric; LCSC C519981
C5, C6, C9, C16: 1uF; C_0402_1005Metric; PARTNO EMK105BJ105MV-F
C7, C8, C10, C11, C12, C13, C17, C20, C21, C23, C24, C26: 1uF; C_0402_1005Metric; PARTNO CL05A105KO5NNNC; LCSC C29266
C14, C15, C18, C19: 10uF; C_0603_1608Metric; PARTNO CL10A106MO8NQNC; LCSC C92487 Hot
C22: 33pF; C_0402_1005Metric; Voltage 25V; PARTNO KGM05ACG1E330JH
C25: 100nf; C_0402_1005Metric; PARTNO GRM188R61E106KA73D
CI1: TestPoint_Pad_D1.5mm
CLKI1: TestPoint_Pad_D1.5mm
GND1: TestPoint_Pad_D1.5mm
R1, R2, R3: 1k; R_0402_1005Metric; PARTNO RC0402FR-071KL; LCSC C106235
RO1: TestPoint_Pad_D1.5mm
RSTI1: TestPoint_Pad_D1.5mm
U1: 25MHz; Oscillator_SMD_Abracon_ASDMB-4Pin_2.5x2.0mm; LCSC C5137262
U2: MCP1824T-1202E/OT; SOT-23-5; PARTNO MCP1824T-1202E/OT
U3: B1373CC
U4: MCP1824T-0802E; SOT-23-5; PARTNO MCP1824T-0802E/OT

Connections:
1V2_1: 1V2_1.1 (1_1), C4.1, C6.2, C12.1, C23.1, U1.1 (Standby), U1.4 (VDD), U2.5 (VOUT), U3.15 (VDDIO_12_0), U3.16 (VDDIO_12_1); also elsewhere on the board
+0V8_1: 0V8_1.1 (1_1), C10.1, C16.2, C21.1, U3.14 (VDDIO_08_0), U3.17 (VDDIO_08_1), U4.5 (VOUT); also elsewhere on the board
+5V: C5.2, C9.2, U2.1 (VIN), U2.3 (EN), U4.1 (VIN), U4.3 (EN); also elsewhere on the board
/BM1370/CI: CI1.1 (1_1), U3.23 (CI); also elsewhere on the board
/BM1370/RO: RO1.1 (1_1), U3.24 (RO); also elsewhere on the board
/BM1370/RST_N: RSTI1.1 (1_1), U3.22 (RSTI); also elsewhere on the board
/BM1370/bm1373_1/BI: BI1.1 (1_1), U3.26 (BI); also elsewhere on the board
/BM1370/bm1373_1/BO: U3.5 (BO); also elsewhere on the board
/BM1370/bm1373_1/CLKI: CLKI1.1 (1_1), U1.3 (Out), U3.25 (CLKI)
/BM1370/bm1373_1/CO: U3.8 (CO); also elsewhere on the board
/BM1370/bm1373_1/RI: U3.7 (RI); also elsewhere on the board
/BM1370/bm1373_1/RSTO: U3.9 (RSTO); also elsewhere on the board
GND: C4.2, C5.1, C6.1, C9.1, C10.2, C12.2, C13.2, C14.2, C15.2, C16.1, C17.1, C18.2, C19.2, C21.2, C22.1, C23.2, C25.1, GND1.1 (1_1), R1.2, R2.2, R3.2, U1.2 (GND), U2.2 (GND), U3.13 (GND), U3.18 (GND), U3.19 (GND), U3.32 (VDD1), U4.2 (GND); also elsewhere on the board
unnamed: R3.1, U3.12 (NC)
unnamed 110: U3.6 (CLKO); also elsewhere on the board
unnamed: R1.1, U3.10 (LITE_PAD)
unnamed: R2.1, U3.11 (PIN_MODE)
unnamed: C11.2, C13.1, U3.1 (VDD1_0)
unnamed: C17.2, C20.1, U3.30 (VDD1_1)
unnamed: C8.2, C11.1, U3.2 (VDD2_0)
unnamed: C20.2, C24.1, U3.29 (VDD2_1)
unnamed: C7.2, C8.1, U3.3 (VDD3_0)
unnamed: C24.2, C26.1, U3.28 (VDD3_1)
VDD1: C7.1, C14.1, C15.1, C18.1, C19.1, C22.2, C25.2, C26.2, U3.31 (VDD); also elsewhere on the board


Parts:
0V8_3, 1V2_3: TestPoint; TestPoint_Pad_D1.5mm
BI3: TestPoint_Pad_D1.5mm
C52, C54, C55, C56: 1uF; C_0402_1005Metric; PARTNO EMK105BJ105MV-F
C53: 100n/0.7mm; C_0805_2012Metric; LCSC C519981
C57, C58, C59, C60, C61, C62, C65, C68, C69, C71, C72, C74: 1uF; C_0402_1005Metric; PARTNO CL05A105KO5NNNC; LCSC C29266
C63, C64, C66, C67: 10uF; C_0603_1608Metric; PARTNO CL10A106MO8NQNC; LCSC C92487 Hot
C70: 33pF; C_0402_1005Metric; Voltage 25V; PARTNO KGM05ACG1E330JH
C73: 100nf; C_0402_1005Metric; PARTNO GRM188R61E106KA73D
CI3: TestPoint_Pad_D1.5mm
CLKI3: TestPoint_Pad_D1.5mm
R11, R12, R13: 1k; R_0402_1005Metric; PARTNO RC0402FR-071KL; LCSC C106235
RO3: TestPoint_Pad_D1.5mm
RSTI3: TestPoint_Pad_D1.5mm
U10: 25MHz; Oscillator_SMD_Abracon_ASDMB-4Pin_2.5x2.0mm; LCSC C5137262
U11: MCP1824T-1202E/OT; SOT-23-5; PARTNO MCP1824T-1202E/OT
U12: MCP1824T-0802E; SOT-23-5; PARTNO MCP1824T-0802E/OT
U13: B1373CC
VDD2: TestPoint_Pad_D1.5mm

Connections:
+0V8_3: 0V8_3.1 (1_1), C56.2, C59.1, C69.1, U12.5 (VOUT), U13.14 (VDDIO_08_0), U13.17 (VDDIO_08_1)
+1V2_3: 1V2_3.1 (1_1), C53.1, C54.2, C61.1, C71.1, U10.1 (Standby), U10.4 (VDD), U11.5 (VOUT), U13.15 (VDDIO_12_0), U13.16 (VDDIO_12_1)
+5V: C52.2, C55.2, U11.1 (VIN), U11.3 (EN), U12.1 (VIN), U12.3 (EN); also elsewhere on the board
/BM1370/bm1373_3/BO: U13.5 (BO); also elsewhere on the board
/BM1370/bm1373_3/CO: U13.8 (CO); also elsewhere on the board
/BM1370/bm1373_3/RI: U13.7 (RI); also elsewhere on the board
/BM1370/bm1373_3/RSTO: U13.9 (RSTO); also elsewhere on the board
/BM1370/bm1373_3/level_shifter/BI2: BI3.1 (1_1), U13.26 (BI); also elsewhere on the board
/BM1370/bm1373_3/level_shifter/CI2: CI3.1 (1_1), U13.23 (CI); also elsewhere on the board
/BM1370/bm1373_3/level_shifter/NRSTI2: RSTI3.1 (1_1), U13.22 (RSTI); also elsewhere on the board
/BM1370/bm1373_3/level_shifter/RO2: RO3.1 (1_1), U13.24 (RO); also elsewhere on the board
unnamed: R13.1, U13.12 (NC)
unnamed: CLKI3.1 (1_1), U10.3 (Out), U13.25 (CLKI)
unnamed 131: U13.6 (CLKO); also elsewhere on the board
unnamed: R11.1, U13.10 (LITE_PAD)
unnamed: R12.1, U13.11 (PIN_MODE)
unnamed: C60.2, C62.1, U13.1 (VDD1_0)
unnamed: C65.2, C68.1, U13.30 (VDD1_1)
unnamed: C58.2, C60.1, U13.2 (VDD2_0)
unnamed: C68.2, C72.1, U13.29 (VDD2_1)
unnamed: C57.2, C58.1, U13.3 (VDD3_0)
unnamed: C72.2, C74.1, U13.28 (VDD3_1)
VDD2: C52.1, C53.2, C54.1, C55.1, C56.1, C59.2, C61.2, C62.2, C63.2, C64.2, C65.1, C66.2, C67.2, C69.2, C70.1, C71.2, C73.1, R11.2, R12.2, R13.2, U10.2 (GND), U11.2 (GND), U12.2 (GND), U13.13 (GND), U13.18 (GND), U13.19 (GND), U13.32 (VDD1), VDD2.1 (1_1); also elsewhere on the board
VDD3: C57.1, C63.1, C64.1, C66.1, C67.1, C70.2, C73.2, C74.2, U13.31 (VDD); also elsewhere on the board


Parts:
0V8_2, 1V2_2: TestPoint; TestPoint_Pad_D1.5mm
BI2: TestPoint_Pad_D1.5mm
C29: 100n/0.7mm; C_0805_2012Metric; LCSC C519981
C30, C31, C32, C33: 1uF; C_0402_1005Metric; PARTNO EMK105BJ105MV-F
C34, C35, C36, C37, C38, C39, C42, C45, C46, C48, C49, C51: 1uF; C_0402_1005Metric; PARTNO CL05A105KO5NNNC; LCSC C29266
C40, C41, C43, C44: 10uF; C_0603_1608Metric; PARTNO CL10A106MO8NQNC; LCSC C92487 Hot
C47: 33pF; C_0402_1005Metric; Voltage 25V; PARTNO KGM05ACG1E330JH
C50: 100nf; C_0402_1005Metric; PARTNO GRM188R61E106KA73D
CI2: TestPoint_Pad_D1.5mm
CLKI2: TestPoint_Pad_D1.5mm
R7, R8, R9: 1k; R_0402_1005Metric; PARTNO RC0402FR-071KL; LCSC C106235
R10: 10k; R_0402_1005Metric; PARTNO RC0402DR-0710KL; LCSC C471764
RO2: TestPoint_Pad_D1.5mm
RSTI2: TestPoint_Pad_D1.5mm
U6: 25MHz; Oscillator_SMD_Abracon_ASDMB-4Pin_2.5x2.0mm; LCSC C5137262
U7: MCP1824T-1202E/OT; SOT-23-5; PARTNO MCP1824T-1202E/OT
U8: MCP1824T-0802E; SOT-23-5; PARTNO MCP1824T-0802E/OT
U9: B1373CC
VDD1: TestPoint_Pad_D1.5mm

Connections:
+0V8_2: 0V8_2.1 (1_1), C33.2, C36.1, C46.1, U8.5 (VOUT), U9.14 (VDDIO_08_0), U9.17 (VDDIO_08_1)
+1V2_2: 1V2_2.1 (1_1), C29.1, C31.2, C38.1, C48.1, U6.1 (Standby), U6.4 (VDD), U7.5 (VOUT), U9.15 (VDDIO_12_0), U9.16 (VDDIO_12_1)
+5V: C30.2, C32.2, U7.1 (VIN), U7.3 (EN), U8.1 (VIN), U8.3 (EN); also elsewhere on the board
/BM1370/bm1373_2/BO: U9.22 (BO); also elsewhere on the board
/BM1370/bm1373_2/CO: U9.25 (CO); also elsewhere on the board
/BM1370/bm1373_2/RI: U9.24 (RI); also elsewhere on the board
/BM1370/bm1373_2/RSTO: R10.1, U9.26 (RST); also elsewhere on the board
/BM1370/bm1373_2/level_shifter/BI2: BI2.1 (1_1), U9.9 (BI); also elsewhere on the board
/BM1370/bm1373_2/level_shifter/CI2: CI2.1 (1_1), U9.6 (CI); also elsewhere on the board
/BM1370/bm1373_2/level_shifter/NRSTI2: RSTI2.1 (1_1), U9.5 (RSTI); also elsewhere on the board
/BM1370/bm1373_2/level_shifter/RO2: RO2.1 (1_1), U9.7 (RO); also elsewhere on the board
unnamed: R9.1, U9.12 (NC)
unnamed: R10.2, U9.27 (VSS)
unnamed: CLKI2.1 (1_1), U6.3 (Out), U9.8 (CLKI)
unnamed 121: U9.23 (CLKO); also elsewhere on the board
unnamed: R7.1, U9.10 (LITE_PAD)
unnamed: R8.1, U9.11 (PIN_MODE)
unnamed: C37.2, C39.1, U9.1 (VDD1_0)
unnamed: C42.2, C45.1, U9.30 (VDD1_1)
unnamed: C35.2, C37.1, U9.2 (VDD2_0)
unnamed: C45.2, C49.1, U9.29 (VDD2_1)
unnamed: C34.2, C35.1, U9.3 (VDD3_0)
unnamed: C49.2, C51.1, U9.28 (VDD3_1)
VDD1: C29.2, C30.1, C31.1, C32.1, C33.1, C36.2, C38.2, C39.2, C40.2, C41.2, C42.1, C43.2, C44.2, C46.2, C47.1, C48.2, C50.1, R7.2, R8.2, R9.2, U6.2 (GND), U7.2 (GND), U8.2 (GND), U9.13 (GND), U9.18 (GND), U9.32 (VDD1), VDD1.1 (1_1); also elsewhere on the board
VDD2: C34.1, C40.1, C41.1, C43.1, C44.1, C47.2, C50.2, C51.2, U9.31 (VDD2); also elsewhere on the board


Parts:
0V8_4, 1V2_4: TestPoint; TestPoint_Pad_D1.5mm
BI4: TestPoint_Pad_D1.5mm
C75: 100n/0.7mm; C_0805_2012Metric; LCSC C519981
C76, C77, C78, C79: 1uF; C_0402_1005Metric; PARTNO EMK105BJ105MV-F
C80, C81, C82, C83, C84, C85, C88, C91, C92, C94, C95, C97: 1uF; C_0402_1005Metric; PARTNO CL05A105KO5NNNC; LCSC C29266
C86, C87, C89, C90: 10uF; C_0603_1608Metric; PARTNO CL10A106MO8NQNC; LCSC C92487 Hot
C93: 33pF; C_0402_1005Metric; Voltage 25V; PARTNO KGM05ACG1E330JH
C96: 100nf; C_0402_1005Metric; PARTNO GRM188R61E106KA73D
CI4: TestPoint_Pad_D1.5mm
CLKI4: TestPoint_Pad_D1.5mm
R15, R16, R17: 1k; R_0402_1005Metric; PARTNO RC0402FR-071KL; LCSC C106235
R18, R123: 10k; R_0402_1005Metric; PARTNO RC0402DR-0710KL; LCSC C471764
RO4: TestPoint_Pad_D1.5mm
RSTI4: TestPoint_Pad_D1.5mm
U14: 25MHz; Oscillator_SMD_Abracon_ASDMB-4Pin_2.5x2.0mm; LCSC C5137262
U15: MCP1824T-1202E/OT; SOT-23-5; PARTNO MCP1824T-1202E/OT
U16: MCP1824T-0802E; SOT-23-5; PARTNO MCP1824T-0802E/OT
U17: B1373CC
VDD3: TestPoint_Pad_D1.5mm

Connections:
+0V8_4: 0V8_4.1 (1_1), C79.2, C82.1, C92.1, U16.5 (VOUT), U17.14 (VDDIO_08_0), U17.17 (VDDIO_08_1)
+1V2_4: 1V2_4.1 (1_1), C75.1, C77.2, C84.1, C94.1, R123.1, U14.1 (Standby), U14.4 (VDD), U15.5 (VOUT), U17.15 (VDDIO_12_0), U17.16 (VDDIO_12_1)
+5V: C76.2, C78.2, U15.1 (VIN), U15.3 (EN), U16.1 (VIN), U16.3 (EN); also elsewhere on the board
/BM1370/bm1373_4/BO: U17.22 (BO); also elsewhere on the board
/BM1370/bm1373_4/CLKO4: U17.23 (CLKO); also elsewhere on the board
/BM1370/bm1373_4/CO: U17.25 (CO); also elsewhere on the board
/BM1370/bm1373_4/RI: R123.2, U17.24 (RI); also elsewhere on the board
/BM1370/bm1373_4/RSTO: R18.1, U17.26 (RST); also elsewhere on the board
/BM1370/bm1373_4/level_shifter/BI2: BI4.1 (1_1), U17.9 (BI); also elsewhere on the board
/BM1370/bm1373_4/level_shifter/CI2: CI4.1 (1_1), U17.6 (CI); also elsewhere on the board
/BM1370/bm1373_4/level_shifter/NRSTI2: RSTI4.1 (1_1), U17.5 (RSTI); also elsewhere on the board
/BM1370/bm1373_4/level_shifter/RO2: RO4.1 (1_1), U17.7 (RO); also elsewhere on the board
unnamed: R17.1, U17.12 (NC)
unnamed: R18.2, U17.27 (VSS)
unnamed: CLKI4.1 (1_1), U14.3 (Out), U17.8 (CLKI)
unnamed: R15.1, U17.10 (LITE_PAD)
unnamed: R16.1, U17.11 (PIN_MODE)
unnamed: C83.2, C85.1, U17.1 (VDD1_0)
unnamed: C88.2, C91.1, U17.30 (VDD1_1)
unnamed: C81.2, C83.1, U17.2 (VDD2_0)
unnamed: C91.2, C95.1, U17.29 (VDD2_1)
unnamed: C80.2, C81.1, U17.3 (VDD3_0)
unnamed: C95.2, C97.1, U17.28 (VDD3_1)
VDD: C80.1, C86.1, C87.1, C89.1, C90.1, C93.2, C96.2, C97.2, U17.31 (VDD4); also elsewhere on the board
VDD3: C75.2, C76.1, C77.1, C78.1, C79.1, C82.2, C84.2, C85.2, C86.2, C87.2, C88.1, C89.2, C90.2, C92.2, C93.1, C94.2, C96.1, R15.2, R16.2, R17.2, U14.2 (GND), U15.2 (GND), U16.2 (GND), U17.13 (GND), U17.18 (GND), U17.32 (VDD3), VDD3.1 (1_1); also elsewhere on the board

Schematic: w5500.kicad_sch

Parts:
C132: 0.1uF; C_0402_1005Metric; PARTNO GRM155R61A475MEAAD
C140: 100nf; C_0402_1005Metric; PARTNO GRM188R61E106KA73D
C145, C215: 10uF; C_0603_1608Metric; PARTNO CL10A106MO8NQNC; LCSC C92487 Hot
C206, C209, C210, C211, C212, C213: 0.1uF; C_0603_1608Metric; PARTNO CL10A106MO8NQNC; LCSC C92487 Hot
C207, C214, C216, C217: 10nf; C_0402_1005Metric; PARTNO GRM188R61E106KA73D
C208: 4.7uF; C_0402_1005Metric; PARTNO GRM155R61A475MEAAD
C218: 22nf; C_0402_1005Metric; PARTNO GRM188R61E106KA73D
FB9: D_0201_0603Metric
J7: RJ45_Hanrun_HR911105A_Horizontal
MISO1: TestPoint_Pad_D1.5mm
MOSI1: TestPoint_Pad_D1.5mm
R4: 1k; R_0402_1005Metric; PARTNO RC0402FR-071KL; LCSC C106235
R14: 10k; R_0402_1005Metric; PARTNO RC0402FR-071KL; LCSC C106235
R31: 10k; R_0402_1005Metric; PARTNO RC0402FR-072KL; LCSC C60488
R55: 12.4k; R_0402_1005Metric; PARTNO RC0402FR-072KL; LCSC C60488
R73, R104, R105, R126: 0R; R_0402_1005Metric; PARTNO RC0402FR-071KL; LCSC C106235
R127, R128, R129, R130: 49R9; R_0402_1005Metric; PARTNO RC0402FR-071KL; LCSC C106235
R131: 10R; R_0402_1005Metric; PARTNO RC0402FR-071KL; LCSC C106235
R132, R133: 0.33k; R_0402_1005Metric; PARTNO RC0402FR-071KL; LCSC C106235
RD+1: TestPoint_Pad_D1.5mm
RD-1: TestPoint_Pad_D1.5mm
SCLK1: TestPoint_Pad_D1.5mm
SCSN1: TestPoint_Pad_D1.5mm
TXN1: TestPoint_Pad_D1.5mm
TXP1: TestPoint_Pad_D1.5mm
U32: 25MHz; Oscillator_SMD_EuroQuartz_XO32-4Pin_3.2x2.5mm; PARTNO SX3M25.000E20F30THN
U33: W5500; LQFP-48_7x7mm_P0.5mm

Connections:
1V2_1: C207.2, U33.22 (1V2O); also elsewhere on the board
+3V3: C140.2, C145.1, FB9.2, J7.9, J7.12, R14.1, R31.2, R128.1, R129.1, R131.1, U32.1 (Standby), U32.4 (VDD); also elsewhere on the board
/T-Display-S3/MISO: MISO1.1, U33.34 (MISO); also elsewhere on the board
/T-Display-S3/MOSI: MOSI1.1, U33.35 (MOSI); also elsewhere on the board
/T-Display-S3/SCLK: SCLK1.1, U33.33 (SCLK); also elsewhere on the board
/T-Display-S3/SCSN: SCSN1.1, U33.32 (~SCS); also elsewhere on the board
/T-Display-S3/w5500/ACTLED: R133.2, U33.27 (ACTLED)
/T-Display-S3/w5500/LINKLED: R132.2, U33.25 (LINKLED)
AVDD: C206.1, C209.1, C210.1, C211.1, C212.1, C213.1, C215.1, FB9.1, U33.4 (AVDD), U33.8 (AVDD), U33.11 (AVDD), U33.15 (AVDD), U33.17 (AVDD), U33.21 (AVDD)
GND: C132.1, C206.2, C207.1, C208.1, C209.2, C210.2, C211.2, C212.2, C213.2, C214.1, C215.2, C218.1, J7.SH, R55.1, U32.2 (GND), U33.3 (AGND), U33.9 (AGND), U33.14 (AGND), U33.16 (AGND), U33.19 (AGND), U33.29 (GND), U33.43 (PMODE2), U33.44 (PMODE1), U33.45 (PMODE0), U33.48 (AGND); also elsewhere on the board
unnamed: C132.2, R4.1, R14.2
unnamed: C216.2, R126.2, R127.1
unnamed: C217.2, R105.2, R130.1
unnamed: J7.10, R133.1
unnamed: J7.11, R132.1
unnamed: C214.2, J7.5 (RCT), R127.2, R130.2
unnamed: C216.1, J7.3 (RD+), RD+1.1 (1_1)
unnamed: C217.1, J7.6 (RD-), RD-1.1 (1_1)
unnamed: C218.2, J7.4 (TCT), R131.2
unnamed: J7.1 (TD+), R104.2, R129.2, TXP1.1 (1_1)
unnamed: J7.2 (TD-), R73.2, R128.2, TXN1.1 (1_1)
unnamed: U32.3 (Out), U33.30 (XI/CLKIN)
unnamed: R55.2, U33.10 (EXRES1)
unnamed: R105.1, U33.5 (RXN)
unnamed: R126.1, U33.6 (RXP)
unnamed: C208.2, U33.20 (TOCAP)
unnamed: R73.1, U33.1 (TXN)
unnamed: R104.1, U33.2 (TXP)
unnamed: C140.1, C145.2, U33.28 (VDD)
unnamed: R31.1, U33.36 (~INT)
unnamed: R4.2, U33.37 (~RST)

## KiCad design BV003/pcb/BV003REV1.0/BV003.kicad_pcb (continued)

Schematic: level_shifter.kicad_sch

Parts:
C98: 0.1uF; C_0402_1005Metric; PARTNO KGM05AR71C104KH
C99: 1uF; C_0402_1005Metric; PARTNO EMK105BJ105MV-F
R19, R22, R25, R28, R32, R33, R34, R35, R36: 1k; R_0402_1005Metric; PARTNO RC0402FR-071KL
R20, R21, R23, R24, R26, R27, R29, R30: 10k; R_0402_1005Metric; PARTNO RC0402JR-0710KL
U18: TLV3544; TSSOP-14_4.4x5mm_P0.65mm; PARTNO TLV3544IPWR

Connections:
+5V: C98.2, C99.2, U18.4 (V+); also elsewhere on the board
/BM1370/bm1373_3/BO: R27.1; also elsewhere on the board
/BM1370/bm1373_3/CO: R21.1; also elsewhere on the board
/BM1370/bm1373_3/RI: R36.1; also elsewhere on the board
/BM1370/bm1373_3/RSTO: R24.1; also elsewhere on the board
/BM1370/bm1373_4/level_shifter/BI2: R34.1, U18.8; also elsewhere on the board
/BM1370/bm1373_4/level_shifter/CI2: R32.1, U18.1; also elsewhere on the board
/BM1370/bm1373_4/level_shifter/NRSTI2: R33.1, U18.7; also elsewhere on the board
/BM1370/bm1373_4/level_shifter/RO2: R30.1; also elsewhere on the board
unnamed: R35.1, R36.2, U18.14
unnamed: R20.1, R21.2, U18.3 (+)
unnamed: R19.1, R32.2, U18.2 (-)
unnamed: R23.2, R24.2, U18.5 (+)
unnamed: R22.1, R33.2, U18.6 (-)
unnamed: R26.2, R27.2, U18.10 (+)
unnamed: R25.1, R34.2, U18.9 (-)
unnamed: R29.2, R30.2, U18.12 (+)
unnamed: R28.1, R35.2, U18.13 (-)
VDD: R20.2, R23.1, R26.1; also elsewhere on the board
VDD2: C98.1, C99.1, R29.1, U18.11 (V-); also elsewhere on the board
VDD3: R19.2, R22.2, R25.2, R28.2; also elsewhere on the board

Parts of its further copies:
C107, C109: 0.1uF; C_0402_1005Metric; PARTNO KGM05AR71C104KH
C108, C110: 1uF; C_0402_1005Metric; PARTNO EMK105BJ105MV-F
R43, R46, R49, R52, R56, R57, R58, R59, R60, R61, R64, R67, R70, R74, R75, R76, R77, R78: 1k; R_0402_1005Metric; PARTNO RC0402FR-071KL
R44, R45, R47, R48, R50, R51, R53, R54, R62, R63, R65, R66, R68, R69, R71, R72: 10k; R_0402_1005Metric; PARTNO RC0402JR-0710KL
U25, U26: TLV3544; TSSOP-14_4.4x5mm_P0.65mm; PARTNO TLV3544IPWR

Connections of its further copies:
+5V: C107.2, C108.2, C109.2, C110.2, U25.4 (V+), U26.4 (V+); also elsewhere on the board
/BM1370/bm1373_1/BO: R51.1; also elsewhere on the board
/BM1370/bm1373_1/CO: R45.1; also elsewhere on the board
/BM1370/bm1373_1/RI: R60.1; also elsewhere on the board
/BM1370/bm1373_1/RSTO: R48.1; also elsewhere on the board
/BM1370/bm1373_2/BO: R69.1; also elsewhere on the board
/BM1370/bm1373_2/CO: R63.1; also elsewhere on the board
/BM1370/bm1373_2/RI: R78.1; also elsewhere on the board
/BM1370/bm1373_2/RSTO: R66.1; also elsewhere on the board
/BM1370/bm1373_2/level_shifter/BI2: R58.1, U25.8; also elsewhere on the board
/BM1370/bm1373_2/level_shifter/CI2: R56.1, U25.1; also elsewhere on the board
/BM1370/bm1373_2/level_shifter/NRSTI2: R57.1, U25.7; also elsewhere on the board
/BM1370/bm1373_2/level_shifter/RO2: R54.1; also elsewhere on the board
/BM1370/bm1373_3/level_shifter/BI2: R76.1, U26.8; also elsewhere on the board
/BM1370/bm1373_3/level_shifter/CI2: R74.1, U26.1; also elsewhere on the board
/BM1370/bm1373_3/level_shifter/NRSTI2: R75.1, U26.7; also elsewhere on the board
/BM1370/bm1373_3/level_shifter/RO2: R72.1; also elsewhere on the board
GND: C107.1, C108.1, R53.1, U25.11 (V-); also elsewhere on the board
unnamed: R59.1, R60.2, U25.14
unnamed: R77.1, R78.2, U26.14
unnamed: R44.1, R45.2, U25.3 (+)
unnamed: R43.1, R56.2, U25.2 (-)
unnamed: R47.2, R48.2, U25.5 (+)
unnamed: R46.1, R57.2, U25.6 (-)
unnamed: R50.2, R51.2, U25.10 (+)
unnamed: R49.1, R58.2, U25.9 (-)
unnamed: R53.2, R54.2, U25.12 (+)
unnamed: R52.1, R59.2, U25.13 (-)
unnamed: R62.1, R63.2, U26.3 (+)
unnamed: R61.1, R74.2, U26.2 (-)
unnamed: R65.2, R66.2, U26.5 (+)
unnamed: R64.1, R75.2, U26.6 (-)
unnamed: R68.2, R69.2, U26.10 (+)
unnamed: R67.1, R76.2, U26.9 (-)
unnamed: R71.2, R72.2, U26.12 (+)
unnamed: R70.1, R77.2, U26.13 (-)
VDD1: C109.1, C110.1, R43.2, R46.2, R49.2, R52.2, R71.1, U26.11 (V-); also elsewhere on the board
VDD2: R44.2, R47.1, R50.1, R61.2, R64.2, R67.2, R70.2; also elsewhere on the board
VDD3: R62.2, R65.1, R68.1; also elsewhere on the board

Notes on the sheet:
OPAMP Bypass

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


Board: 4 copper layers, 200.0 x 190.0 mm, 457 parts (285 on the bottom side), 224 nets.

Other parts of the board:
C220, C221, C222, C223: 330uf; CP_EIA-7343-31_Kemet-D_Pad2.25x2.55mm_HandSolder
CLKO1, CLKO2, CLKO3: TestPoint_Pad_D1.5mm
GND2: TestPoint_Pad_D1.5mm
H1, H2: MountingHole_Pad; MountingHole_3.2mm_M3_Pad_Via
R134, R135: 10k; R_0402_1005Metric

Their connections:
/BM1370/bm1373_1/RSTO: R134.2; also elsewhere on the board
/BM1370/bm1373_3/RSTO: R135.2; also elsewhere on the board
GND: C220.2, GND2.1 (1_1), H1.1 (1_1), H2.1 (1_1), R134.1; also elsewhere on the board
unnamed 110: CLKO1.1 (1_1); also elsewhere on the board
unnamed 121: CLKO2.1 (1_1); also elsewhere on the board
unnamed 131: CLKO3.1 (1_1); also elsewhere on the board
VDD: C223.1; also elsewhere on the board
VDD1: C220.1, C221.2; also elsewhere on the board
VDD2: C221.1, C222.2, R135.1; also elsewhere on the board
VDD3: C222.1, C223.2; also elsewhere on the board

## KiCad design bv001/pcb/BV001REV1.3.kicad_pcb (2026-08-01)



Board: 6 copper layers, 89.0 x 165.0 mm, 156 parts (42 on the bottom side), 79 nets.

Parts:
C1: 2.2nF; C_0402_1005Metric
C2, C4, C9, C18, C109, C149, C150, C164, C165: 1nF; C_0402_1005Metric
C3: 12pF; C_0402_1005Metric
C5: 330nF; C_0402_1005Metric
C6, C8, C34, C37, C58, C58#2, C64, C67, C70, C72, C74, C76, C78, C80, C94, C105, C108: 1µF; C_0402_1005Metric
C7: 4.7µF; C_0402_1005Metric
C10, C14, C87, C96, C101, C102, C103, C107, C141, C147, C156, C162: 100nF; C_0402_1005Metric
C12, C142, C157: 2.2µF; C_0402_1005Metric
C18#2, C20: 10uF; C_0805_2012Metric
C22, C48, C81, C81#2, C81#3, C84, C86, C110, C111, C113, C117, C121, C122, C124, C125, C127, C130: 10uF; C_0603_1608Metric
C22#2: 10nf; C_0402_1005Metric
C59, C100: 0.1uF; C_0402_1005Metric
C62: 100pF; C_0402_1005Metric
C62#2: 100nf; C_0402_1005Metric
C88: 33pf; C_0402_1005Metric
C114, C115, C116: 22pF; C_0402_1005Metric
C119, C119#2, C120: 10µF; C_0603_1608Metric
C179, C182, C188, C192, C196, C197, C199, C202, C203: 100µF; C_1206_3216Metric
D1: 5KPxxA; D_SMB
D2: D_SOD-128
D3: 1N5819; D_SOD-123
FB1: FB0603
FID1, FID2, FID3, FID4: Fiducial_1mm_Mask2mm
H1, H2, H3, H4, H5, H6: MountingHole_Pad; MountingHole_3.2mm_M3_Pad_Via
J1: XT30; XT30PW-M
JP3: SolderJumper_2_Open; SolderJumper-2_P1.3mm_Open_RoundedPad1.0x1.5mm
L1, L5#2, L6: 220nH; IFLR-4031GC-01-8x10
L5: 4.7uH; L_Changjiang_FTC201612S
M1, M2: Fan_4pin; FanPinHeader_1x04_P2.54mm_Vertical
R1: 16.5k; R_0402_1005Metric
R2: 24.3k; R_0402_1005Metric
R3: 66.5k; R_0402_1005Metric
R4: 100k; R_0402_1005Metric
R5: 121k; R_0402_1005Metric
R6: 8.06k; R_0402_1005Metric
R7: 2.55k; R_0402_1005Metric
R8, R17: 4.7k; R_0402_1005Metric
R10, R11, R14, R15, R25, R27: 1R/0.5w; R_0805_2012Metric
R12, R13: 2.2R; R_0402_1005Metric
R13#2: 84.5k; R_0402_1005Metric
R14#2: 16.2k; R_0402_1005Metric
R21, R21#2, R22, R31, R36, R37, R38: 10k; R_0402_1005Metric
R26: 20k; R_0402_1005Metric
R33, R35: 2.7k; R_0402_1005Metric
R39, R40: 100R; R_0402_1005Metric
R44, R44#2, R47: 1k; R_0402_1005Metric
U3: TPS53647; Texas_RHA0040B_VQFN-40-1EP_6x6mm_P0.5mm_EP4.15x4.15mm_Therm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
U4, U9, U10: CSD95472Q5MC; CSD95472-SON-5x6
U5: B1373CC
U6: SN74AVC4T774; TSSOP-16_4.4x5mm_P0.65mm
U7: MCP1824T-0802E; SOT-23-5
U8: 25MHz; Oscillator_SMD_EuroQuartz_XO32-4Pin_3.2x2.5mm
U14: SOT-23-6
U30: T-Display-S3
U32: EMC2302-1; MSOP-10_3x3mm_P0.5mm
U33: TXU0102-DCU; VSSOP-8_2.3x2mm_P0.5mm
U36: MCP1824T-1202E; SOT-23-5
U37, U38: TMP1075; TMP1075-DRL

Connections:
+0V8: C34.2, C37.2, C105.1, U5.14 (VDDIO_08_0), U5.17 (VDDIO_08_1), U7.5 (VOUT)
+1V2: C58.1, C58#2.1, C59.1, C64.1, C108.1, R21.2, U5.15 (VDDIO_12_0), U5.16 (VDDIO_12_1), U6.1 (DIR1), U6.8 (DIR4), U6.16 (VCCA), U8.1 (Standby), U8.4 (VDD), U36.5 (VOUT)
+3V3: C62#2.2, C87.1, C100.1, C101.1, C102.1, C103.1, C107.1, JP3.2 (B), R8.2, R17.2, R33.1, R35.1, R36.1, R37.1, U3.6 (CSP4), U6.15 (VCCB), U7.1 (VIN), U30.1 (3V), U30.13 (3V), U32.3 (VDD), U33.3 (VCCA), U36.1 (VIN), U37.5 (V+), U38.4 (A0), U38.5 (V+)
+5V: C96.1, C119.1, C119#2.1, C120.1, D3.2 (A), L5.2, R10.1, R13.1, R13#2.2, R14.1, R25.1, U33.6 (OE), U33.7 (VCCB)
+12V: C22.1, C48.1, C84.1, C110.1, C111.1, C113.1, C117.1, C121.1, C122.1, C124.1, C125.1, C130.1, D1.1 (A1), FB1.1, J1.1 (+V), M1.2 (+), M2.2 (+), R12.1, U4.7 (VIN), U9.7 (VIN), U10.7 (VIN)
+VRef: C3.2, C4.2, C5.1, C10.1, C141.1, C156.1, R1.2, R7.1, U3.13 (VREF), U4.2 (REFIN), U9.2 (REFIN), U10.2 (REFIN)
/BM1366/BI: R21#2.2, U5.9 (BI)
/BM1366/RESET: U6.12 (B3), U30.2 (GPIO1)
/BM1366/RXD: U6.14 (B1), U30.20 (GPIO18)
/BM1366/TXD: U6.13 (B2), U30.19 (GPIO17)
/Power/FCCM: R4.2, U3.39 (/SKIP-NVM), U4.10 (FCCM), U9.10 (FCCM), U10.10 (FCCM)
/Power/LDO_EN: R31.1, U7.3 (EN), U30.8 (GPIO13), U36.3 (EN)
/Power/PWR_EN: C9.1, R38.1, U3.23 (ENABLE), U30.5 (GPIO10)
/Power/TPS_CSP1: U3.3 (CSP1), U4.1 (IOUT)
/Power/TPS_CSP2: U3.4 (CSP2), U9.1 (IOUT)
/Power/TPS_CSP3: JP3.1 (A), U3.5 (CSP3), U10.1 (IOUT)
/Power/TPS_PWM1: U3.38 (PWM1), U4.12 (PWM)
/Power/TPS_PWM2: U3.37 (PMW2), U9.12 (PWM)
/Power/TPS_PWM3: U3.36 (PMW3), U10.12 (PWM)
/Power/TPS_TSEN: C2.1, C109.1, C150.1, C165.1, R5.2, U3.40 (TSEN), U4.11 (TAO/FAULT), U9.11 (TAO/FAULT), U10.11 (TAO/FAULT)
/Power/VR_RDY: R36.2, U3.18 (VR_RDY), U30.6 (GPIO11)
/Power//RESET: R37.2, U3.21 (/RESET)
/T-Display-S3/SCL: R8.1, U3.24 (PMB_CLK), U30.22 (GPIO43), U32.2 (SCL), U37.1 (SCL), U38.1 (SCL)
/T-Display-S3/SDA: R17.1, U3.26 (PMB_DIO), U30.21 (GPIO44), U32.1 (SDA), U37.6 (SDA), U38.6 (SDA)
/T-Display-S3/TACHO1: M1.3 (Tacho), R33.2, U32.6 (TACH1)
/T-Display-S3/TACHO2: M2.3 (Tacho), R35.2, U32.8 (TACH2)
CI-N: U5.6 (CI), U6.4 (A2)
CLK-N: U5.8 (CLKI), U8.3 (Out)
GND: C1.2, C2.2, C5.2, C6.2, C7.1, C8.1, C9.2, C10.2, C12.2, C18.2, C18#2.2, C20.2, C22.2, C34.1, C37.1, C48.2, C58.2, C58#2.2, C59.2, C62.2, C62#2.1, C64.2, C72.2, C80.2, C81.2, C81#2.2, C81#3.2, C84.2, C86.2, C87.2, C88.2, C96.2, C100.2, C101.2, C102.2, C103.2, C105.2, C107.2, C108.2, C109.2, C110.2, C111.2, C113.2, C115.1, C116.2, C117.2, C119.2, C119#2.2, C120.2, C121.2, C122.2, C124.2, C125.2, C127.2, C130.2, C141.2, C142.2, C149.2, C150.2, C156.2, C157.2, C164.2, C165.2, C179.2, C182.2, C188.2, C192.2, C196.2, C197.2, C199.2, C202.2, C203.2, D1.2 (A2), D2.2, H1.1, H2.1, H3.1, H4.1, H5.1, H6.1, J1.2 (GND), M1.1 (-), M2.1 (-), R2.1, R3.1, R4.1, R5.1, R14#2.1, R21#2.1, R26.1, R31.2, R38.2, R40.1, R44.2, R44#2.2, R47.2, U3.17 (GND), U3.20 (GND), U3.22 (GND), U3.41 (EP), U4.4 (PGND), U4.13 (PGND), U5.13 (GND), U5.18 (GND), U5.32 (VDD1), U6.2 (DIR2), U6.6 (A4), U6.7 (DIR3), U6.10 (GND), U7.2 (GND), U8.2 (GND), U9.4 (PGND), U9.13 (PGND), U10.4 (PGND), U10.13 (PGND), U14.2 (GND), U30.11 (GND), U30.14 (GND), U30.15 (GND), U30.23 (GND), U30.24 (GND), U32.4 (GND), U33.2 (GND), U36.2 (GND), U37.2 (GND), U37.4 (A0), U38.2 (GND)
MODE1: R47.1, U5.10 (LITE_PAD)
MODE2: R44#2.1, U5.11 (PIN_MODE)
MODE3: R44.1, U5.12 (NC)
unnamed: C4.1, R6.1
unnamed: C18.1, R27.1
unnamed: C149.1, R11.1
unnamed: C164.1, R15.1
unnamed: D3.1 (K), U30.12 (5V)
unnamed: M1.4 (PWM), U33.8 (B1Y)
unnamed: M2.4 (PWM), U33.1 (B2Y)
unnamed: R1.1, R2.2, U3.28 (ADDR_TRISE)
unnamed: C3.1, R6.2, U3.11 (COMP)
unnamed: C1.1, R3.2, U3.2 (IMON)
unnamed: R7.2, U3.12 (ISUM)
unnamed: C6.1, U3.14 (V3R3)
unnamed: C7.2, R13.2, U3.15 (V5)
unnamed: C8.2, R12.2, U3.16 (VIN)
unnamed: C114.2, C116.1, R40.2, U3.10 (VSN)
unnamed: C114.1, C115.2, R39.2, U3.9 (VSP)
unnamed: C14.1, U4.9 (BOOT)
unnamed: C14.2, U4.8 (BOOT_R)
unnamed: C12.1, R25.2, U4.3 (ENABLE), U4.5 (VDD)
unnamed: L1.1, R27.2, U4.6 (VSW)
unnamed: R26.2, U6.9 (OE)
unnamed: C147.1, U9.9 (BOOT)
unnamed: C147.2, U9.8 (BOOT_R)
unnamed: C142.1, R10.2, U9.3 (ENABLE), U9.5 (VDD)
unnamed: L5#2.1, R11.2, U9.6 (VSW)
unnamed: C162.1, U10.9 (BOOT)
unnamed: C162.2, U10.8 (BOOT_R)
unnamed: C157.1, R14.2, U10.3 (ENABLE), U10.5 (VDD)
unnamed: L6.1, R15.2, U10.6 (VSW)
unnamed: C22#2.2, U14.1 (BS)
unnamed: C127.1, FB1.2, U14.4 (EN), U14.5 (IN)
unnamed: R13#2.1, R14#2.2, U14.3 (FB)
unnamed: C18#2.1, C20.1, C22#2.1, D2.1, L5.1, U14.6 (SW)
unnamed: U32.5 (PWM1), U33.5 (A1)
unnamed: U32.7 (PWM2), U33.4 (A2)
RI-1.2: R21.1, U5.24 (RI)
RO-N: U5.7 (RO), U6.3 (A1)
RST-0: R22.2, U5.26 (RST)
RST-N: U5.5 (RSTI), U6.5 (A3)
VDD: C62.1, C74.1, C81.1, C81#2.1, C81#3.1, C86.1, C88.1, C94.2, C179.1, C182.1, C188.1, C192.1, C196.1, C197.1, C199.1, C202.1, C203.1, L1.2, L5#2.2, L6.2, R39.1, U5.31 (VDD)
VDD1_0: C70.2, C72.1, U5.1 (VDD1_0)
VDD1_1: C78.1, C80.1, U5.30 (VDD1_1)
VDD2_0: C67.2, C70.1, U5.2 (VDD2_0)
VDD2_1: C76.2, C78.2, U5.29 (VDD2_1)
VDD3_0: C67.1, C94.1, U5.3 (VDD3_0)
VDD3_1: C74.2, C76.1, U5.28 (VDD3_1)
VSS: R22.1, U5.27 (VSS)

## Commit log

2026-07-18 首次提交
    [BQB0016A.stp, BV002.xlsx, BV1.2.kicad_sch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]
2026-07-20 add REV1.3
    [BQB0016A.stp, BV1.3.kicad_sch, BV1.kicad_pcb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]
2026-07-20 add rev1.3 bom
    [BV002REV1.3.xlsx]
2026-07-20 add bv001
    [BV001.kicad_pcb, BV001bom.csv]
2026-07-24 Reposition warning about untested prototype in README
    Removed the warning about the prototype being untested from the first section and added it again at the end.
2026-08-01 Adjusted the file structure, removed a large number of unnecessary files, and uploaded the untested BV003REV1.0
    [BQB0016A.stp, BV001-fix.kicad_pcb, BV001.kicad_pcb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]
2026-08-01 Add a declaration for BV001
    [BV001.csv]
2026-08-01 add BV003 bom
    [BV003.xlsx]
2026-08-20 Release of BV002REV1.5 and related BOM
    [BQB0016A.stp, BV002REV1.5-bom.xlsx, BV002REV1.5.kicad_pcb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]
